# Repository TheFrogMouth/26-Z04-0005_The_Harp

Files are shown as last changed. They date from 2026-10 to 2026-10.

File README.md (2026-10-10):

# 26-Z04-0005 — The Harp

Frogmouth digital sympathetic-string guitar pedal. Up to 24 modelled strings
that nobody plays ring when the guitar sounds their note, retuned continuously
to the chord being played. STM32H750VBT6, AK4621EF codec, no SDRAM, relay
bypass, in a Hammond 125B on the Alchemist/Relic board and jack layout.

Status: **first schematic draft, board placed and mostly routed, 29 connections open.** Seven sheets generated from the Timekeeper's circuits and The Relic's bypass (190 parts, net-traced, drawn to the Frogmouth schematic standard, not yet opened in KiCad); board outline and 28 face/jack/bypass footprints placed from The Relic. Stereo in (TRS) and a 0.91 in OLED display added 2026-10-08; the PCB was synced to the schematic and every part placed on both sides on 2026-10-08 (scripted; one-board fit confirmed, see `docs/pcb-plan.md` *Placement*). First routing pass by script on 2026-10-09: GND to In1 and rails on In2 from every pad, analog and digital kept apart. Opened in KiCad 2026-10-10 (now the source of truth): power section re-placed and re-routed, every track at the Alchemist widths and at 0/45/90°, 29 connections left for KiCad (*Routing*). See `docs/pcb-plan.md` and `kicad/README.md`.

## Layout

| Path | Contents |
|---|---|
| `docs/design-brief.md` | What the pedal is, engine, controls, bypass, cost target, decisions, open items |
| `docs/pcb-plan.md` | One-board plan and two-board fallback, face schedule, zoning, schematic sheets, pin budget, order of work |
| `docs/firmware-requirements.md` | Firmware requirements (draft): audio path, engine, controls, display, bypass, persistence, budgets, verification |
| `kicad/the_harp/` | KiCad 10 project: seven-sheet schematic, Relic-outline board |
| `Gerbers/` | Fabrication output, when generated |
| `firmware/the_harp/` | STM32H750 firmware |
| `Documents/` | Controlled LaTeX documents, one folder each |
| `bom/` | Generated BOM (`scripts/export_bom.py`, to be adapted from The Relic) |
| `scripts/harp_schematic/` | Schematic generator and net checker (first draft only; see its README) |
| `scripts/pcb_placement/` | PCB sync to the schematic and scripted placement (2026-10-08; see its README) |
| `scripts/oled_drawings/` | Face cut-out and OLED-to-PCB drawings in `docs/images/` |

The layout is the Frogmouth product repository standard
(`docs/repo-structure.md` in 26-F01-0001_Frogmouth).

## Conventions

Same as The Relic and The Alchemist: enclosure centre is the PCB drill/place
and grid origin at (148.5, 105); face X right, face Y up; jacks on the board
underside at the Alchemist's positions and heights; pots on the board;
momentary footswitches wired to pads; relay true bypass.

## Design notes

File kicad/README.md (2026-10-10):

# KiCad project — The Harp

`the_harp/` is the KiCad 10 project. The board was seeded from The Relic
(2026-10-04); the schematic is **generated** by
`scripts/harp_schematic/build_layout.py` from the circuits of the Timekeeper
DSP board and The Relic's relay bypass (`harp_spec.py`) and a hand layout per
sheet (`layouts/`), drawn to the Frogmouth schematic standard
(`docs/schematic-standard.md` in 26-F01-0001_Frogmouth, 2026-10-07). Nothing
here has been opened in KiCad yet: run ERC first.

## Sheets

| Sheet | File |
|---|---|
| Root | `The Harp.kicad_sch` |
| Controls and LEDs | `Controls and LEDs.kicad_sch` |
| MCU (STM32H750VBT6, W25Q128) | `MCU.kicad_sch` |
| Power | `Power.kicad_sch` |
| Jacks and Bypass | `Jacks and Bypass.kicad_sch` |
| Codec (AK4621EF) | `Codec.kicad_sch` |
| ADC Driver (THS4522) | `ADC Driver.kicad_sch` |
| Analog In and Out (OPA1656, OPA1688) | `Analog In and Out.kicad_sch` |

What each sheet holds, the pin map and the deliberate differences from the
Timekeeper are in `docs/pcb-plan.md`. The Relic's `Power and IO` sheet is
gone: its relay bypass is redrawn on Jacks and Bypass with the same
designators, and its regulators are replaced by the Timekeeper's buck and LDO.

## Board

The Relic's 56 × 90 mm outline with the DC tab, four-layer stack, GND zone
and 125B guides. 26 footprints are placed: the four pots, three toggles, the
effect LED, the five jacks (DC, IN, OUT L, OUT R, EXP), the relay and its
driver, the effect-LED driver and the bypass footswitch pads. The four
1/4 in jacks and the relay were replaced on 2026-10-05 with The Alchemist's
NMJ6HCD2 and G6K-2F-Y footprints at its positions. On 2026-10-06 the face
moved to The Alchemist's layout: RV104 and RV106 removed, the three toggles
on the Taiway 100-DP6 footprint at (−20, +13), (0, −5) and (+20, +13) (Retune moved to (0, −24) on 2026-10-09), the
bypass footswitch on hand-solder pads, and R405 / D402 moved off J403's
rear pads. The Relic's
regulator parts (C401–C407, D401, R401–R403, U401, U402) were removed. On
2026-10-08 the board was synced to the schematic (see step 2 below): every
footprint is linked to its symbol with its pad nets, the twelve note LEDs
and their resistors are gone. All 181 footprints were then placed on the
top side by script (`scripts/pcb_placement/`, `docs/pcb-plan.md` *Placement*).

## First steps in KiCad

1. Open `The Harp.kicad_pro`, open every sheet once, run ERC. Expect
   cosmetic warnings (label placement, overlapping text); anything about
   power pins or unconnected pins is real, report it.
2. The board was synced to the schematic on 2026-10-08 without KiCad (no
   KiCad in that session): 181 footprints (190 symbol units), each linked to its symbol, values
   and pad nets checked pin by pin against `harp_spec.py`. Run Tools → Update PCB from
   Schematic once anyway: it should report no changes apart from net
   renames (KiCad names unlabelled nets `Net-(...)`) and footprint library
   refreshes. Anything else it reports is a sync miss: note it.
3. Every part is placed on both sides (scripted, 2026-10-08; see *Placement*
   in `docs/pcb-plan.md`). Look it over, then run DRC.
4. The board was routed by script on 2026-10-09 (`scripts/pcb_routing/`,
   *Routing* in `docs/pcb-plan.md`): GND vias per the Relic rule, rails on
   In2. On 2026-10-10 the power section was re-placed and re-routed and
   every track brought to the Alchemist widths (0.254 / 0.508 / 0.762 /
   1.0 mm, digital 0.1524) and to 0/45/90°. Fill the In1 GND zone (B), finish the 29 open
   connections listed there, then DRC. The net classes (GND, Rail, Power,
   Audio, Digital, Control, clearance 0.1524) are in the project.

Once the schematic has been edited in KiCad, the KiCad files are the source
of truth; do not re-run the generator over them (see
`scripts/harp_schematic/README.md`).

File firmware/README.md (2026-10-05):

# Firmware

`the_harp/` will hold the STM32H750VBT6 firmware (string bank, chord tracker,
tuning manager). The engine is prototyped first on the Timekeeper board
(`25-Z01-0001_DSP_Development_Board/firmware/dsp_development_board`), then
ported with the Harp pin map. See `docs/design-brief.md` for the engine and
`docs/firmware-requirements.md` for what the firmware must do.

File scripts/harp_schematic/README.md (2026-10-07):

# Schematic generator

Writes the Harp's KiCad 10 schematic from a plain Python description of the
circuit (`harp_spec.py`) and a hand layout per sheet (`layouts/`), in the
style of `docs/schematic-standard.md` in 26-F01-0001_Frogmouth: every
connection inside a sheet is a wire, global labels only for nets that leave
the sheet, a power symbol at each rail and ground point, Oswald on every
font, power symbols numbered uniquely across the project, and a coloured
block diagram on the top sheet.

| File | What it is |
|---|---|
| `harp_spec.py` | The circuit: every part, its value, footprint, manufacturer part number and the net on each pin, sheet by sheet |
| `schgen.py` | Writes `.kicad_sch` files: each pin gets a 2.54 mm stub and a power symbol, a global label (net on more than one sheet) or a local label; unused pins get a no-connect flag |
| `kisch.py` | Minimal schematic reader and net tracer, used to check the output |
| `build_layout.py` | **The build.** Runs the sheet layouts into `kicad/the_harp/`, numbers the power symbols, writes the top sheet, then re-reads every sheet, traces the nets and compares them pin by pin with the spec, and runs the layout checks |
| `layout.py` | The layout engine: places parts on the grid, draws wires, power symbols, labels and no-connects, splits wires at the pins they meet, adds junctions, and checks for dangling wires, wires through bodies, overlapping wires, crossings and overlapping text |
| `layouts/<sheet>.py` | One hand layout per sheet (`power.py`, `mcu.py`, ...); `layouts/common.py` has the shared helpers |
| `top_sheet.py` | The top sheet: sheet blocks coloured by domain, domain frames, connection lines, legend, and the embedded title block and Oswald fonts (copied from The Relic's top sheet) |
| `render_png.py` | Preview renderer (Pillow, no KiCad needed): `python3 render_png.py SHEET.kicad_sch out.png [px_per_mm]`. Set `FONT_DIR` to a folder with `Oswald-Regular.ttf` / `Oswald-Bold.ttf` for the real face |
| `build.py` | The first-draft generator (every pin on a labelled stub); superseded by `build_layout.py`, kept for reference |
| `symbols.sexpr` | The 34 symbol definitions used, copied from the Timekeeper, Relic and Alchemist schematics and KiCad's `STM32H750VBTx` |
| `libcollect.py`, `h750vb.kicad_sym` | Only needed to rebuild `symbols.sexpr` (delete it and run `build.py` with the sibling repos checked out next to this one) |

```bash
python3 scripts/harp_schematic/build_layout.py          # every sheet and the top sheet
python3 scripts/harp_schematic/build_layout.py Power    # one sheet (no power renumbering, no top sheet)
# Power   parts 24 wires 65 junctions 20 crossings 0 netlist OK layout OK
```

`netlist OK` means every pin is on the net the spec gives it, every rail
and global net carries its name, no node holds two nets, and no local
label is used except the ones a layout declares in `allow_local` (the MCU
sheet: `QSPI_CLK` and `QSPI_NCS`, whose ends sit on opposite sides of the
MCU). Each crossing is listed; a sheet should have none or very few.

Sheet and symbol UUIDs are derived from the sheet name and reference, so a
rebuild keeps the links to the PCB.

**The generator owns the schematic only until someone edits it in KiCad.**
After that, the KiCad files are the source of truth and running `build_layout.py`
would overwrite those edits. Use it again only for a deliberate full
regeneration, with the spec and the layouts updated to match.

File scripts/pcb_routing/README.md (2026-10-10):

# PCB routing scripts

Used on 2026-10-09 to route `kicad/the_harp/The Harp.kicad_pcb` without
KiCad: the board goes to Freerouting as a Specctra DSN, one net class at a
time, and the session comes back into the board file as tracks and vias.
Once the board has been edited in KiCad, KiCad is the source of truth:
rerun these only for a deliberate restart (they replace every track and via).

| File | What it does |
|---|---|
| `route.py` | Runs the phases in order (below) and writes `build/routes.json`. With phase names, reruns those on top of the rest. |
| `fanout.py` | Gives every SMD pad of a net set its own via and a straight stub (GND and the rails). |
| `regions.py` | The audio and digital regions per layer, from where the pads are; used as keepouts. |
| `dsn.py` | Writes the DSN (each footprint its own image, pads pre-rotated, earlier phases protected) and reads the SES. |
| `nets.py` | Net classes: what each net is, its width and clearance, the via. |
| `write_tracks.py` | Replaces the board's tracks and vias with `build/routes.json`. |
| `check.py` | Stand-in for DRC: connectivity (GND through the plane), clearances per class, copper to edge, hole to hole. |
| `render.py` | Draws F.Cu, B.Cu and In2.Cu with tracks coloured by class. |
| `netclasses.py` | Writes the same classes into `The Harp.kicad_pro` (one pattern per net) for KiCad's DRC and router. |
| `kpcb.py` | Board-file reader: footprints, pads in board coordinates, outline. |
| `power.py` | Places and routes the power section (y < 70) by hand, in code: the DC input row, the LDO row, the buck's feedback divider; 0/45/90 only. Keeps the owner's buck placement. Safe to rerun on a KiCad-saved board: it only replaces the power nets' copper above y = 70. |
| `rail.py` | Joins the open pieces of one rail (`rail.py +5V`): octilinear A* on In2.Cu, hopping onto F/B with a via pair where another rail is in the way. |
| `widths.py` | Brings every track to its class width (stepping down where the clearance will not allow it) and every segment to 0/45/90. Safe to rerun. |
| `fill.py`, `smooth.py` | Grid maze router for the connections Freerouting left open, and a straightener for its staircases (2026-10-09; not used since). |

Widths are the Alchemist's: 1.0 (DC input, SW), 0.762 (rails, local power),
0.508 (GND stubs, VDDA), 0.254 (audio, control), 0.1524 (digital, 6 mil as
on the DSP board), NRST 0.1016; clearance 0.1524.

Phases (`route.py`):

1. **gnd**: every SMD GND pad gets its own via to the In1.Cu plane (Relic
   rule). ICs put the via under the package, two-pin parts off the free end.
2. **rails**: every SMD pad on +3V3, +5V, +9V gets its own via; Freerouting
   joins the vias on In2.Cu, the only layer the rails may use.
3. **power**: local power nets (buck, LDO, DC input, VDDA, relay coil, LED
   current), wide, F/B.
4. **core**: digital round the MCU (codec interface, QSPI, crystal, SWD,
   OLED, reset), kept out of the audio region.
5. **audio**: kept out of the digital region; before the long digital lines
   so the bypass paths get the corridors under the MCU to the relay.
6. **drive**: the LED and relay drive lines to the bottom-side drivers, kept
   out of the audio region.
7. **ctrl**: pots, toggles, footswitches, expression (DC), kept out of the
   audio region.
8. **repair**: anything still open, without the region keepouts and with the
   signal tracks unlocked so the router can move them; GND, rail and power
   copper stays fixed.

Signals never use In2.Cu; vias cost more than Freerouting's default (80
against 50), so a track changes side rarely; much higher and it takes long
one-sided detours instead. No via within 0.6 mm of the SWD needle pads.

Needs Java 25 and Freerouting 2.4.1 (`app.freerouting:freerouting`,
`freerouting-2.4.1-executable.jar` from Maven Central), plus Python with
shapely, numpy, scipy and matplotlib:

```bash
cd scripts/pcb_routing
FREEROUTING=/path/freerouting-2.4.1-executable.jar JAVA=/path/java25 python3 route.py
python3 write_tracks.py && python3 check.py && python3 render.py
```

Freerouting quirks found on the way: any `autoroute_settings` block in the
DSN makes it see nothing to route (so per-layer costs are not used; In2 is
reserved by net class instead), and with an In1 plane declared it counts GND
as done and will not fan it out (so `fanout.py` does that). A full run takes
about an hour and a half on four cores. The 2026-10-09 run left 32
connections open (`docs/pcb-plan.md`, *Routing*).

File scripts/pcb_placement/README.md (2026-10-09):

# PCB sync and placement scripts

Used on 2026-10-08 to do, without KiCad, what *Update PCB from Schematic*
and a first placement pass would do. They edit
`kicad/the_harp/The Harp.kicad_pcb` in place. Once the board has been
edited in KiCad, KiCad is the source of truth: rerun these only for a
deliberate restart.

| File | What it does |
|---|---|
| `sync_pcb.py` | Brings the board in line with `harp_spec.py`: removes footprints no longer in the schematic, adds new ones (cloned from footprints already on this board or the Timekeeper's), sets values and pad nets, links each footprint to its schematic symbol. New parts are parked off the board. |
| `run_place.py` | Places every part on its group's side: fixed face parts stay, U201 goes at (0, −7) (option 1: under the OLED; Retune toggle at (0, −24)), each group gets a home position and each passive the nearest free spot to the pads it connects to (decoupling first, bias nets ignored, anti-alias caps at the codec pins). Avoids courtyards on its side, through-holes from the other side, the board edge and, for tall parts, the OLED module. Writes `build/pos.json`. |
| `write_pos.py` | Writes `build/pos.json` into the board file: position, rotation and side (flips a footprint as KiCad does). |
| `verify.py` | Re-reads the board file: courtyard overlaps per side, parts on through-holes from the other side, parts outside the outline, tall parts under the OLED, and that every pad sits where the placer put it. |
| `metrics.py` | Key net lengths and the total, for comparing runs. |
| `render_place.py` | Draws the placement: `CHROME=/path/to/chrome python3 render_place.py ../../docs/images/pcb-placement`. |
| `place.py`, `geom.py`, `pcbread.py` | Shared helpers: footprint geometry, the placer, board-file and spec readers. |

```bash
cd scripts/pcb_placement
python3 run_place.py && python3 write_pos.py && python3 verify.py
```

The placement is greedy and deterministic. Its result and its weak spots
are written up in `docs/pcb-plan.md`, *Placement*.

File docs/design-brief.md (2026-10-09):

# The Harp — design brief

Working title. Project number to be assigned. Written 2026-10-04 from the
concept discussion. Companion to `pcb-plan.md` (board, placement and
schematic sheet plan). Format follows The Relic's `docs/design-brief.md`.

## What it is

A sympathetic-string pedal. Behind the guitar sit up to 24 digitally
modelled strings that nobody plays: they ring when the guitar sounds a note
they are tuned to, as the taraf strings of a sitar or the under-strings of a
Hardanger fiddle do. The pedal listens to the chord being played and keeps
retuning the strings to it, so every note leaves a halo that is in the
player's own harmony. Tuned ambience, not reverb and not shimmer.

The category neighbours are Hologram Microcosm, Chase Bliss Mood and the
Strymon ambience pedals (300 to 450 EUR). Nothing in that category does
chord-following sympathetic strings.

## Why this hardware

The Harp is a cut-down Timekeeper on the Alchemist/Relic 125B hardware set:

- Same codec, flash, buck converter, input and output stages and relay
  bypass as the Timekeeper and the Relic, so the schematic is mostly copied.
- **No SDRAM.** The 24 strings need about 100 KB of delay memory; the
  STM32H750 has 1 MB internal. This removes the external memory bus and
  about 60 pins of MCU.
- **STM32H750VBT6, LQFP-100** instead of the Timekeeper's LQFP-144. Same
  core, same firmware, new pin map.
- **No TFT.** A thin 0.91 in 128×32 I²C OLED strip replaces the screen (decision 14, 2026-10-08).
- **Pots, not encoders.** Encoders only make sense with a screen that shows
  the value; the Timekeeper has one, this does not. Pots also keep the
  Relic's parts and feel. The H750 reads the four of them on ADC1 PA0,
  PA1, PA2 and PA4, with the DMA scan the Timekeeper's `controls.c`
  already runs.
- **Jacks and DC jack in the Alchemist's positions and heights.** See
  `pcb-plan.md`; this is the main reason the design is one board.

## Signal path

```
IN tip -> relay -> input buffer -> ADC (codec L) -> H750: chord tracker
                                                       string bank x24  -> DAC L -> out buffer -> relay -> OUT L
                                                       dry + wet mix    -> DAC R -> out buffer -> relay -> OUT R
IN ring -> input buffer -> ADC (codec R) -> H750 (mono plug: copy L)
EXP (TRS) -> buffer -> H750 ADC
```

Stereo in, stereo out, single-ended at every jack. IN is one TRS jack,
tip = left, ring = right; both channels are buffered (OPA2365 halves) and
driven into the AK4621EF's differential inputs by the two channels of the
THS4522, exactly as the Timekeeper does. A mono plug shorts the ring to the
sleeve, so the right channel reads silence; the firmware copies left to
right until the right channel carries signal. The relay isolates the left
input only, the right is muted by the DSP in true bypass. The dry signal goes through the codec: the
pedal's whole point is the wet sound, and converting the dry keeps the mix,
trails and output level in firmware. Latency is one block (about 6 ms at
44.1 kHz / 256 samples, as the Timekeeper).

## Engine

| Block | What it does | Reuse |
|---|---|---|
| String bank | 24 Karplus-Strong / waveguide strings, each a fractional delay line with a one-pole loss filter and an allpass for tuning. Guitar signal feeds each string through a narrow resonant band-pass at the string's pitch so a string only rings when its note or an overtone is played. No envelope trigger. | New |
| Jawari | Nonlinear bridge: a soft clip plus a short extra delay tap in the loop, depth on the Jawari knob. Zero is a harp, full is a sitar. | New |
| Chord tracker | FFT of the input (the Timekeeper's spectral bank already has the analysis), chroma vector, template match to a chord set with hysteresis. Only chords that last more than ~400 ms retune the strings. | Timekeeper spectral |
| Tuning manager | Assigns string pitches from the chord (Follow), a fixed key (Key) or an open tuning set (Drone, stacked fifths among the sets). Snap retunes only silent strings; Glide slides sounding strings to the new pitch; Lock stops retuning. | New |
| Stereo spread | Strings panned low-left to high-right. | New |
| Front end | Hum filter and noise gate before the strings. | Timekeeper |
| Framework | Effect chain, presets in QSPI flash, control smoothing, expression, UI simulator. | Timekeeper |

CPU: 24 strings at 44.1 kHz is a few MIPS each; the Timekeeper's spectral
bank alone is heavier. Comfortable on the H750 at 480 MHz, but **not yet
measured**.

## Controls

125B face laid out as The Alchemist's: 20 mm columns −20 / 0 / +20, rows
+38 and +13 (the same 20 × 25 mm pitch as The Gremlin and the Timekeeper),
plus one toggle at (0, −24) (moved from (0, −5) on 2026-10-09 to make room for the OLED); 12.5 mm knobs. Nothing through-hole sits over
the upper jacks (`pcb-plan.md`). The toggles are The Alchemist's Taiway
100-DP6 ON-ON-ON, so each one stages the effect in three steps.

| Position (face X, Y) | Control | Notes |
|---|---|---|
| (−20, +38) knob | Mix | Dry/wet |
| (0, +38) knob | Sustain | String decay time |
| (+20, +38) knob | Strings | 6 to 24 active strings |
| (−20, +13) toggle | Tuning | Follow / Key / Drone (key and drone set in the secondary layer) |
| (0, +13) knob | Jawari | Bridge buzz |
| (+20, +13) toggle | Brightness | Dark / Warm / Glassy loss-filter voicings |
| (0, −24) toggle | Retune | Snap / Glide / Lock |
| window at (0, −5) | 0.91 in OLED strip | Note names the strings are tuned to, chord, mode and the value of the knob last moved; behind a window in the face |
| (−20, −35) | Effect LED | |
| (−20, −49) | Bypass footswitch | Momentary SPST-NO soft-touch, wired to hand-solder pads |
| (+20, −49) | Hold footswitch | Freezes the tuning and sets infinite sustain while held or latched |
| right wall | IN, EXP | Alchemist jack positions |
| left wall | OUT L, OUT R | Alchemist jack positions |
| top wall | DC | Alchemist DC position |

All four pots and the three toggles go to the MCU; none is in the audio
path. There is no screen, so secondary settings (key, drone set, bypass
mode True / Trails, expression target Bend / Swell, latch behaviour) are
set by a footswitch gesture and a knob, with the OLED strip as the display.

## Bypass

Relay true bypass, one relay, The Relic's circuit (decision 7 in its brief)
with The Alchemist's relay: Omron G6K-2F-Y (DC5, 5.2 mm tall, SMD) driven by
a 2N7002 from the MCU, 5 V coil from +9V through 150 Ω, pull-down keeps it
off through boot. Pole A
switches OUT L between IN and the DSP; pole B disconnects the input buffer
from IN and grounds it. **OUT R is silent in true bypass**; stereo players
use Trails mode, where the relay stays energised and the DSP passes dry on
both outputs while the strings ring out. The pedal passes signal to OUT L
unpowered. Before every relay change the DSP fades its outputs to silence,
switches, waits for the contacts, and fades back in; no mute transistor.

## Cost target

Against The Relic's estimate (46.20 EUR at 100) the electronics roughly
double and the rest is the same:

| Group | EUR |
|---|---:|
| H750, codec, flash, buck, LDO, op-amps, passives | 22.00 |
| 4 pots, 3 ON-ON-ON toggles, 2 momentary footswitches, 4 knobs, 2 LEDs + 0.91 in OLED module (replaces 12 LEDs and 12 light pipes; price to confirm) | 19.00 |
| 5 jacks, relay, footswitch pads | 7.00 |
| 125B, Tayda drilled and UV printed | 9.20 |
| PCB (4-layer), SMT assembly, freight, packaging allocation | 9.00 |
| Estimate | 66.00 |

At 299 EUR, which the category supports, roughly 165 EUR gross before
labour. Nothing carted.

## Decisions taken on 2026-10-04

1. **One relay, true bypass on OUT L only**, Trails mode in firmware for
   stereo use. Two relays rejected as a cost and current increase for a
   case most players do not have.
2. **One board**, Alchemist outline, jacks and pots on it, unless the
   placement in `pcb-plan.md` does not fit; the fallback is a two-board
   stack with the face board keeping the jacks (see that document).
3. **Pots, not encoders.**
4. **Twelve top-side SMD LEDs with 3 mm light pipes** for the note display. *Superseded by decision 14.*
   They sit over the jack bodies, where through-hole parts are not allowed.
5. **STM32H750VBT6 (LQFP-100), no SDRAM.** Everything else in the digital
   and audio chain is the Timekeeper's.
6. **Dry through the codec.** No analog dry path.
7. **One face standard with The Alchemist and The Relic**: the same knob,
   toggle, jack, DC, LED and footswitch coordinates, each pedal using the
   subset it needs (table in `pcb-plan.md`).
8. **QUADSPI on bank 2** (PB2, PC11, PE7–PE10), so SAI1 keeps the
   Timekeeper's PE2–PE6 and the audio firmware ports unchanged.
9. **Mono in, stereo out** in hardware: one input buffer and one ADC driver *(superseded by decision 15: stereo in)*
   channel; the codec's right ADC input is parked at VCOM.
10. **Input op-amp OPA2365 on the 5 V rail** (zero-crossover rail-to-rail
    input), replacing the Timekeeper's OPA1656, whose input stops 2.25 V
    below the rail. With the Timekeeper's H2 fix (R705 49.9 Ω, R602 1.05 kΩ)
    and R603/R604 at 620 Ω, the gain from the jack to the ADC is 0.59, so a
    4.8 Vpp input just reaches full scale: guitar and synth both fit.
    Decided 2026-10-05; 9 V for the buffer was ruled out.
11. **No line/synth input pad.** The input takes up to 4.8 Vpp (about
    +7 dBu), in line with most Strymon pedals (+8 dBu). A +4 dBu synth
    peaks near −3 dBFS. Hotter sources (Eurorack at about 10 Vpp, a synth
    at full volume) are turned down at the source, or go through a passive
    inline attenuator, before the pedal. A switchable pad (as on the Strymon
    Night Sky, Eventide H90 or Meris pedals) was considered and rejected: it
    would put a switch at the high-impedance input, in the audio path, for a
    case the source's own volume control already covers. Decided 2026-10-05.
12. **Shared parts follow The Alchemist** (its main branch, 2026-10-05):
    Neutrik NMJ6HCD2 jacks (11.4 mm wall holes, same axis heights), Omron
    G6K-2F-Y relay, Alpha RD901F-40-15R1-B10K pots, Kingbright WP710A10ID
    panel LEDs fitted at final assembly, soft-touch footswitches on
    hand-solder pads, IN jack ring to ground. Each shared symbol carries
    the design part and the JLCPCB part (`LCSC`, `JLCPCB Manufacturer`,
    `JLCPCB Part #`) The Alchemist records.
13. **Face as The Alchemist's** (2026-10-06): four knobs (Mix, Sustain,
    Strings, Jawari) and three Taiway 100-DP6-T200B1M2QE ON-ON-ON toggles,
    Tuning (Follow / Key / Drone) and Brightness (Dark / Warm / Glassy) at
    (±20, +13) and Retune (Snap / Glide / Lock) at (0, −5). The Relic's six
    knobs and three toggles did not fit four jacks: the outer lower-row
    pots' pins land on the upper jacks' rear pads and the outer toggles sit
    over the jack bodies. Each toggle is read on two MCU inputs. Bypass mode
    and expression target move to the secondary layer; Fifths becomes a
    drone set.

## Still open

- Secondary layer: it now holds more settings than there are knobs (key
  or drone set, spread, bypass mode, expression target and range, Hold
  latching, Brightness trim, chord commit time, output trim). Pick a second
  page or drop some, on the prototype.
- [CONFIRM] items on the schematic: QUADSPI bank 2 alternate functions
  (the AK4621's right input and the THS4522's second channel are now used,
  so those two items are closed).
- OLED: choose the module (36–38 × 12–12.5 mm envelope, I²C, 3.3 V) and
  measure it; the 24.4 × 7.6 mm window and the face-mounted carrier follow
  from it (`pcb-plan.md`, *OLED mounting*). I²C address and refresh budget
  in firmware.

- Chord tracker quality on distorted or fast playing. Key and Drone modes do
  not depend on it, so the pedal works even if Follow is weak.
- Display: decided on 2026-10-08, a 0.91 in I²C OLED strip behind a
  Tayda rectangular cut (above).
- The Alchemist's side-wall and top-wall hole heights are still to be fixed
  from the NMJ6HCD2 and PJ-063AH drawings and the board depth; The Harp
  inherits whatever is measured.
- Expression jack: TRS wiring and buffer as the Timekeeper (MCP6001).
- Firmware prototype first: the whole engine can be developed and tested on
  the Timekeeper board before any Harp PCB exists.

## Risks

- Codec and H750 near a high-impedance guitar input on one 56 × 90 mm board.
  Mitigation: The Relic's four-layer stack with one unbroken ground plane,
  zoning in `pcb-plan.md`, buck converter at the DC end away from the input.
- AK4621EF lifecycle (already flagged in the Timekeeper's BOM audit).
- One-board fit (Plan A): every part fits after the 2026-10-08 placement, with 37 non-critical parts on the bottom side (`pcb-plan.md`, *Placement*). Those need double-sided assembly or hand fitting.

## Decisions taken on 2026-10-08

14. **A 0.91 in 128×32 I²C OLED strip replaces the twelve note LEDs and
    their light pipes** (J408, PB6 SCL / PB7 SDA, 4.7 kΩ pull-ups). PD0–PD11
    are freed. Supersedes decision 4. The module is held by a 3D-printed
    carrier bonded under the face, behind a 24.4 × 7.6 mm Tayda rectangular
    cut centred at (0, −5) (decision 16), and wired to J408 by a 4-wire lead
    (`pcb-plan.md`, *OLED mounting*).
15. **Stereo in, single-ended at the jacks, stereo out.** IN is a TRS jack
    (tip left, ring right); the right channel gets its own OPA2365 half and
    the second THS4522 channel into AINR, so the AK4621's inputs are never
    parked. The AK4621EF has no single-ended mode (its inputs are fully
    differential); the Timekeeper's single-ended-to-differential THS4522
    driver does that job. A mono plug is detected by the right channel
    reading silence. Supersedes decision 9.

## Decisions taken on 2026-10-09

16. **OLED in the middle of the face, Retune toggle below it (option 1).**
    The OLED window moves from (0, −20) to (0, −5), centred under the Jawari
    knob and away from the footswitches; the Retune toggle moves from
    (0, −5) to (0, −24). On the board the H750 moves up under the screen to
    (0, −7) and the codec sits beside it (`pcb-plan.md`, *Placement*). The
    module is mounted turned round (pads at its right end); the firmware
    flips the image.

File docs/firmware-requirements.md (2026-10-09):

# The Harp — firmware requirements

Draft A, 2026-10-04. Companion to `design-brief.md` (what the pedal is) and
`pcb-plan.md` (pin budget, sheets). This document says what the firmware in
`firmware/the_harp/` must do; it does not say how. Where the brief leaves a
value open, the number here is a **proposal** marked *(TBC)* and is settled
on the Timekeeper prototype (section 14).

Sources: the design brief and PCB plan in this repo, and the Timekeeper
firmware it reuses
(`25-Z01-0001_DSP_Development_Board/firmware/dsp_development_board/`):
`audio_fx.h` (chain and ISR hand-off), `controls.c` (ADC1 scan),
`fx_spectral.c` (STFT), `fx_humfilter.c`, `fx_noisegate.c`, `preset.c`
(QSPI slots), `AK4621EF.c`, the IWDG and crash record in `main.c`, and the
host test suite in `tests/run_tests.sh`.

## 1. Conventions

- **Shall** is a requirement, **should** a goal, **may** a permission.
- Each requirement has an ID (`AUD-3`, `STR-5`, …) so tests, commits and
  issues can cite it. IDs are never reused; a dropped requirement is struck
  through, not deleted.
- **Verification** column: **T** host unit test (runs in `tests/`), **B**
  bench measurement on hardware, **L** listening test, **I** inspection of
  code or build output, **A** analysis.
- **Priority**: **1** needed for the first Harp hardware build, **2** needed
  for release, **3** wanted.
- Face positions and designators are those of `pcb-plan.md`.

## 2. Scope

In scope: everything that runs on the Harp's STM32H750VBT6, i.e. the audio
engine, controls, note display, relay bypass, persistence, start-up, fault
handling and the production test mode, plus a build of the same engine on
the Timekeeper board for prototyping.

Out of scope for the first release: MIDI (the spare UART is reserved for
it), the codec's second ADC channel as an aux input, a USB or other
field-update path, and an OLED display (open item in the brief).

## 3. Platform

| ID | Requirement | Ver. | Pri. |
|---|---|---|---|
| PLT-1 | Target is the STM32H750VBT6 (LQFP-100) at 480 MHz with the FPU and I/D caches on, no external SDRAM. | I | 1 |
| PLT-2 | Every audio buffer, delay line and FFT work area shall live in internal RAM (DTCM 128 KB, AXI SRAM 512 KB, D2 288 KB, D3 64 KB). DMA buffers shall not be placed in DTCM, which no DMA reaches. | I | 1 |
| PLT-3 | The image shall fit the H750's 128 KB internal flash, with at least 16 KB free at the first Harp build. If it does not, the fallback (execute from QSPI in memory-mapped mode, or a loader in internal flash) is a decision to raise, not to take silently. | I | 1 |
| PLT-4 | One source tree shall build for two boards: `BOARD_HARP` and `BOARD_TIMEKEEPER`. Pin maps, the relay polarity, the LED driver and the codec wiring are selected by a board header; the engine and control logic are identical on both. | I | 1 |
| PLT-5 | Every DSP and control-logic module shall build and run on a desktop compiler with no HAL, no CMSIS and no heap, as the Timekeeper's modules do, so the engine is testable without hardware. | T | 1 |
| PLT-6 | No dynamic allocation after start-up. All buffers sized for the maximum (24 strings) at compile time. | I | 1 |
| PLT-7 | Toolchain: STM32CubeIDE / arm-none-eabi-gcc as the Timekeeper; host tests with gcc `-Wall -Wextra -Werror`. | I | 1 |

## 4. Audio path

| ID | Requirement | Ver. | Pri. |
|---|---|---|---|
| AUD-1 | AK4621EF over SAI1, 44.1 kHz, 24-bit, codec configured over I2C1, using the Timekeeper's driver. | B | 1 |
| AUD-2 | Input is the codec's two ADC channels (L from the IN tip, R from the IN ring). If R carries no signal (mono plug: ring grounded) for ≥ 2 s *(TBC)*, L is copied to R; otherwise L and R are processed as a stereo pair. The DAC drives OUT L and OUT R. | B | 1 |
| AUD-3 | Processing runs in the SAI DMA half/complete callbacks on blocks of the Timekeeper's size (64 frames, `AUDIO_BUFFER_SIZE` 256 half-words). | I | 1 |
| AUD-4 | Dry path: the dry signal shall pass the DSP at unity gain (±0.1 dB) with no processing other than the mix, the bypass fades and the output limiter. The front end (hum filter, gate) applies to the string feed only, not to the dry. | T, B | 1 |
| AUD-5 | Input-to-output latency of the dry path shall be ≤ 3 ms, measured jack to jack *(TBC on the bench; 64-frame blocks with double buffering plus the codec filters should give about 2.5 ms)*. | B | 1 |
| AUD-6 | The output shall never clip digitally. A wet-bus limiter (ceiling −1 dBFS *(TBC)*) shall act before the DAC, and the wet level shall be normalised for the number of active strings so that the Strings knob changes density, not loudness, by more than ±3 dB. | T, L | 1 |
| AUD-7 | Denormals flushed (FPU FZ set); any string whose state goes non-finite is reset to silence within one block and counted in a diagnostic. | T | 1 |
| AUD-8 | Output noise floor with Mix fully wet and no input shall be no worse than the Timekeeper's measured floor plus 3 dB. | B | 2 |
| AUD-9 | No audible click or zipper noise from any knob, toggle, footswitch, retune or mode change. | L | 1 |

Note: the brief gives the latency as "one block, about 6 ms at 44.1 kHz /
256 samples". The Timekeeper's `AUDIO_BUFFER_SIZE` is 256 half-words of
interleaved stereo, i.e. 64 frames per DMA half, about 1.5 ms. AUD-5 uses
the smaller figure; the brief should be corrected once it is measured.

## 5. Engine

### 5.1 Front end

| ID | Requirement | Ver. | Pri. |
|---|---|---|---|
| FE-1 | Hum filter and noise gate from the Timekeeper, in that order, on the signal that feeds the strings and the chord tracker. | T | 1 |
| FE-2 | The gate shall close the string feed only; strings already ringing decay naturally. | T | 1 |

### 5.2 String bank

| ID | Requirement | Ver. | Pri. |
|---|---|---|---|
| STR-1 | Up to 24 strings, each a waveguide / Karplus-Strong loop: fractional delay line, one-pole loss filter, tuning allpass. | T | 1 |
| STR-2 | Pitch range of the bank C2 (65.4 Hz) to C6 (1047 Hz) *(TBC)*. Delay memory sized for the lowest pitch plus the Jawari tap and interpolation margin; about 24 × 700 samples × 4 bytes ≈ 70 KB, inside the brief's 100 KB. | A, I | 1 |
| STR-3 | Tuning accuracy ±2 cents across the range, at every Brightness setting (the loss filter's phase delay is compensated). | T | 1 |
| STR-4 | Excitation: the front-end signal reaches each string through a resonant band-pass at the string's pitch. A string shall respond to a played note whose fundamental or a low partial (up to the 4th *(TBC)*) coincides with its pitch, and stay at least 20 dB *(TBC)* quieter for a note a semitone away. No envelope or onset trigger. | T, L | 1 |
| STR-5 | Sustain sets the string decay, T60 from 0.5 s to 20 s *(TBC)*, log taper. Infinite sustain (Hold) shall be stable: string energy bounded, no runaway, indefinitely. | T | 1 |
| STR-6 | Brightness (SW103) selects one of three loss-filter voicings, **Dark / Warm / Glassy**, roughly 1.2 kHz / 4 kHz / 10 kHz cutoff *(TBC by ear)*, without changing pitch (STR-3) or, by more than 3 dB, level. A change cross-fades over 50 ms *(TBC)* with no click (AUD-9). | T, L | 1 |
| STR-7 | Strings sets 6 to 24 active strings in steps of 1. Strings removed fade out over ≥ 50 ms; strings added start silent. Which strings drop is set by the tuning manager (TUN-6). | T | 1 |
| STR-8 | Inactive strings cost no CPU beyond a branch. | I | 2 |

### 5.3 Jawari

| ID | Requirement | Ver. | Pri. |
|---|---|---|---|
| JAW-1 | Nonlinear bridge in each string loop: soft clip plus a short extra delay tap, depth on the Jawari knob. Zero is linear (harp), full is the buzzing sitar bridge. | T, L | 1 |
| JAW-2 | At every Jawari setting the loop stays stable and the pitch stays within STR-3. | T | 1 |
| JAW-3 | Jawari should be level-dependent (louder notes buzz more), as a real bridge is. | L | 2 |

### 5.4 Chord tracker

| ID | Requirement | Ver. | Pri. |
|---|---|---|---|
| CHD-1 | Analyse the front-end signal into a 12-bin chroma vector and match it to a chord set with hysteresis. Reuse the Timekeeper STFT where it fits. | T | 1 |
| CHD-2 | Chord set for the first release: major, minor, power chord (root + fifth), dominant 7th, minor 7th, sus2, sus4 *(TBC)*; plus "single note". Output is a pitch-class set and a root. | T | 1 |
| CHD-3 | A new chord shall be adopted only after it has been stable for the commit time, 400 ms by default *(TBC, may become a secondary setting)*. Silence (gate closed) never changes the chord. | T | 1 |
| CHD-4 | Accuracy target on a reference set of clean DI recordings of open and barre chords in standard tuning: ≥ 90 % of chords correct within 600 ms. On distorted input: best effort, measured and recorded, not a release gate (the brief's open item). | T | 2 |
| CHD-5 | Low-note resolution. A 1024-point frame at 44.1 kHz has 43 Hz bins, wider than a semitone below about C4. The tracker shall resolve pitch classes down to E2, by a longer frame (4096 points), harmonic weighting or another method; whichever is chosen is justified by CHD-4. | T | 1 |
| CHD-6 | The tracker runs outside the audio ISR or spread over hops so that it never pushes a block over the CPU budget (PRF-1). | B | 1 |
| CHD-7 | The tracker is not needed in Key or Drone mode and shall not run there, to save CPU. | I | 2 |

### 5.5 Tuning manager

| ID | Requirement | Ver. | Pri. |
|---|---|---|---|
| TUN-1 | Three modes on the Tuning toggle (SW101): **Follow** (up: strings take the tracked chord), **Key** (centre: the diatonic scale of a set key), **Drone** (down: a fixed open tuning chosen from a set, TUN-3). | T | 1 |
| TUN-2 | Key mode: 12 roots × major / natural minor *(TBC: modes beyond these)*. | T | 1 |
| TUN-3 | Drone sets, first release: sitar tarab (Sa–Re–Ga–Ma–Pa scale on a set root), open D (D A D F♯ A D), open G, DADGAD, root + fifth, stacked fifths on a set root *(TBC: list to be settled by ear)*. | T | 1 |
| TUN-4 | Allocation is deterministic: the same pitch-class set and string count always give the same tuning. Low strings take the root and fifth first; pitches are spread over the bank range (STR-2). | T | 1 |
| TUN-5 | Minimum movement: on a change of set, a string whose pitch is still in the new set keeps it. | T | 1 |
| TUN-6 | When Strings is reduced, strings are dropped from the top of the range first, keeping the root and fifth. | T | 2 |
| TUN-7 | **Snap** (SW102 up): only strings below a silence threshold (−60 dB re. full scale *(TBC)*) retune; sounding strings keep their pitch until they decay below it. | T | 1 |
| TUN-8 | **Glide** (SW102 centre): sounding strings slide to the new pitch over the glide time, 150 ms default *(TBC)*, without clicks (AUD-9) and with the loop gain held constant during the slide. | T, L | 1 |
| TUN-9 | Hold (FSW-3) freezes the tuning: no retune of any kind while Hold is active. | T | 1 |
| TUN-10 | A tuning change in Key or Drone (a new key or set chosen by the user) follows Snap / Glide like a chord change. | T | 1 |
| TUN-11 | **Lock** (SW102 down): no retune of any kind, as TUN-9, while the sustain stays on the Sustain knob. Leaving Lock retunes to the current set through Glide. | T | 1 |

### 5.6 Stereo, mix and output

| ID | Requirement | Ver. | Pri. |
|---|---|---|---|
| OUT-1 | Strings panned by pitch, low to the left and high to the right, constant power. Spread width is a secondary setting, 0 (mono) to 100 %, default 70 % *(TBC)*. | T | 1 |
| OUT-2 | A player with only OUT L connected shall hear every string. Spread at 0 % puts the full mix on both outputs; whether the default needs to be narrower than 70 % for this is decided by ear on the prototype. | L | 1 |
| OUT-3 | The dry signal is centred (equal on both outputs). | T | 1 |
| OUT-4 | Mix law: dry at unity from fully counter-clockwise to noon while the wet rises from silent to full; from noon to fully clockwise the dry falls to silent with the wet at full *(TBC by ear)*. | T, L | 1 |
| OUT-5 | Output level with Mix fully counter-clockwise matches true bypass within ±0.5 dB at 1 kHz. | B | 1 |

## 6. Controls

### 6.1 Pots

Four pots, B10K on ADC1 PA0, PA1, PA2, PA4, read with the Timekeeper's DMA
scan (`controls.c`). PA3 and PA5 are free.

| ID | Requirement | Ver. | Pri. |
|---|---|---|---|
| POT-1 | Pot map: PA0 Mix (RV101), PA1 Sustain (RV102), PA2 Strings (RV103), PA4 Jawari (RV105). | I | 1 |
| POT-2 | Scan at ≥ 1 kHz per channel, smoothed so that a still pot causes no audible change and no change in a stepped value. Dead bands of 2 % at each end so every pot reaches 0 and 1. | T, B | 1 |
| POT-3 | Continuous parameters are slewed in the audio path (one-pole, 20 ms *(TBC)*) so knob moves are click-free. | T | 1 |
| POT-4 | Stepped parameters (string count, secondary-layer selections) use hysteresis of at least half a step, so a pot on a boundary never toggles. | T | 1 |

### 6.2 Toggles

| ID | Requirement | Ver. | Pri. |
|---|---|---|---|
| TGL-1 | Three Taiway 100-DP6 ON-ON-ON toggles: SW101 Tuning Follow / Key / Drone (PE11 A, PE12 B), SW102 Retune Snap / Glide / Lock (PE13, PE14), SW103 Brightness Dark / Warm / Glassy (PE15, PB10). Commons to GND, internal pull-ups. Decode: A low, B high = up; both low = centre; A high, B low = down; both high (between positions) keeps the last state. Read at start-up and on change, debounced 20 ms. | T, B | 1 |
| TGL-2 | A toggle change acts like a knob move: Tuning through TUN-10, Retune at once, Brightness through its cross-fade (STR-6), never with a click (AUD-9). | T, B | 1 |
| TGL-3 | Changing the bypass-mode secondary setting while the effect is off follows the bypass sequence (BYP-3), so the relay never switches with signal on the DSP outputs. | T, B | 1 |

### 6.3 Footswitches

Two momentary SPST-NO switches: Bypass (J105, face −20, −49) and Hold
(J106, +20, −49).

| ID | Requirement | Ver. | Pri. |
|---|---|---|---|
| FSW-1 | Debounce 10 ms *(TBC against the RC on the board)*; an action fires on the press edge, not on release, except where a hold gesture is defined. | T, B | 1 |
| FSW-2 | Bypass: a tap toggles the effect on and off. | T | 1 |
| FSW-3 | Hold: momentary by default (active while pressed); latching (tap on, tap off) as a secondary setting. While active: tuning frozen (TUN-9) and sustain infinite (STR-5). On release the strings return to the Sustain knob's decay over 200 ms *(TBC)*. | T | 1 |
| FSW-4 | Hold works with the effect on, and in Trails bypass while the strings ring out. In True bypass it does nothing. | T | 2 |
| FSW-5 | Both footswitches pressed together for 2 s enters the secondary layer (section 6.5) *(TBC: see open item 4)*. | T | 1 |

### 6.4 Expression

| ID | Requirement | Ver. | Pri. |
|---|---|---|---|
| EXP-1 | Expression on the buffered TRS input to the ADC (PB1), smoothed as POT-2. | B | 1 |
| EXP-2 | **Bend** (expression target, secondary setting): heel = no bend, toe = all strings up a whole tone *(TBC: range and direction as a secondary setting)*, pitch kept within STR-3 at both ends. | T, L | 1 |
| EXP-3 | **Swell** (expression target, secondary setting): heel = wet silent, toe = wet at the Mix setting. Dry unaffected. | T | 1 |
| EXP-4 | Heel and toe calibration as a secondary setting, stored (PER-1), so any 10–50 kΩ pedal reaches both ends. | T, B | 2 |
| EXP-5 | With no pedal plugged in the expression shall have no effect. Whether the input reads a detectable rail when empty depends on the buffer circuit; if it does not, the firmware ignores expression until a value change larger than 10 % is seen *(TBC with the schematic)*. | B | 1 |

### 6.5 Secondary layer

There is no screen. Secondary settings are reached by a footswitch gesture
and set with the knobs, with the OLED strip as the display.

| ID | Requirement | Ver. | Pri. |
|---|---|---|---|
| SEC-1 | In the secondary layer the knobs set: Mix → key / drone set (the meaning follows the Tuning toggle), Sustain → spread width, Strings → bypass mode (counter-clockwise half True, clockwise half Trails), Jawari → expression target and range (counter-clockwise half Swell, clockwise half Bend with the range growing to the end) *(all TBC; Hold latching, Brightness trim, chord commit time and output trim need a second page or a default, see open item 3)*. The toggles keep their primary job in the layer. | T | 1 |
| SEC-2 | Entering and leaving the layer never changes a primary parameter: on return each pot is ignored until it is moved past the stored value (pick-up), and the effect LED shows a pot that has not been picked up. | T | 1 |
| SEC-3 | The layer is left by the same gesture or after 10 s with no knob moved. Values are saved on leaving (PER-1). | T | 1 |
| SEC-4 | The OLED shows the value of the knob last moved (DSP-3). | T | 1 |
| SEC-5 | Audio keeps running while in the layer. | T | 1 |

## 7. Display

A 0.91 in 128×32 SSD1306 OLED on I2C1 (PB6 SCL, PB7 SDA, J408) shows the
state; the effect LED D113 is on a PWM pin. The module is mounted turned
round (pads at its right end), so the driver sets the SSD1306 segment and
COM remap to flip the image 180° (design brief, decision 16).

| ID | Requirement | Ver. | Pri. |
|---|---|---|---|
| DSP-1 | Normal running: the OLED shows the pitch classes the active strings are tuned to as note names, the root highlighted, plus mode and chord. | T, B | 1 |
| DSP-2 | A chord change shows on the OLED at the moment it is committed (CHD-3); in Snap mode, the OLED shows the target tuning, not the strings still waiting to retune. | T | 1 |
| DSP-3 | Secondary layer: a stepped value shows as its name (key root, set index), a continuous value as a bar. | T | 1 |
| DSP-4 | Effect LED: on when the effect is engaged; breathing slowly while Hold is active; off in bypass. In Trails bypass it fades out with the strings *(TBC)*. | T | 1 |
| DSP-5 | Display and LED activity shall not be audible at the outputs. OLED refresh and I2C traffic are not synchronised to anything in the audio band, and any software PWM runs above 20 kHz or below 2 Hz *(TBC: to be checked on the bench, since the display sits over the jack bodies)*. | B | 1 |
| DSP-6 | Faults and test mode use OLED messages listed in the firmware README, distinct from any normal display. | I | 2 |

## 8. Bypass and relay

One Omron G6K-2F-Y relay (5 V coil), driven by a 2N7002 from the MCU, pull-down off
through boot (brief, Bypass). De-energised: OUT L = IN, input buffer
grounded, OUT R silent. Energised: signal goes through the DSP.

| ID | Requirement | Ver. | Pri. |
|---|---|---|---|
| BYP-1 | **True bypass** (bypass mode = True, the default): effect off = relay de-energised. | B | 1 |
| BYP-2 | **Trails bypass** (bypass mode = Trails, secondary setting): the relay stays energised; effect off feeds dry to both outputs, stops feeding the strings and lets them ring out at their current decay (or hold, FSW-4). | T, B | 1 |
| BYP-3 | Every relay change follows: fade the DSP outputs to silence (10 ms *(TBC)*), switch, wait for the contacts to settle (operate time plus bounce from the G6K datasheet, 5 ms *(TBC)*), fade back in. No mute transistor. | T, B | 1 |
| BYP-4 | A footswitch tap reaches the relay within 20 ms. | B | 1 |
| BYP-5 | Bypass in True mode produces no click at OUT L louder than −60 dBu *(TBC)* with the input shorted. | B | 2 |
| BYP-6 | The relay drive pin stays low (relay off, true bypass) from reset until the codec is running and the outputs are at silence. | B | 1 |
| BYP-7 | Power-up state is effect on *(TBC: or last state, see open item 6)*, entered through BYP-3 once the codec is running. | B | 1 |

## 9. Persistence

| ID | Requirement | Ver. | Pri. |
|---|---|---|---|
| PER-1 | Secondary settings, expression calibration and (if BYP-7 says so) the last bypass state are kept in the W25Q128 QSPI flash, with a version number and CRC as the Timekeeper's `preset.c`. | T | 1 |
| PER-2 | Writes only after 2 s with no change and never more often than once per 10 s; settings alternate between at least two sectors so a power loss during a write leaves the previous copy valid. | T | 1 |
| PER-3 | A missing, corrupt or older-version record loads defaults (or migrates, if the layout allows) and never blocks start-up. | T | 1 |
| PER-4 | A flash write never stalls the audio callback (the image runs from internal flash and RAM, not from QSPI, while writing; see PLT-3). | B | 1 |
| PER-5 | User presets are not in the first release (no control to recall them); the layout leaves room for them. | I | 3 |

## 10. Start-up, faults and safety

| ID | Requirement | Ver. | Pri. |
|---|---|---|---|
| SYS-1 | Power to audio within 500 ms *(TBC)*: clocks, codec reset and init, settings load, audio start, fade-in. Outputs silent until the codec is running. | B | 1 |
| SYS-2 | Independent watchdog as the Timekeeper's (IWDG1 from the LSI, crash record kept across reset). A watchdog reset drops the relay (true bypass, signal still on OUT L) and restarts. | B | 1 |
| SYS-3 | Codec, I2C or SAI failure at start-up: relay stays off (OUT L passes the guitar), fault message on the OLED, retry once. | B | 1 |
| SYS-4 | Audio-callback overrun (block not finished in time) is counted, never crashes, and is visible over SWD/SWO. | I, B | 1 |
| SYS-5 | Brown-out reset enabled at a level that keeps the QSPI write valid. | I | 1 |
| SYS-6 | Firmware version (major.minor.patch and git hash) in the image, readable over SWD and shown on the OLED by a gesture *(TBC)*. | I | 2 |

## 11. Performance budgets

| ID | Requirement | Ver. | Pri. |
|---|---|---|---|
| PRF-1 | Worst-case audio callback, 24 strings, full Jawari, Glide active, tracker running: ≤ 60 % of the block period at 480 MHz, measured with the DWT cycle counter (`dbg_audio_max_cycles`) over a 10-minute playing test. | B | 1 |
| PRF-2 | Same figure measured on the Timekeeper board before the Harp schematic is frozen; this is the brief's "not yet measured" CPU number. | B | 1 |
| PRF-3 | RAM: all engine state and buffers ≤ 75 % of internal RAM, reported from the map file at each release. | I | 1 |
| PRF-4 | Flash: see PLT-3. | I | 1 |
| PRF-5 | Hot loops (string bank) may be placed in ITCM with `AUDIO_ITCM`, as the Timekeeper does. | I | 3 |

## 12. Structure and reuse

| ID | Requirement | Ver. | Pri. |
|---|---|---|---|
| ARC-1 | Engine modules are new files under `firmware/the_harp/Core/`: string bank, Jawari, chord tracker, tuning manager, stereo/mix/output. Each is pure C over its own header (PLT-5). | I | 1 |
| ARC-2 | Reused from the Timekeeper: the `audio_fx_t` chain and ISR parameter hand-off, `controls.c`, the hum filter, the noise gate, the STFT from `fx_spectral.c`, the QSPI preset storage, the AK4621EF driver, the IWDG and crash record, the DWT budget timing. How they are shared (copy with a recorded source commit, or a shared library) is open item 7. | I | 1 |
| ARC-3 | Not carried over: SDRAM, FMC, TFT and LVGL, USB, MIDI, encoders, the knob board link, the mod matrix and the other effects. | I | 1 |
| ARC-4 | Parameter changes from the main loop reach the ISR by the Timekeeper's staging pattern (stage, adopt at block boundary); no locks in the audio path. | I | 1 |
| ARC-5 | `BOARD_TIMEKEEPER` build: the OLED content is drawn on the Timekeeper's TFT, the four pots on four of its control channels and the three toggles in the UI simulator *(TBC)*, Hold and Bypass on its existing switches. | B | 1 |

## 13. Verification

| ID | Requirement | Ver. | Pri. |
|---|---|---|---|
| VER-1 | `firmware/the_harp/tests/run_tests.sh` builds and runs every host test with warnings as errors, as the Timekeeper's suite does. | T | 1 |
| VER-2 | Host tests cover at least: string pitch accuracy across the range and Brightness (STR-3), stability under Hold and full Jawari (STR-5, JAW-2), excitation selectivity (STR-4), tuning allocation and minimum movement (TUN-4, TUN-5), Snap / Glide behaviour (TUN-7, TUN-8), chord tracker on synthetic chords and on the reference recordings (CHD-4), mix law and limiter (OUT-4, AUD-6), pot pick-up and hysteresis (SEC-2, POT-4), settings CRC and migration (PER-3). | T | 1 |
| VER-3 | An offline render tool runs the engine over a WAV file and writes a stereo WAV, for listening tests and for tracker evaluation on recorded playing. | T | 1 |
| VER-4 | Reference recordings for CHD-4 (clean DI and distorted, chords and single notes) are kept in the repo or referenced from it, with expected labels. | I | 2 |
| VER-5 | Production test mode, entered by holding both footswitches at power-up: walks the LEDs, toggles the relay with a pause, shows each pot and toggle on the LEDs, outputs a 1 kHz tone at −10 dBFS on both outputs, and exits on power cycle. | B | 2 |

## 14. Order of work

1. **On the Timekeeper board** (`BOARD_TIMEKEEPER`): string bank with a
   fixed tuning, then Jawari, then the tuning manager in Key / Drone
   (neither needs the tracker). Measure PRF-2. Listen; settle
   the *(TBC)* ranges in sections 5 and 6.
2. Chord tracker and Follow mode, offline first against the reference
   recordings (VER-3, VER-4), then on the board.
3. Controls, secondary layer and the TFT stand-in for the OLED.
4. Port to `BOARD_HARP` when the schematic pin map exists: LEDs on GPIO,
   relay sequence, toggles, settings in QSPI, start-up and fault handling.
5. Production test mode and the bench measurements (sections 4, 8, 11).

## 15. Open items

1. **Brief latency figure.** The brief's 6 ms / 256-sample block does not
   match the Timekeeper's 64-frame block; correct the brief after AUD-5 is
   measured.
2. **Internal flash.** Whether the Harp image fits 128 KB (PLT-3). Build
   the Timekeeper image without TFT, LVGL, USB and SDRAM code to get a
   first number.
3. **Secondary layer size.** With Tuning, Brightness and Retune on
   toggles, bypass mode and expression target join the secondary layer,
   which now has more settings than knobs (SEC-1). Choose a second page or
   defaults on the prototype.
4. **Secondary-layer gesture.** Both footswitches together (FSW-5) keeps
   each switch's single job simple; the alternative, holding Bypass,
   delays every bypass action until release. Decide on the prototype.
5. **Mono use.** With no switch on the output jacks the firmware cannot
   tell that OUT R is unused (OUT-2). Either a default spread a mono player
   can live with, or a jack-detect line on the schematic now while the
   pin budget has room.
6. **Power-up state.** Effect on, or last state (BYP-7, PER-1).
7. **Sharing code with the Timekeeper.** Copy the reused modules into this
   repo with the source commit recorded, or pull them from a shared
   library (submodule). Copying is simpler for a first build; a library
   avoids two copies of the same fixes.
8. **Expression detection without a switch** (EXP-5) depends on the
   Timekeeper buffer circuit carried into sheet 6.
9. **Display.** The 0.91 in OLED content (note names, chord, values) is judged
   after step 3 of section 14, using the TFT stand-in.

## 16. Trace to the brief

| Brief item | Requirements |
|---|---|
| Signal path, stereo in (mono plug copied) / stereo out, dry through the codec | AUD-1 – AUD-5, OUT-1 – OUT-5 |
| String bank, 24 strings, no envelope trigger | STR-1 – STR-8 |
| Jawari | JAW-1 – JAW-3 |
| Chord tracker, ~400 ms commit, hysteresis | CHD-1 – CHD-7 |
| Tuning manager, Follow / Key / Drone, Snap / Glide / Lock | TUN-1 – TUN-11 |
| Stereo spread | OUT-1, OUT-2 |
| Front end | FE-1, FE-2 |
| Framework: chain, presets in QSPI, smoothing, expression, UI simulator | ARC-2, ARC-4, PER-1 – PER-5, POT-3, EXP-1 – EXP-5, ARC-5 |
| Controls and face | POT-1 – POT-4, TGL-1 – TGL-3, FSW-1 – FSW-5 |
| Secondary settings by footswitch + knob | SEC-1 – SEC-5 |
| OLED strip, effect LED | DSP-1 – DSP-6 |
| Relay true bypass, Trails, fades, no mute transistor | BYP-1 – BYP-7 |
| No SDRAM, H750VBT6 | PLT-1 – PLT-3, STR-2 |
| CPU "not yet measured" | PRF-1, PRF-2 |
| Firmware first on the Timekeeper board | PLT-4, ARC-5, section 14 |

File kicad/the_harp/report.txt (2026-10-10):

Info: Processing symbol 'C506:Capacitor_SMD:C_0603_1608Metric'.
Info: Processing symbol 'C213:Capacitor_SMD:C_0603_1608Metric'.
Info: Processing symbol 'R707:Resistor_SMD:R_0603_1608Metric'.
Info: Processing symbol 'R404:Resistor_SMD:R_0805_2012Metric'.
Info: Processing symbol 'J402:Connector_Audio:Jack_6.35mm_Neutrik_NMJ6HCD2_Horizontal'.
Info: Processing symbol 'C504:Capacitor_SMD:C_0603_1608Metric'.
Info: Processing symbol 'IC501:Audio_Module:SOP65P760X150-30N'.
Info: Processing symbol 'D407:Diode_SMD:D_SOD-523'.
Info: Processing symbol 'D403:Diode_SMD:D_SOD-523'.
Info: Processing symbol 'D113:LED_THT:LED_D3.0mm'.
Info: Processing symbol 'C505:Capacitor_SMD:C_0603_1608Metric'.
Info: Processing symbol 'C508:Capacitor_SMD:CP_Elec_4x5.8'.
Info: Processing symbol 'C507:Capacitor_SMD:C_0603_1608Metric'.
Reconnected via from CODEC_CDTI to unconnected-(IC501-CDTI/CKS0-Pad17).
Removed unused net /MCU/SWDIO_N.
Add net unconnected-(C505-Pad2).
Add net unconnected-(C506-Pad2).
Reconnected C506 pin 2 from GND to unconnected-(C506-Pad2).
Add net unconnected-(C506-Pad1).
Reconnected C506 pin 1 from +3V3 to unconnected-(C506-Pad1).
Reconnected C505 pin 1 from +3V3 to unconnected-(C505-Pad1).
Add net unconnected-(C507-Pad2).
Reconnected C507 pin 2 from GND to unconnected-(C507-Pad2).
Add net unconnected-(C507-Pad1).
Reconnected C507 pin 1 from +5V to unconnected-(C507-Pad1).
Add net unconnected-(C505-Pad1).
Add net unconnected-(C508-Pad1).
Reconnected C508 pin 1 from +5V to unconnected-(C508-Pad1).
Add net unconnected-(C508-Pad2).
Reconnected C508 pin 2 from GND to unconnected-(C508-Pad2).
Reconnected C504 pin 1 from +3V3 to unconnected-(C504-Pad1).
Add net unconnected-(D113-K-Pad1).
Reconnected D113 pin 1 from /Jacks and Bypass/LED_EFF_K to unconnected-(D113-K-Pad1).
Add net unconnected-(D113-A-Pad2).
Reconnected D113 pin 2 from +9V to unconnected-(D113-A-Pad2).
Add net unconnected-(C504-Pad1).
Add net unconnected-(D403-A1-Pad1).
Reconnected D403 pin 1 from GND to unconnected-(D403-A1-Pad1).
Add net unconnected-(D403-A2-Pad2).
Reconnected D403 pin 2 from /Jacks and Bypass/IN to unconnected-(D403-A2-Pad2).
Reconnected C504 pin 2 from GND to unconnected-(C504-Pad2).
Updated D407 footprint filters to 'TO-???* *_Diode_* *SingleDiode* D_*'.
Add net unconnected-(D407-A1-Pad1).
Reconnected D407 pin 1 from GND to unconnected-(D407-A1-Pad1).
Add net unconnected-(D407-A2-Pad2).
Reconnected D407 pin 2 from IN_R to unconnected-(D407-A2-Pad2).
Add net unconnected-(C504-Pad2).
Updated IC501 fields.
Add net unconnected-(IC501-VSS1-Pad7).
Reconnected IC501 pin 7 from GND to unconnected-(IC501-VSS1-Pad7).
Add net unconnected-(IC501-LRCK-Pad11).
Reconnected IC501 pin 11 from CODEC_LRCK to unconnected-(IC501-LRCK-Pad11).
Add net unconnected-(IC501-TVDD-Pad24).
Reconnected IC501 pin 24 from +3V3 to unconnected-(IC501-TVDD-Pad24).
Add net unconnected-(IC501-AVDD-Pad8).
Reconnected IC501 pin 8 from +5V to unconnected-(IC501-AVDD-Pad8).
Add net unconnected-(IC501-P/S-Pad9).
Reconnected IC501 pin 9 from +3V3 to unconnected-(IC501-P/S-Pad9).
Add net unconnected-(IC501-OVFL/DZFL-Pad16).
Reconnected IC501 pin 16 from unconnected-(IC501-OVFL/DZFL-Pad16) to unconnected-(IC501-OVFL/DZFL-Pad16).
Add net unconnected-(IC501-DVDD-Pad25).
Reconnected IC501 pin 25 from +3V3 to unconnected-(IC501-DVDD-Pad25).
Add net unconnected-(IC501-AOUTR--Pad29).
Reconnected IC501 pin 29 from DAC_R_N to unconnected-(IC501-AOUTR--Pad29).
Add net unconnected-(IC501-AOUTR+-Pad30).
Reconnected IC501 pin 30 from DAC_R_P to unconnected-(IC501-AOUTR+-Pad30).
Add net unconnected-(IC501-OVFR/DZFR-Pad15).
Reconnected IC501 pin 15 from unconnected-(IC501-OVFR/DZFR-Pad15) to unconnected-(IC501-OVFR/DZFR-Pad15).
Add net unconnected-(IC501-VREF-Pad6).
Reconnected IC501 pin 6 from +5V to unconnected-(IC501-VREF-Pad6).
Add net unconnected-(IC501-CDTI/CKS0-Pad17).
Reconnected IC501 pin 17 from CODEC_CDTI to unconnected-(IC501-CDTI/CKS0-Pad17).
Add net unconnected-(IC501-DFS0-Pad20).
Reconnected IC501 pin 20 from GND to unconnected-(IC501-DFS0-Pad20).
Add net unconnected-(IC501-AOUTL+-Pad28).
Reconnected IC501 pin 28 from DAC_L_P to unconnected-(IC501-AOUTL+-Pad28).
Add net unconnected-(IC501-AINR+-Pad2).
Reconnected IC501 pin 2 from ADC_R_P to unconnected-(IC501-AINR+-Pad2).
Add net unconnected-(IC501-DEM0-Pad22).
Reconnected IC501 pin 22 from GND to unconnected-(IC501-DEM0-Pad22).
Add net unconnected-(IC501-SDTO-Pad13).
Reconnected IC501 pin 13 from CODEC_SDTO to unconnected-(IC501-SDTO-Pad13).
Add net unconnected-(IC501-SDTI-Pad14).
Reconnected IC501 pin 14 from CODEC_SDTI to unconnected-(IC501-SDTI-Pad14).
Add net unconnected-(IC501-VCOM-Pad1).
Reconnected IC501 pin 1 from /Codec/VCOM to unconnected-(IC501-VCOM-Pad1).
Add net unconnected-(IC501-MCLK-Pad10).
Reconnected IC501 pin 10 from CODEC_MCLK to unconnected-(IC501-MCLK-Pad10).
Add net unconnected-(IC501-AINR--Pad3).
Reconnected IC501 pin 3 from ADC_R_N to unconnected-(IC501-AINR--Pad3).
Add net unconnected-(IC501-CCLK/CKS1-Pad18).
Reconnected IC501 pin 18 from CODEC_CCLK to unconnected-(IC501-CCLK/CKS1-Pad18).
Add net unconnected-(IC501-VSS2-Pad26).
Reconnected IC501 pin 26 from GND to unconnected-(IC501-VSS2-Pad26).
Add net unconnected-(IC501-AINL+-Pad4).
Reconnected IC501 pin 4 from ADC_L_P to unconnected-(IC501-AINL+-Pad4).
Add net unconnected-(IC501-CSN/DIF-Pad19).
Reconnected IC501 pin 19 from CODEC_CSN to unconnected-(IC501-CSN/DIF-Pad19).
Add net unconnected-(IC501-SDFIL-Pad23).
Reconnected IC501 pin 23 from GND to unconnected-(IC501-SDFIL-Pad23).
Add net unconnected-(IC501-AINL--Pad5).
Reconnected IC501 pin 5 from ADC_L_N to unconnected-(IC501-AINL--Pad5).
Add net unconnected-(IC501-PDN-Pad21).
Reconnected IC501 pin 21 from /Codec/PDN to unconnected-(IC501-PDN-Pad21).
Add net unconnected-(IC501-BICK-Pad12).
Reconnected IC501 pin 12 from CODEC_BICK to unconnected-(IC501-BICK-Pad12).
Add net unconnected-(IC501-AOUTL--Pad27).
Reconnected IC501 pin 27 from DAC_L_N to unconnected-(IC501-AOUTL--Pad27).
Reconnected C213 pin 2 from GND to unconnected-(C213-Pad2).
Updated J402 fields.
Add net unconnected-(J402-PadT).
Reconnected J402 pin T from /Jacks and Bypass/IN to unconnected-(J402-PadT).
Add net unconnected-(J402-PadS).
Reconnected J402 pin S from GND to unconnected-(J402-PadS).
Add net unconnected-(J402-PadR).
Reconnected J402 pin R from IN_R to unconnected-(J402-PadR).
Add net unconnected-(C213-Pad2).
Add net unconnected-(R404-Pad2).
Reconnected R404 pin 2 from /Jacks and Bypass/LED_EFF_LOW to unconnected-(R404-Pad2).
Add net unconnected-(R404-Pad1).
Reconnected R404 pin 1 from /Jacks and Bypass/LED_EFF_K to unconnected-(R404-Pad1).
Reconnected C213 pin 1 from /MCU/NRST to unconnected-(C213-Pad1).
Add net unconnected-(R707-Pad2).
Reconnected R707 pin 2 from VCOM_B to unconnected-(R707-Pad2).
Add net unconnected-(R707-Pad1).
Reconnected R707 pin 1 from /Analog In and Out/OUTL_P to unconnected-(R707-Pad1).
Reconnected via from GND to unconnected-(J402-PadS).
Reconnected via from GND to unconnected-(J402-PadS).
Reconnected via from GND to unconnected-(J402-PadS).
Reconnected via from GND to unconnected-(J402-PadS).
Reconnected via from GND to unconnected-(J402-PadS).
Reconnected via from GND to unconnected-(J402-PadS).
Reconnected via from GND to unconnected-(J402-PadS).
Reconnected via from GND to unconnected-(J402-PadS).
Reconnected via from GND to unconnected-(J402-PadS).
Reconnected via from GND to unconnected-(J402-PadS).
Reconnected via from GND to unconnected-(J402-PadS).
Reconnected via from GND to unconnected-(J402-PadS).
Reconnected via from GND to unconnected-(J402-PadS).
Reconnected via from GND to unconnected-(J402-PadS).
Reconnected via from GND to unconnected-(J402-PadS).
Reconnected via from GND to unconnected-(J402-PadS).
Reconnected via from GND to unconnected-(J402-PadS).
Reconnected via from GND to unconnected-(J402-PadS).
Reconnected via from GND to unconnected-(J402-PadS).
Reconnected via from GND to unconnected-(J402-PadS).
Reconnected via from GND to unconnected-(J402-PadS).
Reconnected via from GND to unconnected-(J402-PadS).
Reconnected via from GND to unconnected-(J402-PadS).
Reconnected via from GND to unconnected-(J402-PadS).
Reconnected via from GND to unconnected-(J402-PadS).
Reconnected via from GND to unconnected-(J402-PadS).
Reconnected via from GND to unconnected-(J402-PadS).
Reconnected via from GND to unconnected-(J402-PadS).
Reconnected via from GND to unconnected-(J402-PadS).
Reconnected via from GND to unconnected-(J402-PadS).
Reconnected via from GND to unconnected-(J402-PadS).
Reconnected via from GND to unconnected-(J402-PadS).
Reconnected via from GND to unconnected-(J402-PadS).
Reconnected via from GND to unconnected-(J402-PadS).
Reconnected via from GND to unconnected-(J402-PadS).
Reconnected via from GND to unconnected-(J402-PadS).
Reconnected via from GND to unconnected-(J402-PadS).
Reconnected via from GND to unconnected-(J402-PadS).
Reconnected via from GND to unconnected-(J402-PadS).
Reconnected via from GND to unconnected-(J402-PadS).
Reconnected via from GND to unconnected-(J402-PadS).
Reconnected via from GND to unconnected-(J402-PadS).
Reconnected via from GND to unconnected-(J402-PadS).
Reconnected via from GND to unconnected-(J402-PadS).
Reconnected via from GND to unconnected-(J402-PadS).
Reconnected via from GND to unconnected-(J402-PadS).
Reconnected via from GND to unconnected-(J402-PadS).
Reconnected via from GND to unconnected-(J402-PadS).
Reconnected via from GND to unconnected-(J402-PadS).
Reconnected via from GND to unconnected-(J402-PadS).
Reconnected via from GND to unconnected-(J402-PadS).
Reconnected via from GND to unconnected-(J402-PadS).
Reconnected via from GND to unconnected-(J402-PadS).
Reconnected via from GND to unconnected-(J402-PadS).
Reconnected via from GND to unconnected-(J402-PadS).
Reconnected via from GND to unconnected-(J402-PadS).
Reconnected via from GND to unconnected-(J402-PadS).
Reconnected via from GND to unconnected-(J402-PadS).
Reconnected via from GND to unconnected-(J402-PadS).
Reconnected via from GND to unconnected-(J402-PadS).
Reconnected via from GND to unconnected-(J402-PadS).
Reconnected via from GND to unconnected-(J402-PadS).
Reconnected via from GND to unconnected-(J402-PadS).
Reconnected via from GND to unconnected-(J402-PadS).
Reconnected via from GND to unconnected-(J402-PadS).
Reconnected via from GND to unconnected-(J402-PadS).
Reconnected via from GND to unconnected-(J402-PadS).
Reconnected via from GND to unconnected-(J402-PadS).
Reconnected via from GND to unconnected-(J402-PadS).
Reconnected via from GND to unconnected-(J402-PadS).
Reconnected via from GND to unconnected-(J402-PadS).
Reconnected via from GND to unconnected-(J402-PadS).
Reconnected via from GND to unconnected-(J402-PadS).
Reconnected via from GND to unconnected-(J402-PadS).
Reconnected via from GND to unconnected-(J402-PadS).
Reconnected via from GND to unconnected-(J402-PadS).
Reconnected via from GND to unconnected-(J402-PadS).
Reconnected via from GND to unconnected-(J402-PadS).
Reconnected via from GND to unconnected-(J402-PadS).
Reconnected via from GND to unconnected-(J402-PadS).
Reconnected via from GND to unconnected-(J402-PadS).
Reconnected via from GND to unconnected-(J402-PadS).
Reconnected via from GND to unconnected-(J402-PadS).
Reconnected via from GND to unconnected-(J402-PadS).
Reconnected via from GND to unconnected-(J402-PadS).
Reconnected via from GND to unconnected-(J402-PadS).
Reconnected via from GND to unconnected-(J402-PadS).
Reconnected via from GND to unconnected-(J402-PadS).
Reconnected via from GND to unconnected-(J402-PadS).
Reconnected via from GND to unconnected-(J402-PadS).
Reconnected via from GND to unconnected-(J402-PadS).
Reconnected via from GND to unconnected-(J402-PadS).
Reconnected via from GND to unconnected-(J402-PadS).
Reconnected via from GND to unconnected-(J402-PadS).
Reconnected via from GND to unconnected-(J402-PadS).
Reconnected via from GND to unconnected-(J402-PadS).
Reconnected via from GND to unconnected-(J402-PadS).
Reconnected via from GND to unconnected-(J402-PadS).
Reconnected via from GND to unconnected-(J402-PadS).
Reconnected via from GND to unconnected-(J402-PadS).
Reconnected via from GND to unconnected-(J402-PadS).
Reconnected via from GND to unconnected-(J402-PadS).
Reconnected via from GND to unconnected-(J402-PadS).
Reconnected via from GND to unconnected-(J402-PadS).
Reconnected via from GND to unconnected-(J402-PadS).
Reconnected via from GND to unconnected-(J402-PadS).
Reconnected via from +3V3 to unconnected-(IC501-DVDD-Pad25).
Reconnected via from +3V3 to unconnected-(IC501-DVDD-Pad25).
Reconnected via from +3V3 to unconnected-(IC501-DVDD-Pad25).
Reconnected via from +3V3 to unconnected-(IC501-DVDD-Pad25).
Reconnected via from +3V3 to unconnected-(IC501-DVDD-Pad25).
Reconnected via from +3V3 to unconnected-(IC501-DVDD-Pad25).
Reconnected via from +3V3 to unconnected-(IC501-DVDD-Pad25).
Reconnected via from +3V3 to unconnected-(IC501-DVDD-Pad25).
Reconnected via from +3V3 to unconnected-(IC501-DVDD-Pad25).
Reconnected via from +3V3 to unconnected-(IC501-DVDD-Pad25).
Reconnected via from +3V3 to unconnected-(IC501-DVDD-Pad25).
Reconnected via from +3V3 to unconnected-(IC501-DVDD-Pad25).
Reconnected via from +3V3 to unconnected-(IC501-DVDD-Pad25).
Reconnected via from +3V3 to unconnected-(IC501-DVDD-Pad25).
Reconnected via from +3V3 to unconnected-(IC501-DVDD-Pad25).
Reconnected via from +3V3 to unconnected-(IC501-DVDD-Pad25).
Reconnected via from +3V3 to unconnected-(IC501-DVDD-Pad25).
Reconnected via from +3V3 to unconnected-(IC501-DVDD-Pad25).
Reconnected via from +3V3 to unconnected-(IC501-DVDD-Pad25).
Reconnected via from +3V3 to unconnected-(IC501-DVDD-Pad25).
Reconnected via from +3V3 to unconnected-(IC501-DVDD-Pad25).
Reconnected via from +3V3 to unconnected-(IC501-DVDD-Pad25).
Reconnected via from +3V3 to unconnected-(IC501-DVDD-Pad25).
Reconnected via from +3V3 to unconnected-(IC501-DVDD-Pad25).
Reconnected via from +3V3 to unconnected-(IC501-DVDD-Pad25).
Reconnected via from +3V3 to unconnected-(IC501-DVDD-Pad25).
Reconnected via from +3V3 to unconnected-(IC501-DVDD-Pad25).
Reconnected via from +3V3 to unconnected-(IC501-DVDD-Pad25).
Reconnected via from +3V3 to unconnected-(IC501-DVDD-Pad25).
Reconnected via from +3V3 to unconnected-(IC501-DVDD-Pad25).
Reconnected via from +3V3 to unconnected-(IC501-DVDD-Pad25).
Reconnected via from +3V3 to unconnected-(IC501-DVDD-Pad25).
Reconnected via from +3V3 to unconnected-(IC501-DVDD-Pad25).
Reconnected via from +3V3 to unconnected-(IC501-DVDD-Pad25).
Reconnected via from +5V to unconnected-(IC501-VREF-Pad6).
Reconnected via from +5V to unconnected-(IC501-VREF-Pad6).
Reconnected via from +5V to unconnected-(IC501-VREF-Pad6).
Reconnected via from +5V to unconnected-(IC501-VREF-Pad6).
Reconnected via from +5V to unconnected-(IC501-VREF-Pad6).
Reconnected via from +5V to unconnected-(IC501-VREF-Pad6).
Reconnected via from +5V to unconnected-(IC501-VREF-Pad6).
Reconnected via from +5V to unconnected-(IC501-VREF-Pad6).
Reconnected via from +5V to unconnected-(IC501-VREF-Pad6).
Reconnected via from +5V to unconnected-(IC501-VREF-Pad6).
Reconnected via from +5V to unconnected-(IC501-VREF-Pad6).
Reconnected via from +5V to unconnected-(IC501-VREF-Pad6).
Reconnected via from +5V to unconnected-(IC501-VREF-Pad6).
Reconnected via from +5V to unconnected-(IC501-VREF-Pad6).
Reconnected via from +5V to unconnected-(IC501-VREF-Pad6).
Reconnected via from +5V to unconnected-(IC501-VREF-Pad6).
Reconnected via from +5V to unconnected-(IC501-VREF-Pad6).
Reconnected via from +5V to unconnected-(IC501-VREF-Pad6).
Reconnected via from +5V to unconnected-(IC501-VREF-Pad6).
Reconnected via from +9V to unconnected-(D113-A-Pad2).
Reconnected via from +9V to unconnected-(D113-A-Pad2).
Reconnected via from +9V to unconnected-(D113-A-Pad2).
Reconnected via from +9V to unconnected-(D113-A-Pad2).
Reconnected via from +9V to unconnected-(D113-A-Pad2).
Reconnected via from +9V to unconnected-(D113-A-Pad2).
Removed unused net unconnected-(U302-NC-Pad4).
Removed unused net unconnected-(U201-PE1-Pad98).
Removed unused net unconnected-(U201-PE0-Pad97).
Removed unused net unconnected-(U201-PD9-Pad56).
Removed unused net unconnected-(U201-PD8-Pad55).
Removed unused net unconnected-(U201-PD7-Pad88).
Removed unused net unconnected-(U201-PD6-Pad87).
Removed unused net unconnected-(U201-PD5-Pad86).
Removed unused net unconnected-(U201-PD4-Pad85).
Removed unused net unconnected-(U201-PD3-Pad84).
Removed unused net unconnected-(U201-PD2-Pad83).
Removed unused net unconnected-(U201-PD15-Pad62).
Removed unused net unconnected-(U201-PD14-Pad61).
Removed unused net unconnected-(U201-PD13-Pad60).
Removed unused net unconnected-(U201-PD12-Pad59).
Removed unused net unconnected-(U201-PD11-Pad58).
Removed unused net unconnected-(U201-PD10-Pad57).
Removed unused net unconnected-(U201-PD1-Pad82).
Removed unused net unconnected-(U201-PD0-Pad81).
Removed unused net unconnected-(U201-PC9-Pad66).
Removed unused net unconnected-(U201-PC8-Pad65).
Removed unused net unconnected-(U201-PC5-Pad33).
Removed unused net unconnected-(U201-PC4-Pad32).
Removed unused net unconnected-(U201-PC3_C-Pad18).
Removed unused net unconnected-(U201-PC2_C-Pad17).
Reconnected via from /Codec/VCOM to unconnected-(IC501-VCOM-Pad1).
Reconnected via from /Codec/VCOM to unconnected-(IC501-VCOM-Pad1).
Removed unused net unconnected-(U201-PC13-Pad7).
Removed unused net unconnected-(U201-PC12-Pad80).
Removed unused net unconnected-(U201-PC1-Pad16).
Removed unused net unconnected-(U201-PC0-Pad15).
Removed unused net unconnected-(U201-PB9-Pad96).
Removed unused net unconnected-(U201-PB5-Pad91).
Removed unused net unconnected-(U201-PB15-Pad54).
Removed unused net unconnected-(U201-PB14-Pad53).
Removed unused net unconnected-(U201-PB11-Pad47).
Removed unused net unconnected-(U201-PB0-Pad34).
Reconnected via from /Jacks and Bypass/IN to unconnected-(J402-PadT).
Removed unused net unconnected-(U201-PA9-Pad68).
Removed unused net unconnected-(U201-PA8-Pad67).
Removed unused net unconnected-(U201-PA7-Pad31).
Removed unused net unconnected-(U201-PA6-Pad30).
Removed unused net unconnected-(U201-PA5-Pad29).
Removed unused net unconnected-(U201-PA3-Pad25).
Removed unused net unconnected-(U201-PA15-Pad77).
Removed unused net unconnected-(U201-PA12-Pad71).
Removed unused net unconnected-(U201-PA11-Pad70).
Removed unused net unconnected-(U201-PA10-Pad69).
Removed unused net unconnected-(J406-PadTN).
Removed unused net unconnected-(J406-PadSN).
Removed unused net unconnected-(J406-PadRN).
Removed unused net unconnected-(J404-PadTN).
Removed unused net unconnected-(J404-PadSN).
Removed unused net unconnected-(J404-PadRN).
Removed unused net unconnected-(J404-PadR).
Removed unused net unconnected-(J403-PadTN).
Removed unused net unconnected-(J403-PadSN).
Removed unused net unconnected-(J403-PadRN).
Removed unused net unconnected-(J403-PadR).
Removed unused net unconnected-(IC501-OVFR/DZFR-Pad15).
Removed unused net unconnected-(IC501-OVFL/DZFL-Pad16).
Removed unused net VDDA.
Removed unused net VCOM_B.
Removed unused net VCOM_A.
Removed unused net RELAY_DRV.
Removed unused net POT5.
Removed unused net POT3.
Removed unused net POT2.
Removed unused net POT1.
Removed unused net OLED_SDA.
Removed unused net OLED_SCL.
Removed unused net LED_HOLD_DRV.
Removed unused net LED_EFFECT_DRV.
Removed unused net IN_R.
Removed unused net FSW_HOLD_IN.
Removed unused net FSW_BYPASS_IN.
Removed unused net EXP.
Removed unused net EFFECT_OUT_R.
Removed unused net EFFECT_OUT_L.
Removed unused net EFFECT_IN_BUF_R.
Reconnected via from ADC_L_N to unconnected-(IC501-AINL--Pad5).
Reconnected via from ADC_L_N to unconnected-(IC501-AINL--Pad5).
Reconnected via from ADC_L_P to unconnected-(IC501-AINL+-Pad4).
Reconnected via from ADC_L_P to unconnected-(IC501-AINL+-Pad4).
Reconnected via from ADC_L_P to unconnected-(IC501-AINL+-Pad4).
Reconnected via from ADC_L_P to unconnected-(IC501-AINL+-Pad4).
Reconnected via from ADC_R_N to unconnected-(IC501-AINR--Pad3).
Reconnected via from ADC_R_N to unconnected-(IC501-AINR--Pad3).
Reconnected via from ADC_R_N to unconnected-(IC501-AINR--Pad3).
Reconnected via from ADC_R_P to unconnected-(IC501-AINR+-Pad2).
Reconnected via from ADC_R_P to unconnected-(IC501-AINR+-Pad2).
Reconnected via from ADC_R_P to unconnected-(IC501-AINR+-Pad2).
Reconnected via from CODEC_CDTI to unconnected-(IC501-CDTI/CKS0-Pad17).
Add net unconnected-(C213-Pad1).
Reconnected via from CODEC_CSN to unconnected-(IC501-CSN/DIF-Pad19).
Reconnected via from CODEC_CSN to unconnected-(IC501-CSN/DIF-Pad19).
Reconnected via from CODEC_MCLK to unconnected-(IC501-MCLK-Pad10).
Reconnected via from CODEC_MCLK to unconnected-(IC501-MCLK-Pad10).
Removed unused net EFFECT_IN_BUF.
Removed unused net unconnected-(U301-EN-Pad5).
Reconnected C505 pin 2 from GND to unconnected-(C505-Pad2).
Reconnected via from CODEC_SDTO to unconnected-(IC501-SDTO-Pad13).
Reconnected via from DAC_L_N to unconnected-(IC501-AOUTL--Pad27).
Reconnected via from DAC_L_N to unconnected-(IC501-AOUTL--Pad27).
Reconnected via from DAC_R_N to unconnected-(IC501-AOUTR--Pad29).
Reconnected via from DAC_R_N to unconnected-(IC501-AOUTR--Pad29).
Removed unused net EFFECT_IN.
Removed unused net DAC_R_P.
Removed unused net DAC_R_N.
Removed unused net DAC_L_P.
Removed unused net DAC_L_N.
Removed unused net CODEC_SDTO.
Removed unused net CODEC_SDTI.
Removed unused net CODEC_PDN.
Removed unused net CODEC_MCLK.
Removed unused net CODEC_LRCK.
Removed unused net CODEC_CSN.
Removed unused net CODEC_CDTI.
Removed unused net CODEC_CCLK.
Removed unused net CODEC_BICK.
Removed unused net ADC_R_P.
Removed unused net ADC_R_N.
Removed unused net ADC_L_P.
Removed unused net ADC_L_N.
Removed unused net /Power/SW.
Removed unused net /Power/LDO_OUT.
Removed unused net /Power/LDO_IN.
Removed unused net /Power/DC_F.
Reconnected via from VCOM_B to unconnected-(R707-Pad2).
Reconnected via from VCOM_B to unconnected-(R707-Pad2).
Reconnected via from VCOM_B to unconnected-(R707-Pad2).
Reconnected via from VCOM_B to unconnected-(R707-Pad2).
Reconnected via from VCOM_B to unconnected-(R707-Pad2).
Reconnected via from VCOM_B to unconnected-(R707-Pad2).
Reconnected via from VCOM_B to unconnected-(R707-Pad2).
Removed unused net /Power/BUCK_FBT.
Removed unused net /Power/BUCK_FB.
Reconnected copper zone 'GND plane' from GND to unconnected-(J402-PadS).
Removed unused footprint R202.
Removed unused footprint C705.
Removed unused footprint U301.
Removed unused footprint RV102.
Removed unused footprint R705.
Removed unused footprint R409.
Removed unused footprint C702.
Removed unused footprint R601.
Removed unused footprint R413.
Removed unused footprint C310.
Removed unused footprint R718.
Removed unused footprint C304.
Removed unused footprint C608.
Removed unused footprint U601.
Removed unused footprint C607.
Removed unused footprint R505.
Removed unused footprint R417.
Removed unused footprint D406.
Removed unused footprint C501.
Removed unused footprint C610.
Removed unused footprint Y201.
Removed unused footprint U702.
Removed unused footprint C706.
Removed unused footprint U302.
Removed unused footprint J405.
Removed unused footprint J408.
Removed unused footprint C306.
Removed unused footprint R418.
Removed unused footprint C308.
Removed unused footprint R301.
Removed unused footprint C212.
Removed unused footprint D302.
Removed unused footprint C102.
Removed unused footprint D402.
Removed unused footprint R504.
Removed unused footprint C301.
Removed unused footprint R407.
Removed unused footprint C701.
Removed unused footprint R501.
Removed unused footprint C606.
Removed unused net /Power/BUCK_BOOT.
Removed unused footprint U201.
Removed unused footprint C201.
Removed unused footprint R203.
Removed unused footprint C601.
Removed unused footprint C410.
Removed unused footprint C502.
Removed unused footprint C604.
Removed unused footprint R105.
Removed unused footprint R101.
Removed unused footprint R704.
Removed unused net /MCU/VCAP2.
Removed unused footprint C408.
Removed unused footprint R702.
Removed unused footprint RV105.
Removed unused footprint Q401.
Removed unused footprint U501.
Removed unused footprint R201.
Removed unused footprint C605.
Removed unused footprint R416.
Removed unused footprint C411.
Removed unused footprint R716.
Removed unused footprint C103.
Removed unused footprint FB303.
Removed unused footprint R715.
Removed unused footprint C203.
Removed unused footprint R717.
Removed unused footprint R703.
Removed unused footprint R102.
Removed unused footprint C311.
Removed unused footprint W201.
Removed unused footprint R706.
Removed unused footprint C312.
Removed unused footprint D405.
Removed unused footprint C207.
Removed unused footprint R302.
Removed unused footprint C302.
Removed unused footprint R708.
Removed unused footprint C307.
Removed unused footprint C202.
Removed unused footprint Q402.
Removed unused footprint C703.
Removed unused footprint R103.
Removed unused footprint C205.
Removed unused footprint RV103.
Removed unused footprint K401.
Removed unused footprint R714.
Removed unused footprint C609.
Removed unused footprint U701.
Removed unused footprint C503.
Removed unused footprint C210.
Removed unused footprint C204.
Removed unused footprint C303.
Removed unused footprint C209.
Removed unused footprint C208.
Removed unused footprint C704.
Removed unused footprint R602.
Removed unused footprint C101.
Removed unused footprint L301.
Removed unused footprint U401.
Removed unused footprint R719.
Removed unused footprint R606.
Removed unused footprint R405.
Removed unused footprint Q403.
Removed unused footprint R710.
Removed unused footprint R603.
Removed unused net /MCU/VCAP1.
Removed unused footprint R415.
Removed unused footprint C412.
Removed unused footprint R701.
Removed unused footprint R406.
Removed unused footprint RV101.
Removed unused footprint D114.
Removed unused footprint C214.
Removed unused footprint R709.
Removed unused footprint C206.
Removed unused footprint FB301.
Removed unused footprint D301.
Removed unused footprint J407.
Removed unused footprint FB201.
Removed unused footprint C105.
Removed unused footprint R412.
Removed unused footprint C409.
Removed unused footprint R414.
Removed unused footprint C305.
Removed unused footprint R107.
Removed unused footprint C602.
Removed unused footprint C309.
Removed unused footprint R711.
Removed unused footprint C707.
Removed unused footprint R108.
Removed unused footprint R605.
Removed unused footprint R408.
Removed unused footprint C211.
Removed unused footprint D404.
Removed unused footprint C603.
Removed unused footprint R204.
Removed unused footprint R303.
Removed unused footprint C509.
Removed unused footprint R604.
Removed unused footprint FB302.
Removed unused footprint R411.
Removed unused footprint R410.
Removed unused net /MCU/SWO.
Removed unused footprint J403.
Removed unused footprint J404.
Removed unused footprint J406.
Removed unused footprint C104.
Removed unused footprint C611.
Removed unused footprint C612.
Removed unused footprint C613.
Removed unused footprint C614.
Removed unused footprint C615.
Removed unused footprint C616.
Removed unused footprint C617.
Removed unused footprint C618.
Removed unused footprint C708.
Removed unused footprint C709.
Removed unused footprint R607.
Removed unused footprint R608.
Removed unused footprint R609.
Removed unused footprint R610.
Removed unused footprint R611.
Removed unused footprint R612.
Removed unused footprint R720.
Removed unused footprint R721.
Removed unused footprint R722.
Removed unused footprint U202.
Removed unused net +3V3.
Removed unused net +5V.
Removed unused net +9V.
Removed unused net /ADC Driver/FDA_INN.
Removed unused net /ADC Driver/FDA_INP.
Removed unused net /ADC Driver/FDA_OUTN.
Removed unused net /ADC Driver/FDA_OUTP.
Removed unused net /ADC Driver/FDB_INN.
Removed unused net /ADC Driver/FDB_INP.
Removed unused net /ADC Driver/FDB_OUTN.
Removed unused net /ADC Driver/FDB_OUTP.
Removed unused net /Analog In and Out/IN_AC.
Removed unused net /Analog In and Out/IN_AC_R.
Removed unused net /Analog In and Out/IN_BUF_OUT.
Removed unused net /Analog In and Out/IN_BUF_OUT_R.
Removed unused net /Analog In and Out/IN_FB.
Removed unused net /Analog In and Out/IN_GAIN.
Removed unused net /Analog In and Out/OUTL_AC.
Removed unused net /Analog In and Out/OUTL_AMP.
Removed unused net /Analog In and Out/OUTL_N.
Removed unused net /Analog In and Out/OUTL_P.
Removed unused net /Analog In and Out/OUTR_AC.
Removed unused net /Analog In and Out/OUTR_AMP.
Removed unused net /Analog In and Out/OUTR_N.
Removed unused net /Analog In and Out/OUTR_P.
Removed unused net /Codec/PDN.
Removed unused net /Codec/VCOM.
Removed unused net /Codec/VCOM_A_RAW.
Removed unused net /Codec/VCOM_B_RAW.
Removed unused net /Controls and LEDs/POT1_W.
Removed unused net /Controls and LEDs/POT2_W.
Removed unused net /Controls and LEDs/POT3_W.
Removed unused net /Controls and LEDs/POT5_W.
Removed unused net /Jacks and Bypass/EXP_BUF_IN.
Removed unused net /Jacks and Bypass/EXP_BUF_OUT.
Removed unused net /Jacks and Bypass/EXP_RING.
Removed unused net /Jacks and Bypass/EXP_TIP.
Removed unused net /Jacks and Bypass/FSW_BYPASS.
Removed unused net /Jacks and Bypass/FSW_HOLD.
Removed unused net /Jacks and Bypass/IN.
Removed unused net /Jacks and Bypass/LED_EFF_G.
Removed unused net /Jacks and Bypass/LED_EFF_K.
Removed unused net /Jacks and Bypass/LED_EFF_LOW.
Removed unused net /Jacks and Bypass/LED_HOLD_G.
Removed unused net /Jacks and Bypass/LED_HOLD_K.
Removed unused net /Jacks and Bypass/LED_HOLD_LOW.
Removed unused net /Jacks and Bypass/OUT_L.
Removed unused net /Jacks and Bypass/RELAY_COIL.
Removed unused net /Jacks and Bypass/RELAY_G.
Removed unused net /Jacks and Bypass/RELAY_LOW.
Removed unused net /MCU/BOOT0.
Removed unused net /MCU/HSE_IN.
Removed unused net /MCU/HSE_OUT.
Removed unused net /MCU/NRST.
Removed unused net /MCU/QSPI_CLK.
Removed unused net /MCU/QSPI_IO0.
Removed unused net /MCU/QSPI_IO1.
Removed unused net /MCU/QSPI_IO2.
Removed unused net /MCU/QSPI_IO3.
Removed unused net /MCU/QSPI_NCS.
Removed unused net /MCU/SWCLK.
Removed unused net /MCU/SWCLK_N.
Removed unused net /MCU/SWDIO.
Reconnected via from CODEC_SDTO to unconnected-(IC501-SDTO-Pad13).
Warning: Could not remove unused footprint J401 (footprint is locked).
Warning: Could not remove unused footprint SW101 (footprint is locked).
Warning: Could not remove unused footprint SW103 (footprint is locked).
Warning: Could not remove unused footprint SW102 (footprint is locked).
Warning: Via connected to unknown net (VDDA).
Warning: Via connected to unknown net (VDDA).
Warning: Via connected to unknown net (VCOM_A).
Warning: Via connected to unknown net (VCOM_A).
Warning: Via connected to unknown net (TOG2_A).
Warning: Via connected to unknown net (TOG2_A).
Warning: Via connected to unknown net (RELAY_DRV).
Warning: Via connected to unknown net (POT5).
Warning: Via connected to unknown net (POT5).
Warning: Via connected to unknown net (POT5).
Warning: Via connected to unknown net (POT2).
Warning: Via connected to unknown net (POT2).
Warning: Via connected to unknown net (OLED_SDA).
Warning: Via connected to unknown net (OLED_SDA).
Warning: Via connected to unknown net (OLED_SDA).
Warning: Via connected to unknown net (OLED_SCL).
Warning: Via connected to unknown net (OLED_SCL).
Warning: Via connected to unknown net (OLED_SCL).
Warning: Via connected to unknown net (FSW_HOLD_IN).
Warning: Via connected to unknown net (EXP).
Warning: Via connected to unknown net (EXP).
Warning: Via connected to unknown net (EXP).
Warning: Via connected to unknown net (EFFECT_OUT_L).
Warning: Via connected to unknown net (EFFECT_IN).
Warning: Via connected to unknown net (CODEC_PDN).
Warning: Via connected to unknown net (/Power/SW).
Warning: Via connected to unknown net (/Power/SW).
Warning: Via connected to unknown net (/Power/SW).
Warning: Via connected to unknown net (/Power/LDO_OUT).
Warning: Via connected to unknown net (/Power/LDO_OUT).
Warning: Via connected to unknown net (/Power/LDO_IN).
Warning: Via connected to unknown net (/Power/LDO_IN).
Warning: Via connected to unknown net (/MCU/VCAP2).
Warning: Via connected to unknown net (/MCU/VCAP2).
Warning: Via connected to unknown net (/MCU/SWO).
Warning: Via connected to unknown net (/MCU/SWDIO_N).
Warning: Via connected to unknown net (/MCU/SWDIO).
Warning: Via connected to unknown net (/MCU/SWDIO).
Warning: Via connected to unknown net (/MCU/SWCLK_N).
Warning: Via connected to unknown net (/MCU/SWCLK).
Warning: Via connected to unknown net (/MCU/SWCLK).
Warning: Via connected to unknown net (/MCU/QSPI_NCS).
Warning: Via connected to unknown net (/MCU/QSPI_NCS).
Warning: Via connected to unknown net (/MCU/QSPI_IO3).
Warning: Via connected to unknown net (/MCU/QSPI_IO3).
Warning: Via connected to unknown net (/MCU/QSPI_IO2).
Warning: Via connected to unknown net (/MCU/QSPI_IO2).
Warning: Via connected to unknown net (/MCU/QSPI_IO1).
Warning: Via connected to unknown net (/MCU/QSPI_IO1).
Warning: Via connected to unknown net (/MCU/QSPI_IO0).
Warning: Via connected to unknown net (/MCU/QSPI_IO0).
Warning: Via connected to unknown net (/MCU/QSPI_CLK).
Warning: Via connected to unknown net (/MCU/QSPI_CLK).
Warning: Via connected to unknown net (/MCU/HSE_OUT).
Warning: Via connected to unknown net (/MCU/HSE_OUT).
Warning: Via connected to unknown net (/MCU/HSE_IN).
Warning: Via connected to unknown net (/MCU/HSE_IN).
Warning: Via connected to unknown net (/MCU/BOOT0).
Warning: Via connected to unknown net (/MCU/BOOT0).
Warning: Via connected to unknown net (/Jacks and Bypass/RELAY_G).
Warning: Via connected to unknown net (/Jacks and Bypass/RELAY_G).
Warning: Via connected to unknown net (/Jacks and Bypass/RELAY_G).
Warning: Via connected to unknown net (/Jacks and Bypass/RELAY_G).
Warning: Via connected to unknown net (/Jacks and Bypass/RELAY_COIL).
Warning: Via connected to unknown net (/Jacks and Bypass/RELAY_COIL).
Warning: Via connected to unknown net (/Jacks and Bypass/LED_EFF_G).
Warning: Via connected to unknown net (/Jacks and Bypass/LED_EFF_G).
Warning: Via connected to unknown net (/Jacks and Bypass/FSW_HOLD).
Warning: Via connected to unknown net (/Jacks and Bypass/FSW_HOLD).
Warning: Via connected to unknown net (/Jacks and Bypass/EXP_TIP).
Warning: Via connected to unknown net (/Jacks and Bypass/EXP_BUF_OUT).
Warning: Via connected to unknown net (/Jacks and Bypass/EXP_BUF_OUT).
Warning: Via connected to unknown net (/Jacks and Bypass/EXP_BUF_IN).
Warning: Via connected to unknown net (/Jacks and Bypass/EXP_BUF_IN).
Warning: Via connected to unknown net (/Controls and LEDs/POT5_W).
Warning: Via connected to unknown net (/Controls and LEDs/POT1_W).
Warning: Via connected to unknown net (/Controls and LEDs/POT1_W).
Warning: Via connected to unknown net (/Analog In and Out/OUTR_P).
Warning: Via connected to unknown net (/Analog In and Out/OUTR_P).
Warning: Via connected to unknown net (/Analog In and Out/OUTL_N).
Warning: Via connected to unknown net (/Analog In and Out/OUTL_N).
Warning: Via connected to unknown net (/Analog In and Out/OUTL_AMP).
Warning: Via connected to unknown net (/Analog In and Out/OUTL_AMP).
Warning: Via connected to unknown net (/Analog In and Out/OUTL_AC).
Warning: Via connected to unknown net (/Analog In and Out/OUTL_AC).
Warning: Via connected to unknown net (/Analog In and Out/IN_BUF_OUT_R).
Warning: Via connected to unknown net (/Analog In and Out/IN_BUF_OUT_R).
Warning: Via connected to unknown net (/ADC Driver/FDB_OUTP).
Warning: Via connected to unknown net (/ADC Driver/FDB_OUTP).
Warning: Via connected to unknown net (/ADC Driver/FDB_INN).
Warning: Via connected to unknown net (/ADC Driver/FDB_INN).
Warning: Via connected to unknown net (/ADC Driver/FDB_INN).
Warning: Via connected to unknown net (/ADC Driver/FDA_OUTP).
Warning: Via connected to unknown net (/ADC Driver/FDA_OUTP).
Warning: Via connected to unknown net (/ADC Driver/FDA_OUTN).
Warning: Via connected to unknown net (/ADC Driver/FDA_OUTN).
Warning: Via connected to unknown net (/ADC Driver/FDA_OUTN).
Warning: Via connected to unknown net (/ADC Driver/FDA_INP).
Warning: Via connected to unknown net (/ADC Driver/FDA_INP).
Warning: Via connected to unknown net (/ADC Driver/FDA_INN).
Warning: Via connected to unknown net (/ADC Driver/FDA_INN).
Warning: Via connected to unknown net (CODEC_PDN).
Warning: Via connected to unknown net (/ADC Driver/FDA_INN).

Info: Total warnings: 107, errors: 0.

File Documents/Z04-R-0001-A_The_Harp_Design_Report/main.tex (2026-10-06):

% ============================================================
%  The Harp Design Report
%  Z04-R-0001-A  --  The Frogmouth
%
%  Build:  xelatex -interaction=nonstopmode -output-directory=build main.tex
%          Run from inside this folder; build/chapters must exist first.
%  Style:  packages/frogmouth.sty -- requires XeLaTeX or LuaLaTeX for the
%          brand fonts; add [nofonts] below to build under pdfLaTeX.
%
%  Sources: docs/design-brief.md, docs/pcb-plan.md and
%  docs/firmware-requirements.md in this repository, and the schematic in
%  kicad/the_harp/. Where this report and those documents disagree, they
%  are the working record and this report is updated to match.
% ============================================================
\documentclass[11pt, a4paper, openany]{report}

\usepackage[bone]{packages/frogmouth} % [paper] for plain white, [nofonts] to build under pdflatex

\usepackage{longtable}
\usepackage{amsmath}
\usepackage{float}    % [H] table placement
\emergencystretch=3em

\fmdocid{Z04-R-0001-A}

% Title-page plate, keyed to the document type. Guarded so this file still
% builds against an older bundled frogmouth.sty that predates cover schemes.
\ifdefined\fmcoverscheme\fmcoverscheme{report}\fi
\fmproject{The Harp}

\title{The Harp Design Report}
\author{Allan Waller}

\setlength{\headheight}{14pt}
\begin{document}

\fmtitlepage
  {The Harp\\Design Report}
  {Concept, hardware architecture, schematic, board plan and firmware
   requirements for The Harp, a digital sympathetic-string pedal: up to 24
   modelled strings that ring when the guitar plays their note, retuned
   continuously to the chord being played. This revision records the design
   as a first generated schematic and a seeded board; nothing has been
   built, placed or measured.}
  {Allan Waller \textemdash\ The Frogmouth \textemdash\ Made in Belgium}
  {Z04-R-0001-A \textemdash\ Revision A \textemdash\ \today}

% ---------- Contents ----------
\pagenumbering{roman}
\tableofcontents
\clearpage

\pagenumbering{arabic}

\include{chapters/01_executive_summary}
\include{chapters/02_concept_requirements}
\include{chapters/03_hardware_architecture}
\include{chapters/04_schematic_design}
\include{chapters/05_pcb_mechanical}
\include{chapters/06_firmware_design}
\include{chapters/07_cost}
\include{chapters/08_risks_open_items}

\end{document}

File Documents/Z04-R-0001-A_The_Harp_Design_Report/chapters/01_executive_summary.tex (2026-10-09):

\chapter{Executive Summary}\label{ch:summary}

The Harp is a digital sympathetic-string pedal. Behind the guitar sit up to 24 digitally modelled strings that nobody plays. They ring when the guitar sounds a note they are tuned to, as the taraf strings of a sitar or the under-strings of a Hardanger fiddle do. The pedal listens to the chord being played and keeps retuning the strings to it, so every note leaves a halo in the player's own harmony. The intended sound is tuned ambience: it is not a reverb and not a shimmer.

The category neighbours are the Hologram Microcosm, the Chase Bliss Mood and the Strymon ambience pedals, at 300 to 450\,EUR. None of them does chord-following sympathetic strings.

\section{Hardware in One Paragraph}
The Harp is a cut-down Timekeeper (25-Z01-0001) on the hardware set shared with The Alchemist (26-A02-0001) and The Relic (26-A03-0003). It uses the Timekeeper's AK4621EF codec, W25Q128 QSPI flash, buck converter, input and output stages, and The Relic's relay bypass. The MCU is an STM32H750VBT6 in LQFP-100 rather than the Timekeeper's LQFP-144, and there is no SDRAM: the 24 strings need about 100\,KB of delay memory and the H750 has 1\,MB internal. There is no screen. A 0.91\,in OLED strip shows the tuning, and four pots and three ON-ON-ON toggles replace the Timekeeper's encoders. Everything sits on one four-layer 56 by 90\,mm board in a Hammond 125B, with the jacks, DC jack, knobs and footswitches at the same positions and heights as The Alchemist and The Relic.

\section{Status at Revision A}
\begin{itemize}
  \item \textbf{Schematic.} A first draft of seven sheets and 190 parts, generated by \texttt{scripts/harp\_schematic/build\_layout.py} (stereo input and OLED display added 2026-10-08) and net-traced against its specification. It has not yet been opened in KiCad, and ERC has not been run.
  \item \textbf{Board.} The Relic's outline, four-layer stack and design rules, with 28 face, jack and bypass footprints placed. The remaining parts are not placed and nothing is routed.
  \item \textbf{Firmware.} A requirements draft exists (\texttt{docs/firmware-requirements.md}); no code is written. The engine is to be developed first on the Timekeeper board.
  \item \textbf{Measurements.} None. The CPU load of the string bank, the chord tracker's accuracy and every audio figure in this report are estimates or targets.
\end{itemize}

\section{Decisions Taken}
Thirteen design decisions were recorded between 2026-10-04 and 2026-10-06; they are listed in Chapter~\ref{ch:architecture}. The ones that shape everything else are: one relay with true bypass on OUT~L only and a Trails mode in firmware for stereo players; one board unless placement fails; pots rather than encoders, with four knobs and three ON-ON-ON toggles laid out as on The Alchemist; an STM32H750VBT6 with no SDRAM; the dry signal through the codec; and an OPA2365 input buffer on the 5\,V rail with a jack-to-ADC gain of 0.59.

\section{What Comes Next}
Firmware comes first, on the Timekeeper board. It proves the sound and gives the CPU figure before any Harp PCB is committed. In parallel, the schematic is opened in KiCad for ERC, and placement decides whether the one-board plan holds. Chapter~\ref{ch:risks} lists the open items and the order of work.

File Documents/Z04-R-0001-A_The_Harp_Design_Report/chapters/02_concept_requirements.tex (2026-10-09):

\chapter{Concept and Requirements}\label{ch:concept}

\section{Signal Path}
The input is stereo or mono and the output stereo, single-ended at every jack. The IN jack is TRS, tip left and ring right. The tip passes the relay into the input buffer and the codec's left ADC; the ring goes through its own buffer to the codec's right ADC. A mono plug grounds the ring, the right channel reads silence and the firmware copies left to right. The H750 runs the chord tracker and the string bank and mixes dry and wet. The codec's two DAC channels feed the left and right output buffers, and both outputs return through the relay. An expression pedal on a TRS jack goes through its own buffer to an MCU ADC input.

{\small
\begin{verbatim}
IN -> relay -> input buffer -> ADC (codec L) -> H750
     H750: front end -> chord tracker -> tuning manager
                     -> string bank x24 -> stereo spread
           dry + wet mix -> DAC L -> out buffer -> relay -> OUT L
                         -> DAC R -> out buffer -> relay -> OUT R
EXP (TRS) -> buffer -> H750 ADC
\end{verbatim}
}
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

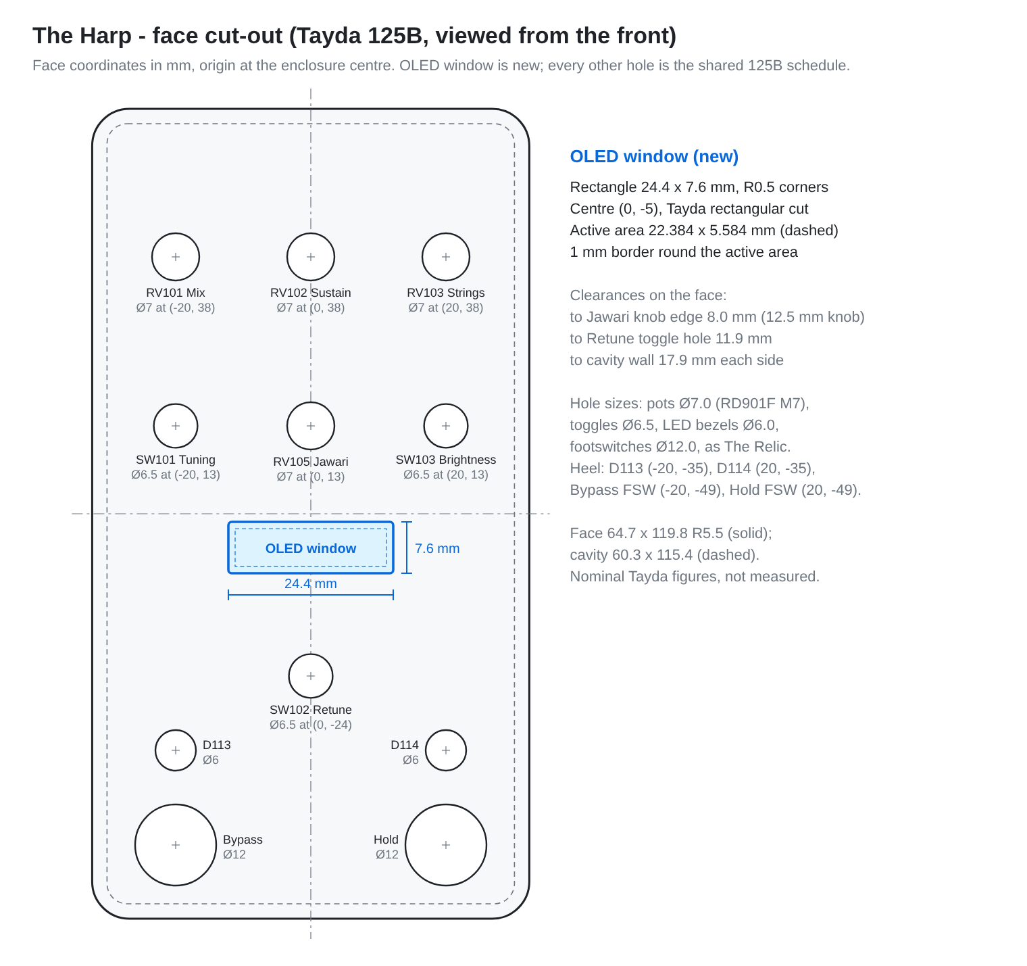
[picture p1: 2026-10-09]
docs/images/oled-face-cutout.png

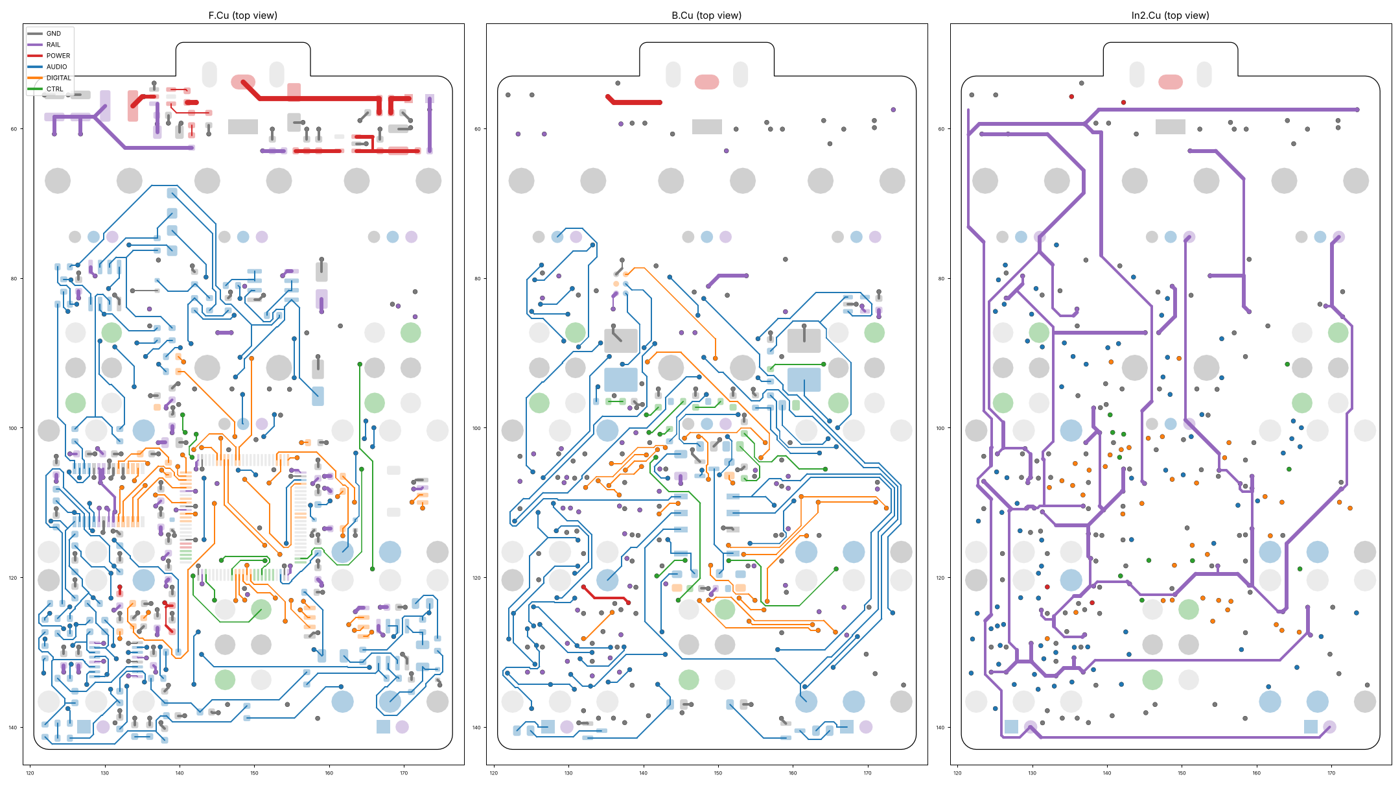
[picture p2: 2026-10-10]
docs/images/pcb-routing.png

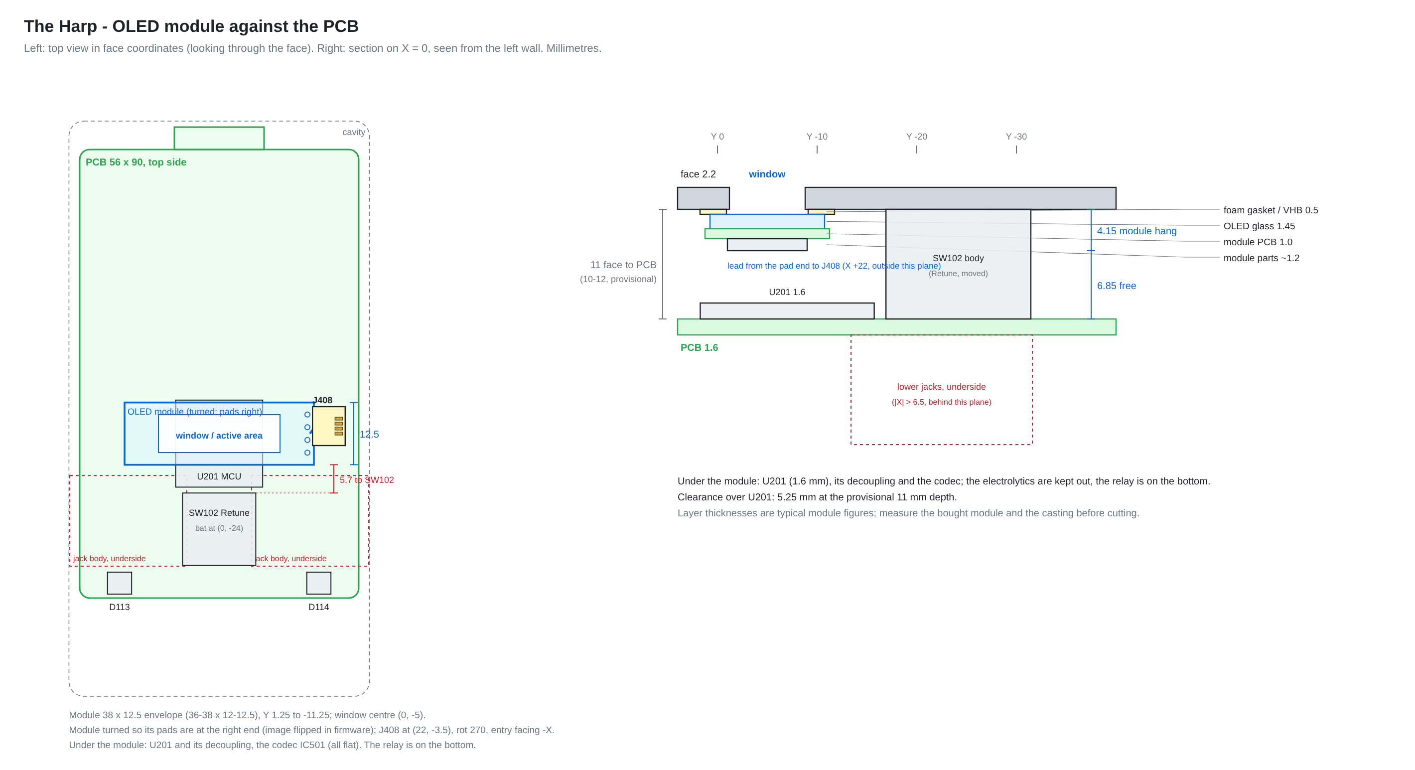
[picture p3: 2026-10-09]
docs/images/oled-pcb-relation.png

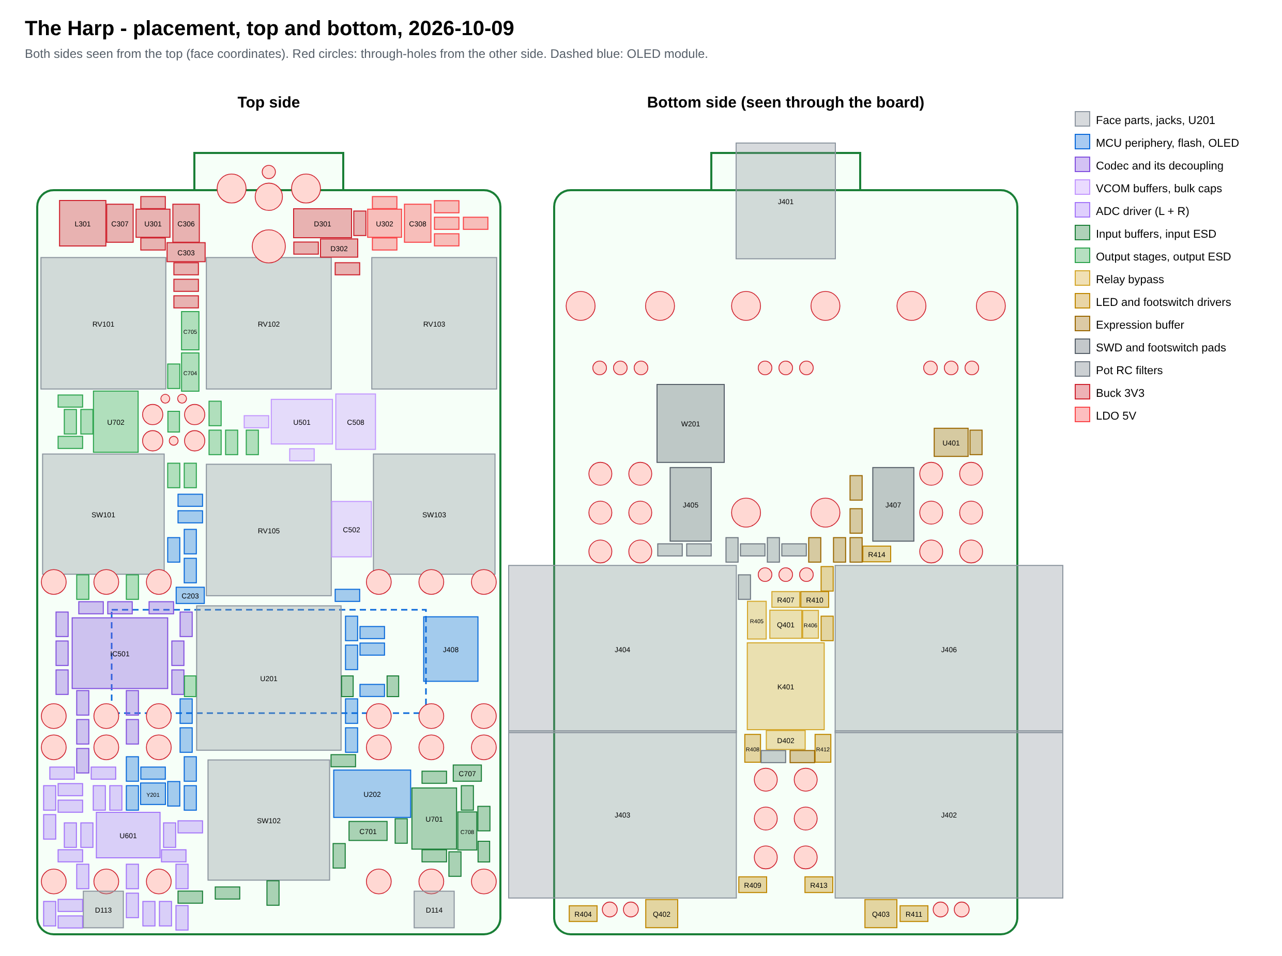
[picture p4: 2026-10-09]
docs/images/pcb-placement.png

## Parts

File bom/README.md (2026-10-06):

# Bill of materials

Generated by `scripts/export_bom.py` from the KiCad schematics under
`kicad/the_harp/`. Not yet created: adapt The Relic's exporter once
the schematic exists. Do not hand-edit the CSVs or the workbook. Every symbol
carries Manufacturer, Mfg Part # and LCSC properties, as in The Relic.

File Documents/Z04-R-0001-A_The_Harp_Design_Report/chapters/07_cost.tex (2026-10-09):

\chapter{Cost Target}\label{ch:cost}

The estimate starts from The Relic's (46.20\,EUR at a quantity of 100). The electronics roughly double; the enclosure, assembly and packaging are the same. No part has been carted and the BOM has not been generated, so these are planning figures only.

\begin{table}[H]
  \small\renewcommand{\arraystretch}{1.12}
  \caption{Unit cost estimate at 100.}\label{tab:cost}
  \begin{tabularx}{\textwidth}{@{}L r@{}}
    \toprule
    \fmtophead{Group} & \fmtophead{EUR} \\
    \midrule
    H750, codec, flash, buck, LDO, op-amps, passives & 22.00 \\
    4 pots, 3 ON-ON-ON toggles, 2 momentary footswitches, 4 knobs, 2 LEDs and the 0.91\,in OLED module (replaces 12 LEDs and 12 light pipes; price to confirm) & 19.00 \\
    5 jacks, relay, footswitch pads & 7.00 \\
    125B enclosure, Tayda drilled and UV printed & 9.20 \\
    PCB (four layers), SMT assembly, freight, packaging allocation & 9.00 \\
    \midrule
    Estimate & 66.00 \\
    \bottomrule
  \end{tabularx}
\end{table}

At a retail price of 299\,EUR, which the category supports, this leaves roughly 165\,EUR gross before labour. Plan~B (two boards) would add about 3\,EUR. The BOM will be exported with The Relic's exporter, adapted, once the schematic has passed ERC; this chapter is then replaced by the exported cost.

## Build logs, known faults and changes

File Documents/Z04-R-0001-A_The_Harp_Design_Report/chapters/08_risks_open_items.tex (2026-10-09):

\chapter{Risks, Open Items and Next Steps}\label{ch:risks}

\section{Risks}
\begin{itemize}
  \item \textbf{Codec and H750 next to a high-impedance guitar input} on one 56 by 90\,mm board. Mitigation: The Relic's four-layer stack with an unbroken ground plane, the zoning in Chapter~\ref{ch:pcb}, and the buck converter at the DC end away from the input.
  \item \textbf{Chord tracker quality} on distorted or fast playing. Key and Drone modes do not depend on it, so the pedal still works if Follow is weak.
  \item \textbf{CPU load} of 24 strings, Jawari and the tracker together has not been measured.
  \item \textbf{Internal flash.} Whether the image fits the H750's 128\,KB is unknown.
  \item \textbf{AK4621EF lifecycle,} already flagged in the Timekeeper's BOM audit.
  \item \textbf{Height under the OLED}: parts placed under the module must stay below about 6.8\,mm; \req{K401} was moved out from under it on 2026-10-08.
\end{itemize}

\section{Open Items}
\begin{table}[H]
  \small\renewcommand{\arraystretch}{1.12}
  \caption{Open hardware and product items.}\label{tab:openhw}
  \begin{tabularx}{\textwidth}{@{}>{\raggedright\arraybackslash}p{38mm} L@{}}
    \toprule
    \fmtophead{Item} & \fmtophead{Status} \\
    \midrule
    Secondary layer & More settings than knobs: key or drone set, spread, bypass mode, expression target and range, Hold latching, Brightness trim, chord commit time, output trim. Pick a second page or drop some, on the prototype. \\
    Schematic confirmations & QUADSPI bank~2 alternate functions, OPA2365 noise at 1\,kHz, then ERC. \\
    Wall-hole heights & To be fixed from the NMJ6HCD2 and PJ-063AH drawings and the measured Alchemist and Relic assemblies; the Harp inherits them. \\
    Note display & Decided 2026-10-08: a 0.91\,in I$^2$C OLED strip. Content to settle on the prototype, using the Timekeeper's TFT as a stand-in. \\
    OLED fit & Measure the bought module and the casting depth; confirm the window on the active area and the carrier height. \\
    Expression input & TRS wiring and buffer as the Timekeeper (MCP6001); whether an empty jack can be detected depends on that buffer. \\
    Mono use & A mono plug on IN is detected by the right input reading silence (ring grounded), then L is copied to R. OUT~R unplugged is still not detected: choose a default spread or add a jack-detect line. \\
    Power-up state & Effect on, or the last state. \\
    Secondary-layer gesture & Both footswitches together, or holding Bypass. \\
    Code sharing with the Timekeeper & Copy the reused modules with the source commit recorded, or share them as a library. \\
    \bottomrule
  \end{tabularx}
\end{table}

\section{Discrepancies Between the Working Documents}
Writing this report found three small disagreements, to be corrected at the source:
\begin{itemize}
  \item The design brief's latency figure (one 256-sample block, about 6\,ms) does not match the Timekeeper's 64-frame block (about 1.5\,ms); the firmware requirements use the smaller figure.
  \item The firmware requirements put the expression input on PA6 [EXP-1]; the schematic and pin map use PB1, as the Timekeeper does.
  \item The firmware requirements name the footswitches J105 and J106; the schematic designators are \req{J405} (Bypass) and \req{J407} (Hold).
\end{itemize}

\section{Order of Work}
\begin{enumerate}
  \item \textbf{Firmware first on the Timekeeper board.} String bank with a fixed tuning, then Jawari, then the tuning manager in Key and Drone modes. Measure the CPU load and settle the TBC ranges by ear.
  \item Chord tracker and Follow mode, offline against reference recordings, then on the board.
  \item Open the schematic in KiCad and run ERC. Close the confirmation items.
  \item \emph{Update PCB from Schematic} (the board was synced and placed on both sides by script on 2026-10-08; expect net renames only). Look the placement over, then DRC. Decide double-sided assembly or hand fitting for the 37 bottom-side parts. \textbf{Go/no-go for Plan~A: it fits.}
  \item GND vias per The Relic's rule, routing (F.Cu short, B.Cu long, In2 power), DRC with The Relic's rules.
  \item Adapt The Relic's BOM exporter, cost at 100, and produce the Tayda drill schedule from the face table.
  \item Fix the wall-hole heights from the measured Alchemist and Relic assembly.
  \item Port the firmware to \texttt{BOARD\_HARP}, then bench measurements and the production test mode.
\end{enumerate}

\section{Source Documents}
\begin{itemize}
  \item \texttt{docs/design-brief.md}: what the pedal is, controls, bypass, cost and decisions.
  \item \texttt{docs/pcb-plan.md}: board plan, face schedule, zoning, schematic sheets, pin map and input-stage checks.
  \item \texttt{docs/firmware-requirements.md}: numbered firmware requirements, Draft~A.
  \item \texttt{kicad/the\_harp/} and \texttt{kicad/README.md}: the KiCad project.
  \item \texttt{scripts/harp\_schematic/}: the schematic generator and net checker.
  \item 25-Z01-0001 DSP Development Board: the Timekeeper schematic, firmware, input noise review and input-chain simulation.
  \item 26-A03-0003 The Relic and 26-A02-0001 The Alchemist: board outline, face standard, jacks, relay bypass and layout rules.
\end{itemize}

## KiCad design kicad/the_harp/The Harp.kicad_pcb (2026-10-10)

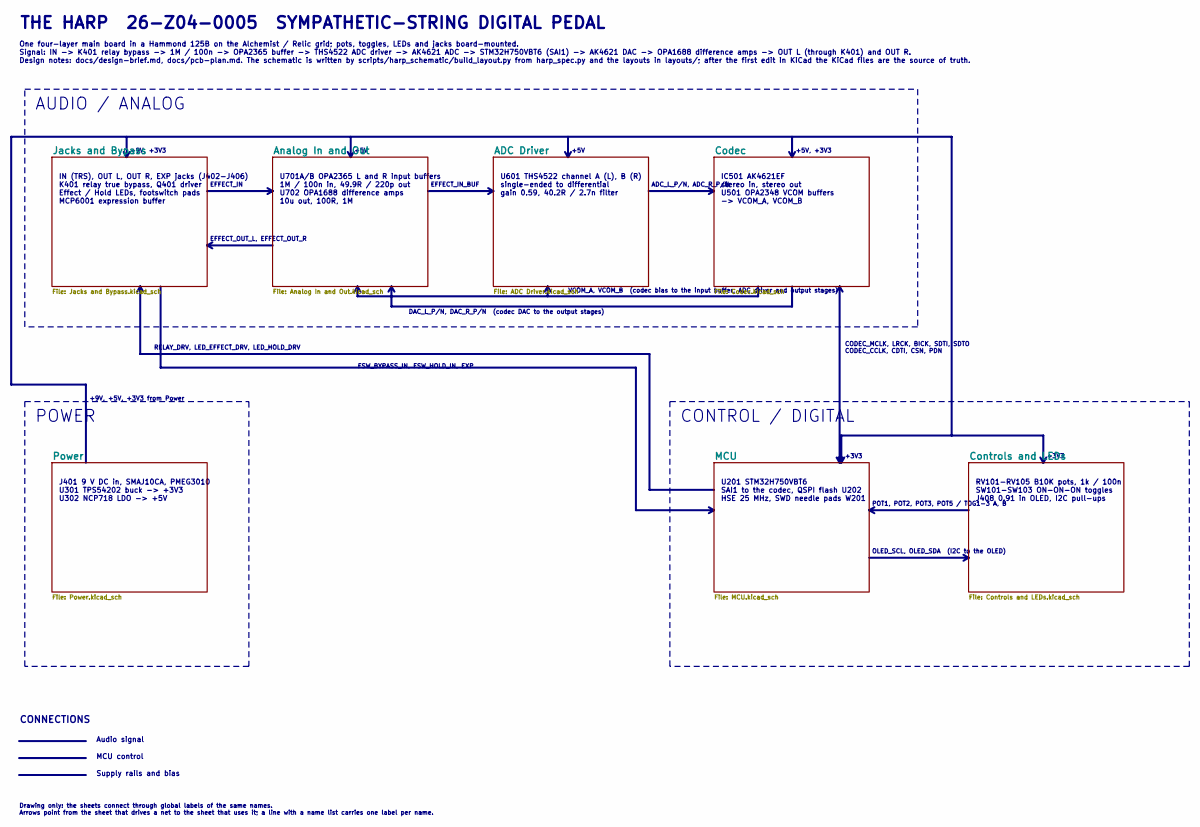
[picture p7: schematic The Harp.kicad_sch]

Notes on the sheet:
RELAY_DRV, LED_EFFECT_DRV, LED_HOLD_DRV
+5V, +3V3
J401 9 V DC in, SMAJ10CA, PMEG3010 U301 TPS54202 buck -> +3V3 U302 NCP718 LDO -> +5V
CONTROL / DIGITAL
+5V
EFFECT_OUT_L, EFFECT_OUT_R
DAC_L_P/N, DAC_R_P/N (codec DAC to the output stages)
THE HARP 26-Z04-0005 SYMPATHETIC-STRING DIGITAL PEDAL
FSW_BYPASS_IN, FSW_HOLD_IN, EXP
+9V, +5V, +3V3 from Power
Supply rails and bias
IC501 AK4621EF stereo in, stereo out U501 OPA2348 VCOM buffers -> VCOM_A, VCOM_B
POT1, POT2, POT3, POT5 / TOG1-3 A, B
EFFECT_IN_BUF
U601 THS4522 channel A (L), B (R) single-ended to differential gain 0.59, 40.2R / 2.7n filter
OLED_SCL, OLED_SDA (I2C to the OLED)
U701A/B OPA2365 L and R input buffers 1M / 100n in, 49.9R / 220p out U702 OPA1688 difference amps 10u out, 100R, 1M
Audio signal
+9V, +3V3
One four-layer main board in a Hammond 125B on the Alchemist / Relic grid; pots, toggles, LEDs and jacks board-mounted. Signal: IN -> K401 relay bypass -> 1M / 100n -> OPA2365 buffer -> THS4522 ADC driver -> AK4621 ADC -> STM32H750VBT6 (SAI1) -> AK4621 DAC -> OPA1688 difference amps -> OUT L (throu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
+3V3
U201 STM32H750VBT6 SAI1 to the codec, QSPI flash U202 HSE 25 MHz, SWD needle pads W201
MCU control
CODEC_MCLK, LRCK, BICK, SDTI, SDTO CODEC_CCLK, CDTI, CSN, PDN
POWER
IN (TRS), OUT L, OUT R, EXP jacks (J402-J406) K401 relay true bypass, Q401 driver Effect / Hold LEDs, footswitch pads MCP6001 expression buffer
RV101-RV105 B10K pots, 1k / 100n SW101-SW103 ON-ON-ON toggles J408 0.91 in OLED, I2C pull-ups
AUDIO / ANALOG
EFFECT_IN
VCOM_A, VCOM_B (codec bias to the input buffer, ADC driver and output stages)
CONNECTIONS
ADC_L_P/N, ADC_R_P/N
Drawing only: the sheets connect through global labels of the same names. Arrows point from the sheet that drives a net to the sheet that uses it; a line with a name list carries one label per name.

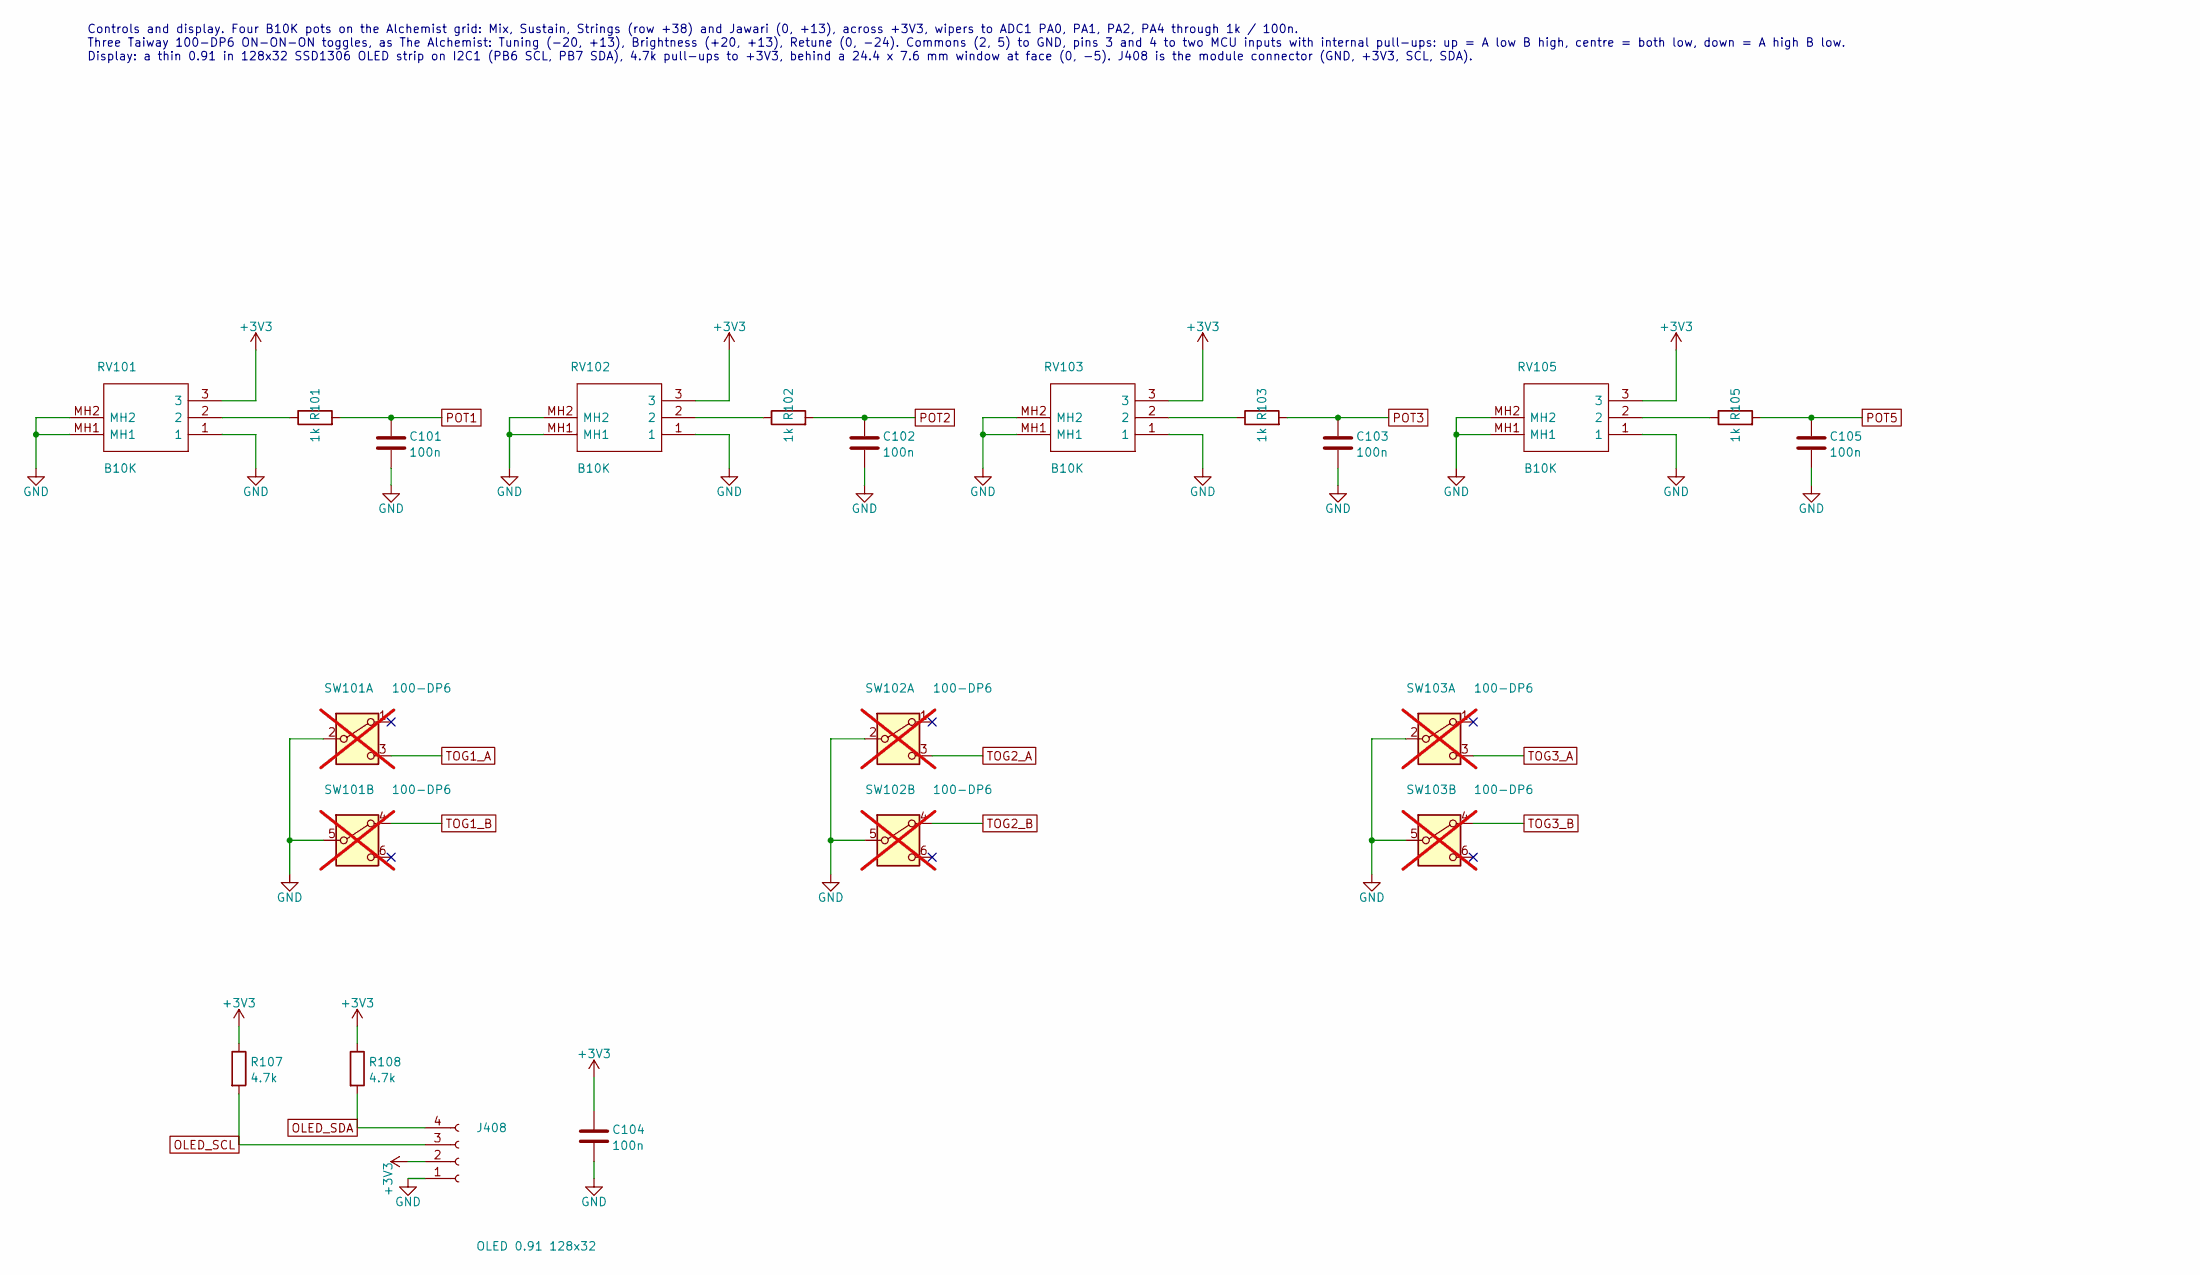
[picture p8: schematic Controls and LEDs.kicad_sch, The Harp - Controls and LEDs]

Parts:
C101, C102, C103, C104, C105: 100n; C_0603_1608Metric
J408: OLED 0.91 128x32; JST_SH_SM04B-SRSS-TB_1x04-1MP_P1.00mm_Horizontal; Mfg Part # SM04B-SRSS-TB
R101, R102, R103, R105: 1k; R_0603_1608Metric
R107, R108: 4.7k; R_0603_1608Metric
RV101, RV102, RV103, RV105: B10K; RD901F4015R1B10K00DL1; Mfg Part # RD901F-40-15R1-B10K; LCSC C20619174
SW101, SW102, SW103: 100-DP6; 100DP3T1B2M2QE; Mfg Part # 100-DP6-T200B1M2QE; not fitted

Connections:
+3V3: C104.1, J408.2, R107.1, R108.1, RV101.3, RV102.3, RV103.3, RV105.3; also elsewhere on the board
GND: C101.2, C102.2, C103.2, C104.2, C105.2, J408.1, RV101.1, RV101.MH1, RV101.MH2, RV102.1, RV102.MH1, RV102.MH2, RV103.1, RV103.MH1, RV103.MH2, RV105.1, RV105.MH1, RV105.MH2, SW101.2 (B), SW101.5 (B), SW102.2 (B), SW102.5 (B), SW103.2 (B), SW103.5 (B); also elsewhere on the board
unnamed: R101.1, RV101.2
unnamed: R102.1, RV102.2
unnamed: R103.1, RV103.2
unnamed: R105.1, RV105.2
OLED_SCL: J408.3, R107.2; also elsewhere on the board
OLED_SDA: J408.4, R108.2; also elsewhere on the board
POT1: C101.1, R101.2; also elsewhere on the board
POT2: C102.1, R102.2; also elsewhere on the board
POT3: C103.1, R103.2; also elsewhere on the board
POT5: C105.1, R105.2; also elsewhere on the board
TOG1_A: SW101.3 (C); also elsewhere on the board
TOG1_B: SW101.4 (A); also elsewhere on the board
TOG2_A: SW102.3 (C); also elsewhere on the board
TOG2_B: SW102.4 (A); also elsewhere on the board
TOG3_A: SW103.3 (C); also elsewhere on the board
TOG3_B: SW103.4 (A); also elsewhere on the board

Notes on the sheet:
Controls and display. Four B10K pots on the Alchemist grid: Mix, Sustain, Strings (row +38) and Jawari (0, +13), across +3V3, wipers to ADC1 PA0, PA1, PA2, PA4 through 1k / 100n. Three Taiway 100-DP6 ON-ON-ON toggles, as The Alchemist: Tuning (-20, +13), Brightness (+20, +13), Retune (0, -24). Comm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

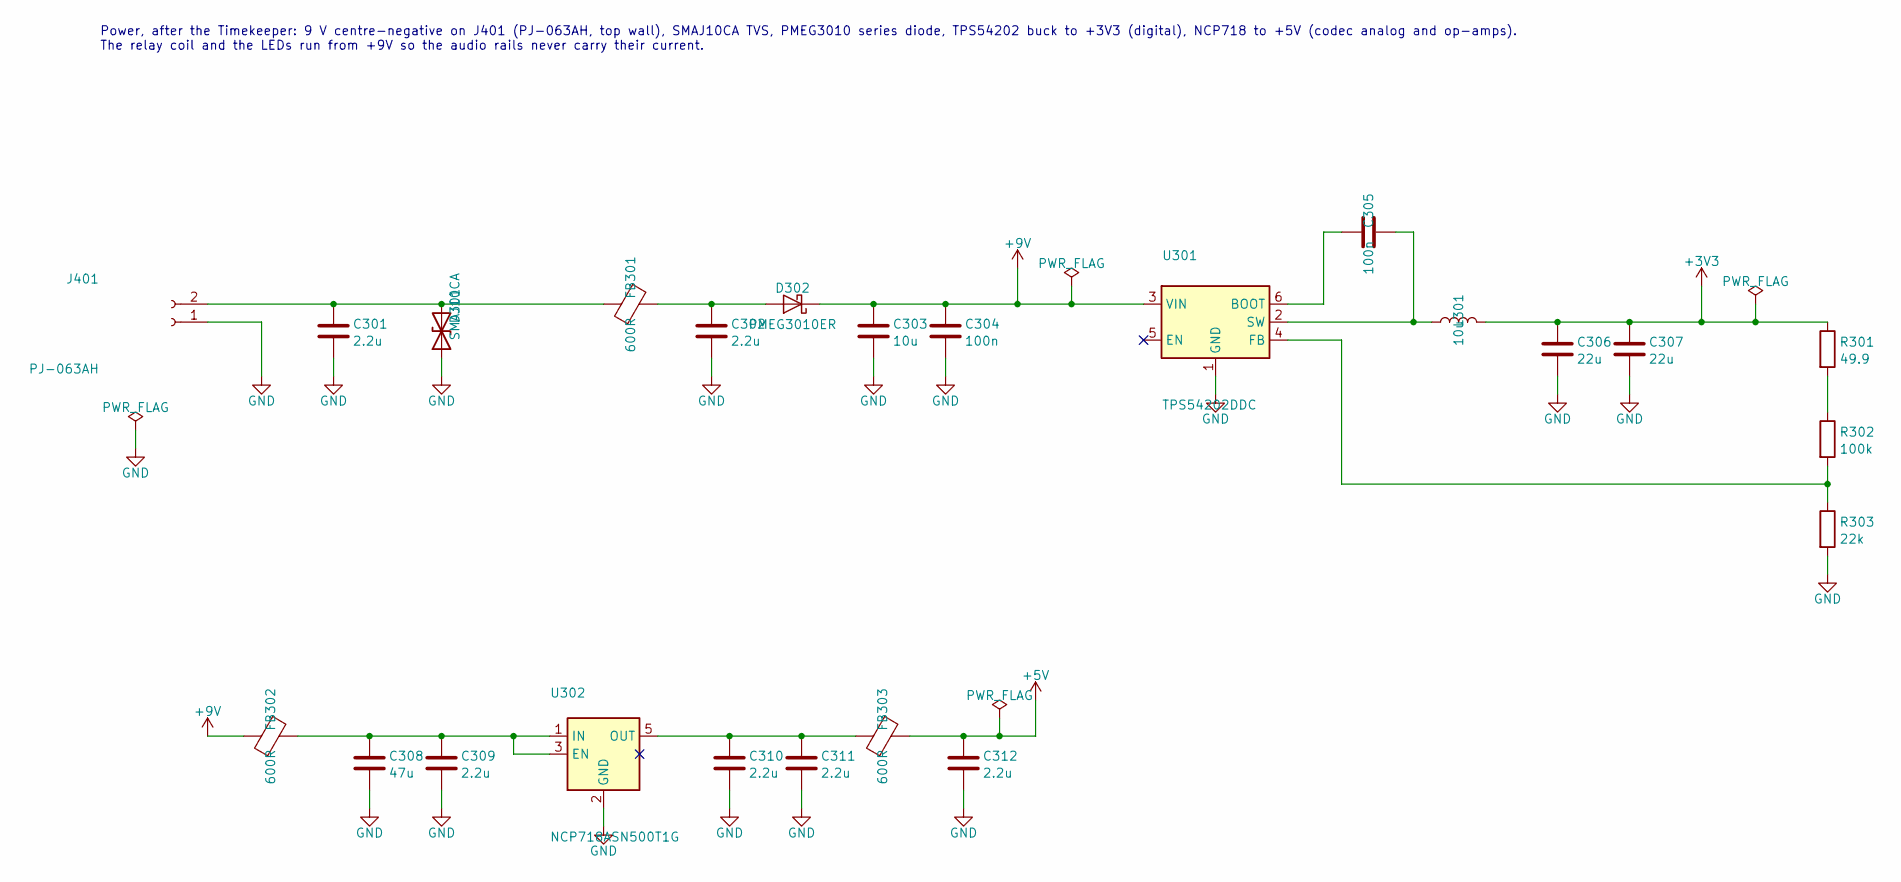
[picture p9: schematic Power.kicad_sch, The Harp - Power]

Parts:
C301, C302, C309, C310, C311, C312: 2.2u; C_0603_1608Metric
C303: 10u; C_1206_3216Metric
C304, C305: 100n; C_0603_1608Metric
C306, C307: 22u; C_1210_3225Metric
C308: 47u; C_1210_3225Metric
D301: SMAJ10CA; D_SMA; Mfg Part # SMAJ10CA
D302: PMEG3010ER; Nexperia_CFP3_SOD-123W; Mfg Part # PMEG3010ER,115
FB301, FB302, FB303: 600R; L_0603_1608Metric
J401: PJ-063AH; BarrelJack_CUI_PJ-063AH_Horizontal; Mfg Part # PJ-063AH; LCSC C22434582
L301: 10u; L_APV_ANR5020
R301: 49.9; R_0603_1608Metric
R302: 100k; R_0603_1608Metric
R303: 22k; R_0603_1608Metric
U301: TPS54202DDC; SOT-23-6; Mfg Part # TPS54202DDCR
U302: NCP718ASN500T1G; TSOT-23-5; Mfg Part # NCP718ASN500T1G; LCSC C603786

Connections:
+3V3: C306.1, C307.1, L301.2, R301.1; also elsewhere on the board
+5V: C312.1, FB303.2; also elsewhere on the board
+9V: C303.1, C304.1, D302.1 (K), FB302.1, U301.3 (VIN); also elsewhere on the board
GND: C301.2, C302.2, C303.2, C304.2, C306.2, C307.2, C308.2, C309.2, C310.2, C311.2, C312.2, D301.1 (A1), J401.1, R303.2, U301.1 (GND), U302.2 (GND); also elsewhere on the board
unnamed: C301.1, D301.2 (A2), FB301.1, J401.2
unnamed: C302.1, D302.2 (A), FB301.2
unnamed: R301.2, R302.1
unnamed: C305.1, U301.6 (BOOT)
unnamed: R302.2, R303.1, U301.4 (FB)
unnamed: C305.2, L301.1, U301.2 (SW)
unnamed: C308.1, C309.1, FB302.2, U302.1 (IN), U302.3 (EN)
unnamed: C310.1, C311.1, FB303.1, U302.5 (OUT)

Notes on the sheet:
Power, after the Timekeeper: 9 V centre-negative on J401 (PJ-063AH, top wall), SMAJ10CA TVS, PMEG3010 series diode, TPS54202 buck to +3V3 (digital), NCP718 to +5V (codec analog and op-amps). The relay coil and the LEDs run from +9V so the audio rails never carry their current.

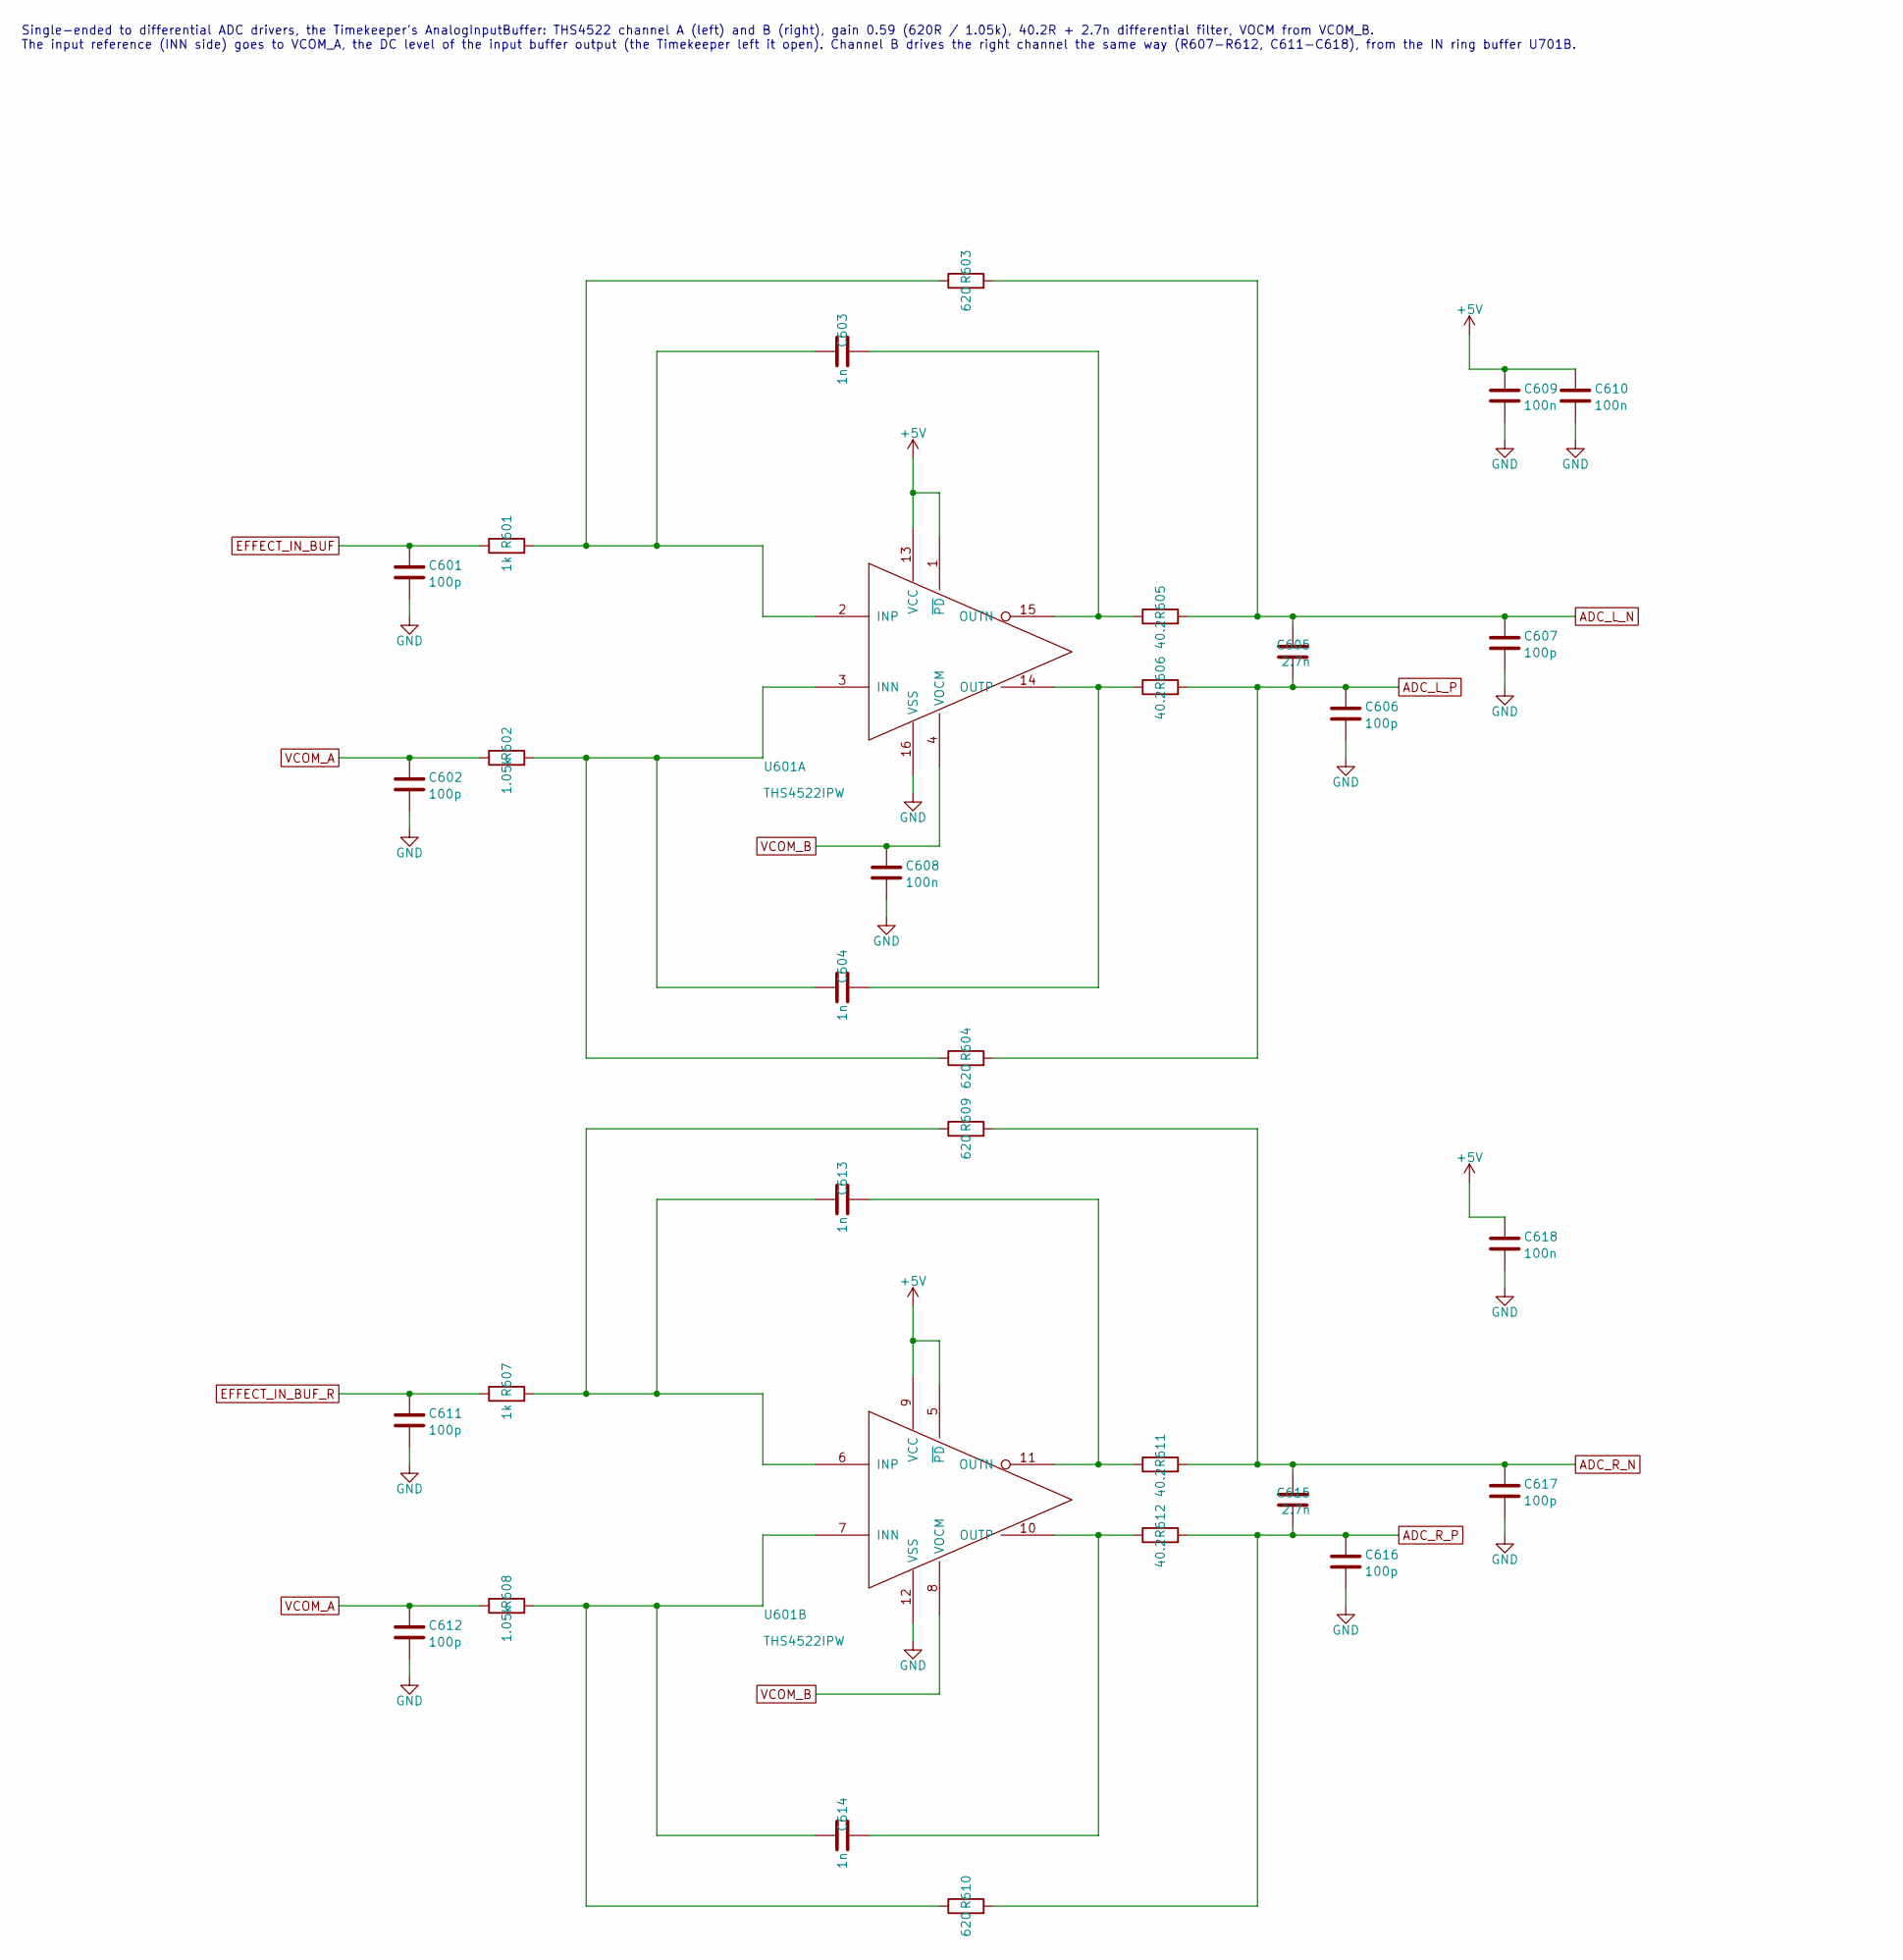
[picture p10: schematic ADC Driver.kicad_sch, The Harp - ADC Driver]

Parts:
C601, C602, C606, C607, C611, C612, C616, C617: 100p; C_0603_1608Metric
C603, C604, C613, C614: 1n; C_0603_1608Metric
C605, C615: 2.7n; C_0603_1608Metric
C608, C609, C610, C618: 100n; C_0603_1608Metric
R601, R607: 1k; R_0603_1608Metric
R602, R608: 1.05k; R_0603_1608Metric
R603, R604, R609, R610: 620; R_0603_1608Metric
R605, R606, R611, R612: 40.2; R_0603_1608Metric
U601: THS4522IPW; TSSOP-16_4.4x5mm_P0.65mm; Mfg Part # THS4522IPWR

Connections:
+5V: C609.1, C610.1, C618.1, U601.1 (~PD), U601.5 (~PD), U601.9 (VCC), U601.13 (VCC); also elsewhere on the board
ADC_L_N: C605.2, C607.1, R603.2, R605.2; also elsewhere on the board
ADC_L_P: C605.1, C606.1, R604.2, R606.2; also elsewhere on the board
ADC_R_N: C615.2, C617.1, R609.2, R611.2; also elsewhere on the board
ADC_R_P: C615.1, C616.1, R610.2, R612.2; also elsewhere on the board
EFFECT_IN_BUF: C601.1, R601.1; also elsewhere on the board
EFFECT_IN_BUF_R: C611.1, R607.1; also elsewhere on the board
GND: C601.2, C602.2, C606.2, C607.2, C608.2, C609.2, C610.2, C611.2, C612.2, C616.2, C617.2, C618.2, U601.12 (VSS), U601.16 (VSS); also elsewhere on the board
unnamed: C604.1, R602.2, R604.1, U601.3 (INN)
unnamed: C603.1, R601.2, R603.1, U601.2 (INP)
unnamed: C603.2, R605.1, U601.15 (OUTN)
unnamed: C604.2, R606.1, U601.14 (OUTP)
unnamed: C614.1, R608.2, R610.1, U601.7 (INN)
unnamed: C613.1, R607.2, R609.1, U601.6 (INP)
unnamed: C613.2, R611.1, U601.11 (OUTN)
unnamed: C614.2, R612.1, U601.10 (OUTP)
VCOM_A: C602.1, C612.1, R602.1, R608.1; also elsewhere on the board
VCOM_B: C608.1, U601.4 (VOCM), U601.8 (VOCM); also elsewhere on the board

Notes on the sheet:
Single-ended to differential ADC drivers, the Timekeeper's AnalogInputBuffer: THS4522 channel A (left) and B (right), gain 0.59 (620R / 1.05k), 40.2R + 2.7n differential filter, VOCM from VCOM_B. The input reference (INN side) goes to VCOM_A, the DC level of the input buffer output (the Timekeeper 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

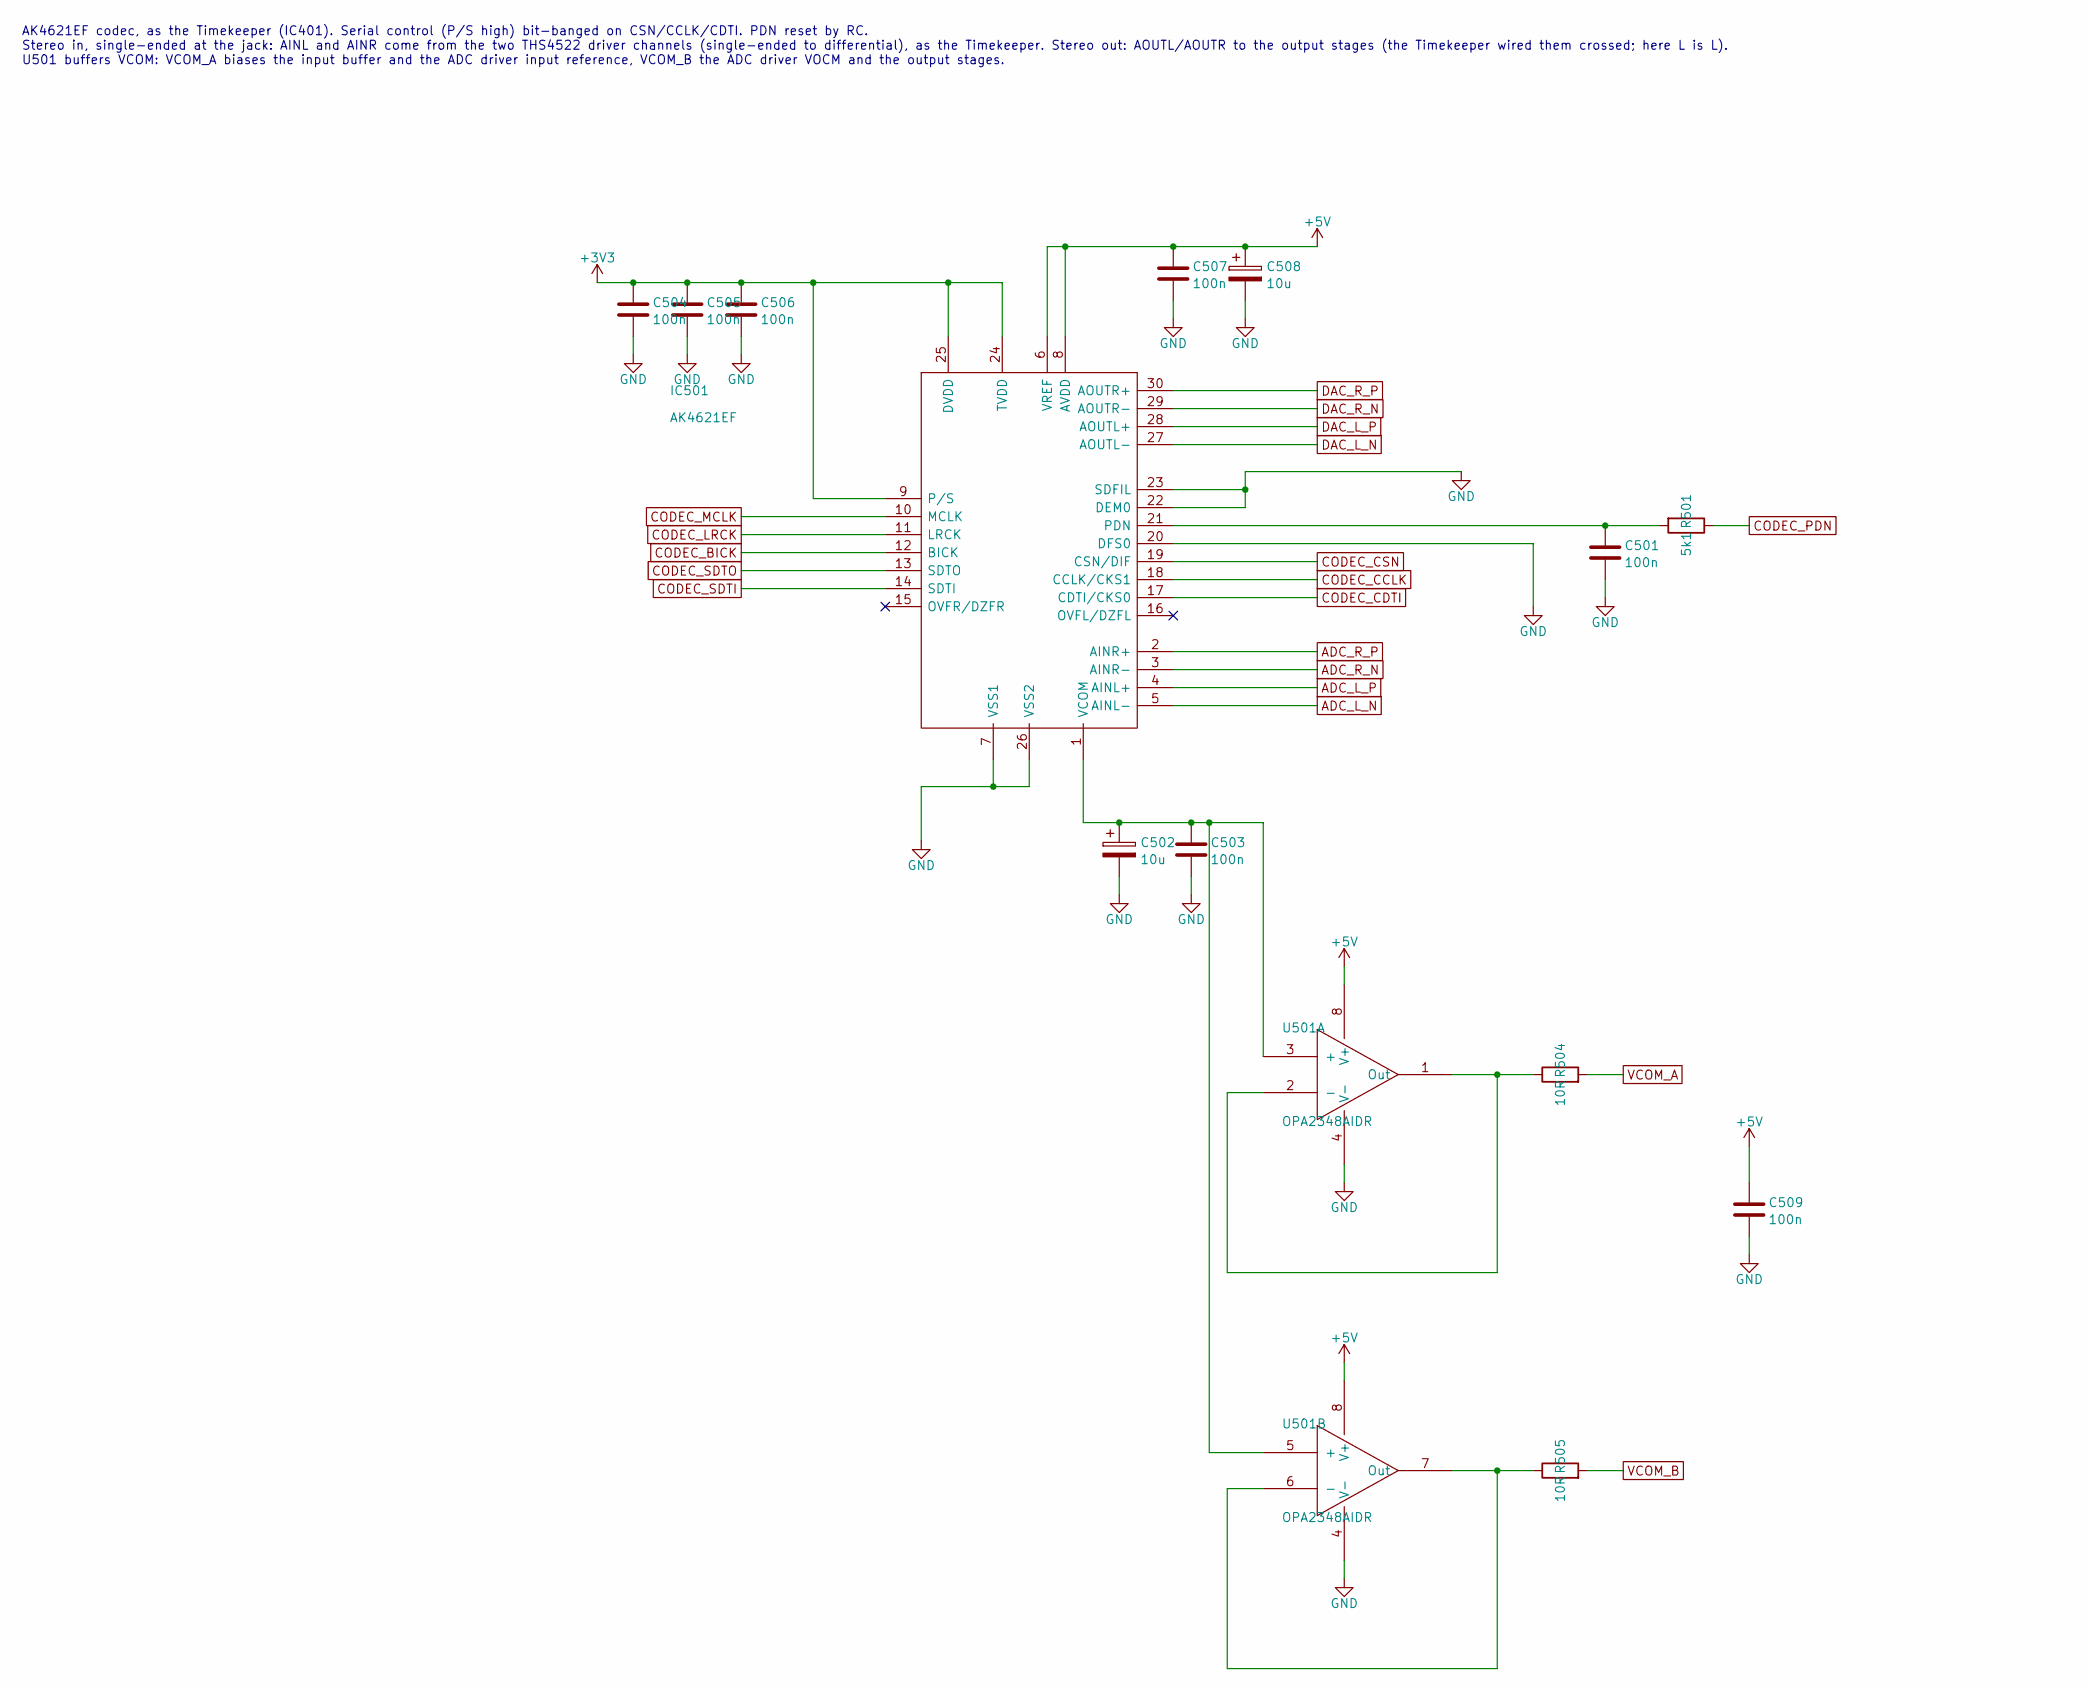
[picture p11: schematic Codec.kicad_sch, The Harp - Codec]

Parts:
C501, C503, C504, C505, C506, C507, C509: 100n; C_0603_1608Metric
C502, C508: 10u; CP_Elec_4x5.8
IC501: AK4621EF; SOP65P760X150-30N; Mfg Part # AK4621EF
R501: 5k1; R_0603_1608Metric
R504, R505: 10R; R_0603_1608Metric
U501: OPA2348AIDR; SOIC-8_3.9x4.9mm_P1.27mm; Mfg Part # OPA2348AIDR

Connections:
+3V3: C504.1, C505.1, C506.1, IC501.9 (P/S), IC501.24 (TVDD), IC501.25 (DVDD); also elsewhere on the board
+5V: C507.1, C508.1, C509.1, IC501.6 (VREF), IC501.8 (AVDD), U501.8 (V+); also elsewhere on the board
ADC_L_N: IC501.5 (AINL-); also elsewhere on the board
ADC_L_P: IC501.4 (AINL+); also elsewhere on the board
ADC_R_N: IC501.3 (AINR-); also elsewhere on the board
ADC_R_P: IC501.2 (AINR+); also elsewhere on the board
CODEC_BICK: IC501.12 (BICK); also elsewhere on the board
CODEC_CCLK: IC501.18 (CCLK/CKS1); also elsewhere on the board
CODEC_CDTI: IC501.17 (CDTI/CKS0); also elsewhere on the board
CODEC_CSN: IC501.19 (CSN/DIF); also elsewhere on the board
CODEC_LRCK: IC501.11 (LRCK); also elsewhere on the board
CODEC_MCLK: IC501.10 (MCLK); also elsewhere on the board
CODEC_PDN: R501.1; also elsewhere on the board
CODEC_SDTI: IC501.14 (SDTI); also elsewhere on the board
CODEC_SDTO: IC501.13 (SDTO); also elsewhere on the board
DAC_L_N: IC501.27 (AOUTL-); also elsewhere on the board
DAC_L_P: IC501.28 (AOUTL+); also elsewhere on the board
DAC_R_N: IC501.29 (AOUTR-); also elsewhere on the board
DAC_R_P: IC501.30 (AOUTR+); also elsewhere on the board
GND: C501.2, C502.2, C503.2, C504.2, C505.2, C506.2, C507.2, C508.2, C509.2, IC501.7 (VSS1), IC501.20 (DFS0), IC501.22 (DEM0), IC501.23 (SDFIL), IC501.26 (VSS2), U501.4 (V-); also elsewhere on the board
unnamed: C501.1, IC501.21 (PDN), R501.2
unnamed: C502.1, C503.1, IC501.1 (VCOM), U501.3 (+), U501.5 (+)
unnamed: R504.1, U501.1 (Out), U501.2 (-)
unnamed: R505.1, U501.6 (-), U501.7 (Out)
VCOM_A: R504.2; also elsewhere on the board
VCOM_B: R505.2; also elsewhere on the board

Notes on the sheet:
AK4621EF codec, as the Timekeeper (IC401). Serial control (P/S high) bit-banged on CSN/CCLK/CDTI. PDN reset by RC. Stereo in, single-ended at the jack: AINL and AINR come from the two THS4522 driver channels (single-ended to differential), as the Timekeeper. Stereo out: AOUTL/AOUTR to the output st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

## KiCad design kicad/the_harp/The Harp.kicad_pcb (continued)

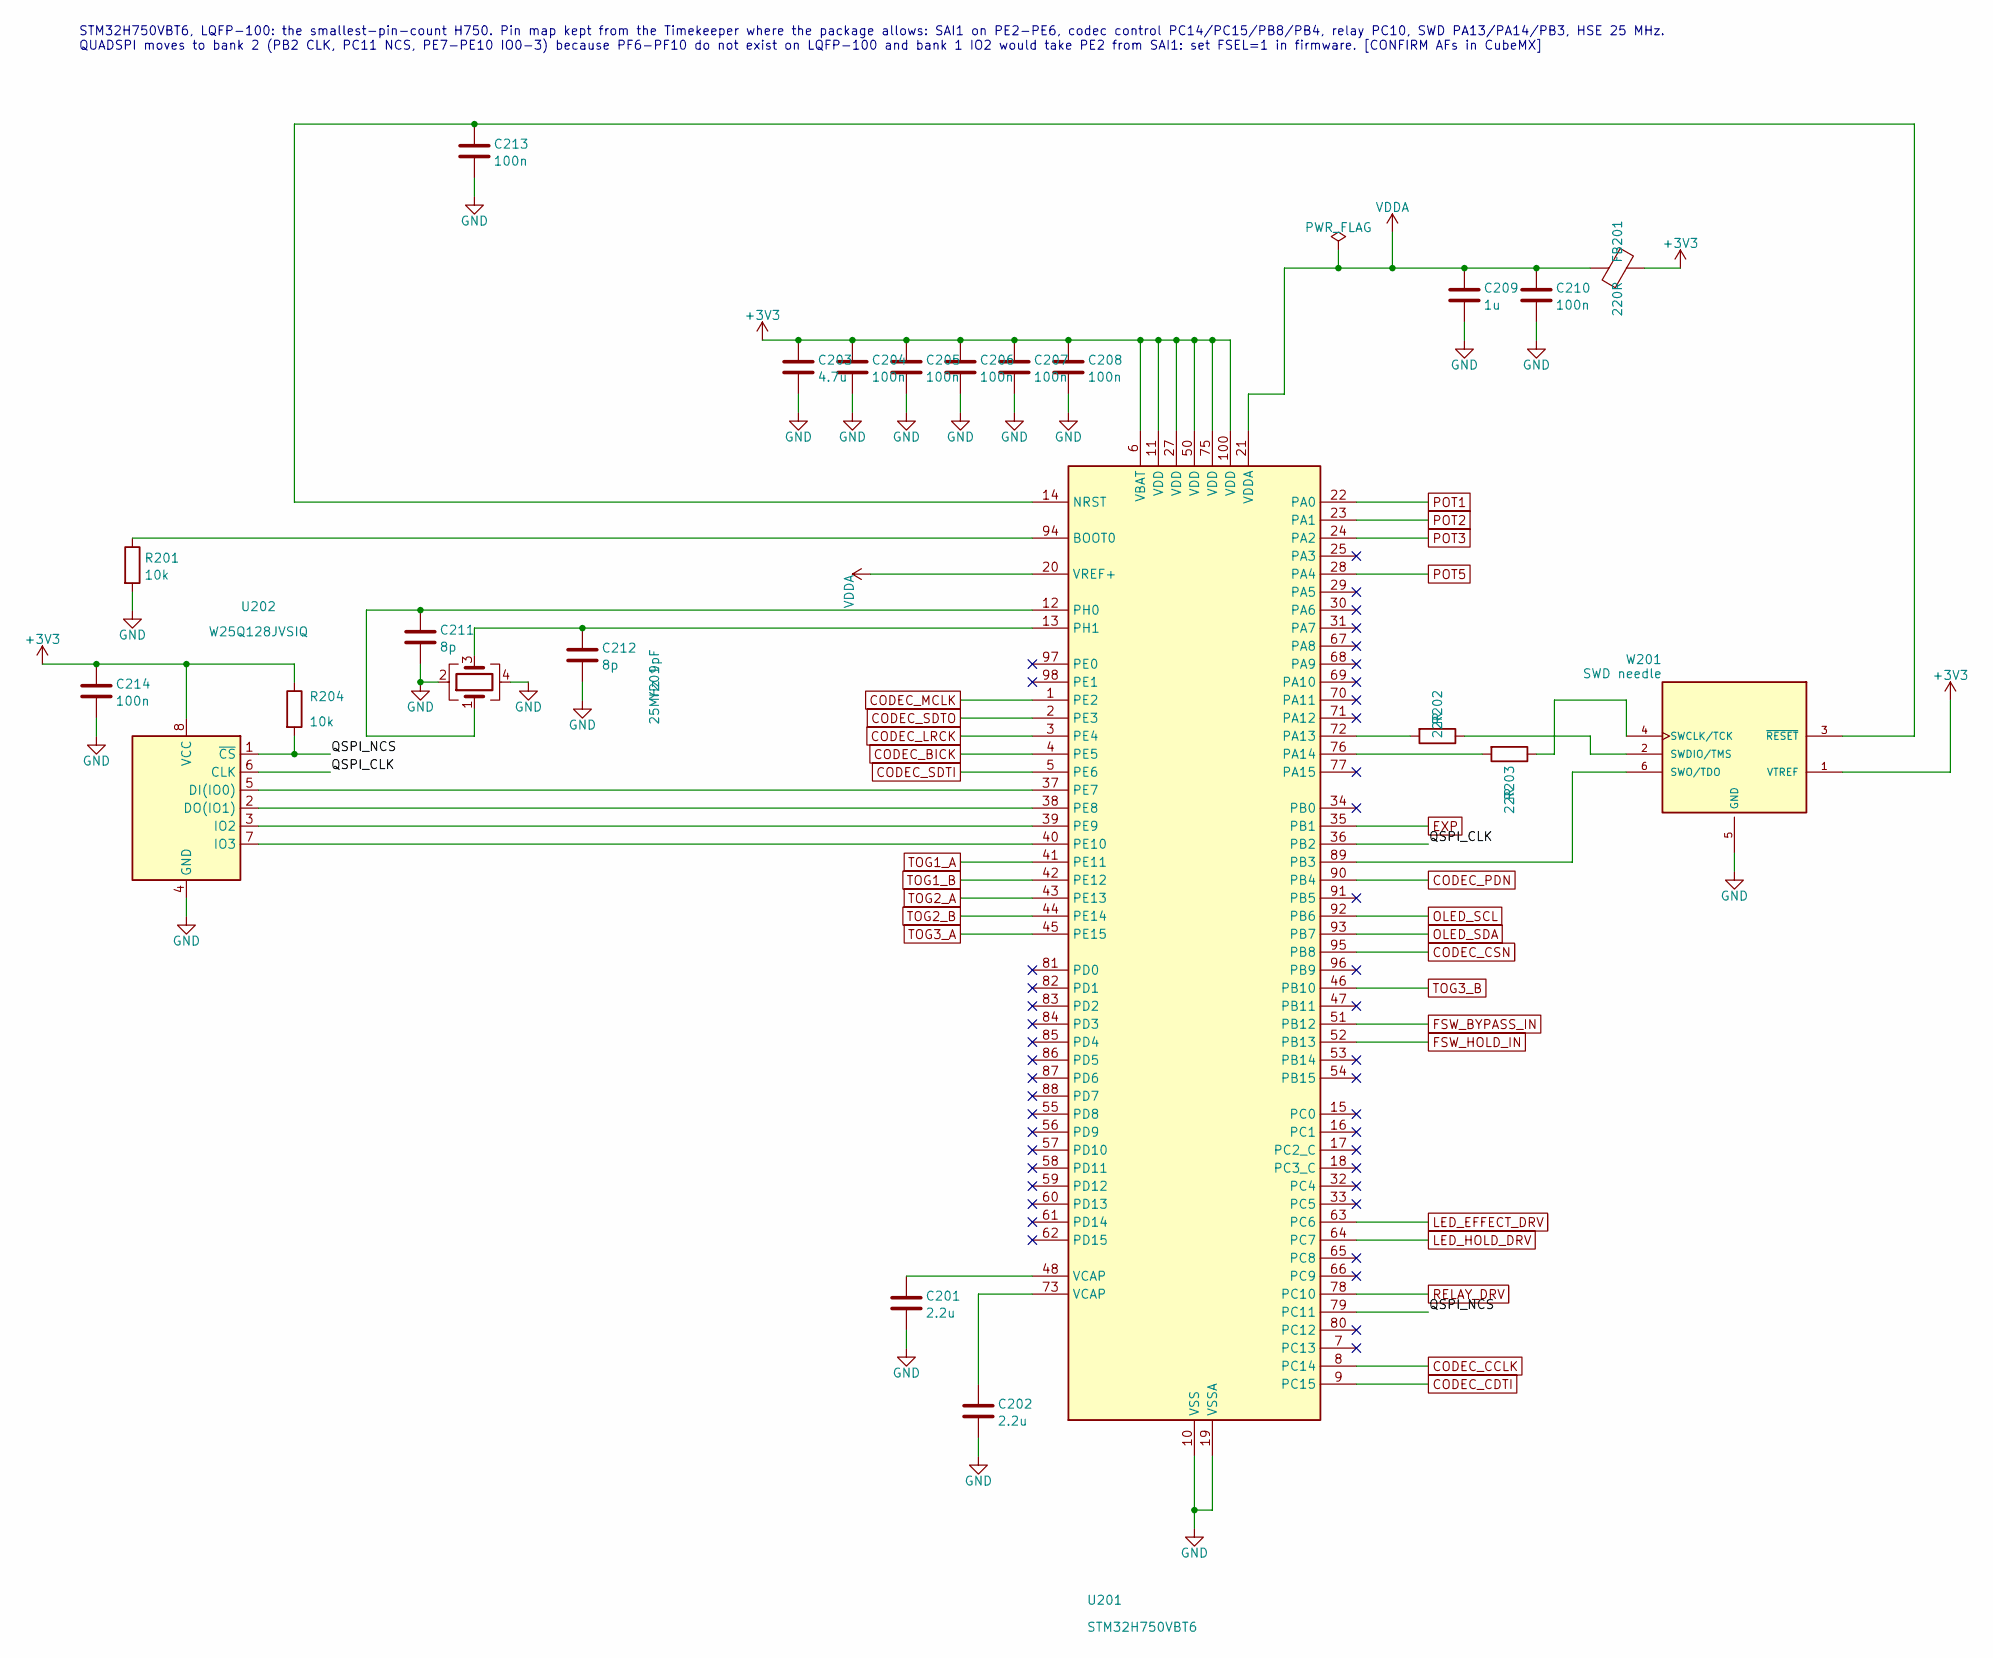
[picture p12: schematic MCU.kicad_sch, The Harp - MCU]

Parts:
C201, C202: 2.2u; C_0603_1608Metric
C203: 4.7u; C_0805_2012Metric
C204, C205, C206, C207, C208, C210, C213, C214: 100n; C_0603_1608Metric
C209: 1u; C_0603_1608Metric
C211, C212: 8p; C_0603_1608Metric
FB201: 220R; L_0603_1608Metric
R201, R204: 10k; R_0603_1608Metric
R202, R203: 22R; R_0603_1608Metric
U201: STM32H750VBT6; LQFP-100_14x14mm_P0.5mm; Mfg Part # STM32H750VBT6
U202: W25Q128JVSIQ; SOIC-8_5.23x5.23mm_P1.27mm; Mfg Part # W25Q128JVSIQ
W201: SWD needle; SEGGER_8.06.05_6-PIN_NEEDLE_ADAPTER
Y201: 25MHz 9pF; Crystal_SMD_2016-4Pin_2.0x1.6mm

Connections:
+3V3: C203.1, C204.1, C205.1, C206.1, C207.1, C208.1, C214.1, FB201.1, R204.1, U201.6 (VBAT), U201.11 (VDD), U201.27 (VDD), U201.50 (VDD), U201.75 (VDD), U201.100 (VDD), U202.8 (VCC), W201.1 (VTREF); also elsewhere on the board
/MCU/QSPI_CLK: U201.36 (PB2), U202.6 (CLK)
/MCU/QSPI_NCS: R204.2, U201.79 (PC11), U202.1 (~CS)
CODEC_BICK: U201.4 (PE5); also elsewhere on the board
CODEC_CCLK: U201.8 (PC14); also elsewhere on the board
CODEC_CDTI: U201.9 (PC15); also elsewhere on the board
CODEC_CSN: U201.95 (PB8); also elsewhere on the board
CODEC_LRCK: U201.3 (PE4); also elsewhere on the board
CODEC_MCLK: U201.1 (PE2); also elsewhere on the board
CODEC_PDN: U201.90 (PB4); also elsewhere on the board
CODEC_SDTI: U201.5 (PE6); also elsewhere on the board
CODEC_SDTO: U201.2 (PE3); also elsewhere on the board
EXP: U201.35 (PB1); also elsewhere on the board
FSW_BYPASS_IN: U201.51 (PB12); also elsewhere on the board
FSW_HOLD_IN: U201.52 (PB13); also elsewhere on the board
GND: C201.2, C202.2, C203.2, C204.2, C205.2, C206.2, C207.2, C208.2, C209.2, C210.2, C211.2, C212.2, C213.2, C214.2, R201.2, U201.10 (VSS), U201.19 (VSSA), U201.26 (VSS), U201.49 (VSS), U201.74 (VSS), U201.99 (VSS), U202.4 (GND), W201.5 (GND), Y201.2, Y201.4; also elsewhere on the board
LED_EFFECT_DRV: U201.63 (PC6); also elsewhere on the board
LED_HOLD_DRV: U201.64 (PC7); also elsewhere on the board
unnamed: C201.1, U201.48 (VCAP)
unnamed: C202.1, U201.73 (VCAP)
unnamed: R201.1, U201.94 (BOOT0)
unnamed: C213.1, U201.14 (NRST), W201.3 (~RESET)
unnamed: R202.2, U201.72 (PA13)
unnamed: R203.2, U201.76 (PA14)
unnamed: U201.89 (PB3), W201.6 (SWO/TDO)
unnamed: U201.37 (PE7), U202.5 (DI(IO0))
unnamed: U201.38 (PE8), U202.2 (DO(IO1))
unnamed: U201.39 (PE9), U202.3 (IO2)
unnamed: U201.40 (PE10), U202.7 (IO3)
unnamed: C211.1, U201.12 (PH0), Y201.1
unnamed: C212.1, U201.13 (PH1), Y201.3
unnamed: R203.1, W201.4 (SWCLK/TCK)
unnamed: R202.1, W201.2 (SWDIO/TMS)
OLED_SCL: U201.92 (PB6); also elsewhere on the board
OLED_SDA: U201.93 (PB7); also elsewhere on the board
POT1: U201.22 (PA0); also elsewhere on the board
POT2: U201.23 (PA1); also elsewhere on the board
POT3: U201.24 (PA2); also elsewhere on the board
POT5: U201.28 (PA4); also elsewhere on the board
RELAY_DRV: U201.78 (PC10); also elsewhere on the board
TOG1_A: U201.41 (PE11); also elsewhere on the board
TOG1_B: U201.42 (PE12); also elsewhere on the board
TOG2_A: U201.43 (PE13); also elsewhere on the board
TOG2_B: U201.44 (PE14); also elsewhere on the board
TOG3_A: U201.45 (PE15); also elsewhere on the board
TOG3_B: U201.46 (PB10); also elsewhere on the board
VDDA: C209.1, C210.1, FB201.2, U201.20 (VREF+), U201.21 (VDDA)

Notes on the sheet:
STM32H750VBT6, LQFP-100: the smallest-pin-count H750. Pin map kept from the Timekeeper where the package allows: SAI1 on PE2-PE6, codec control PC14/PC15/PB8/PB4, relay PC10, SWD PA13/PA14/PB3, HSE 25 MHz. QUADSPI moves to bank 2 (PB2 CLK, PC11 NCS, PE7-PE10 IO0-3) because PF6-PF10 do not exist on 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

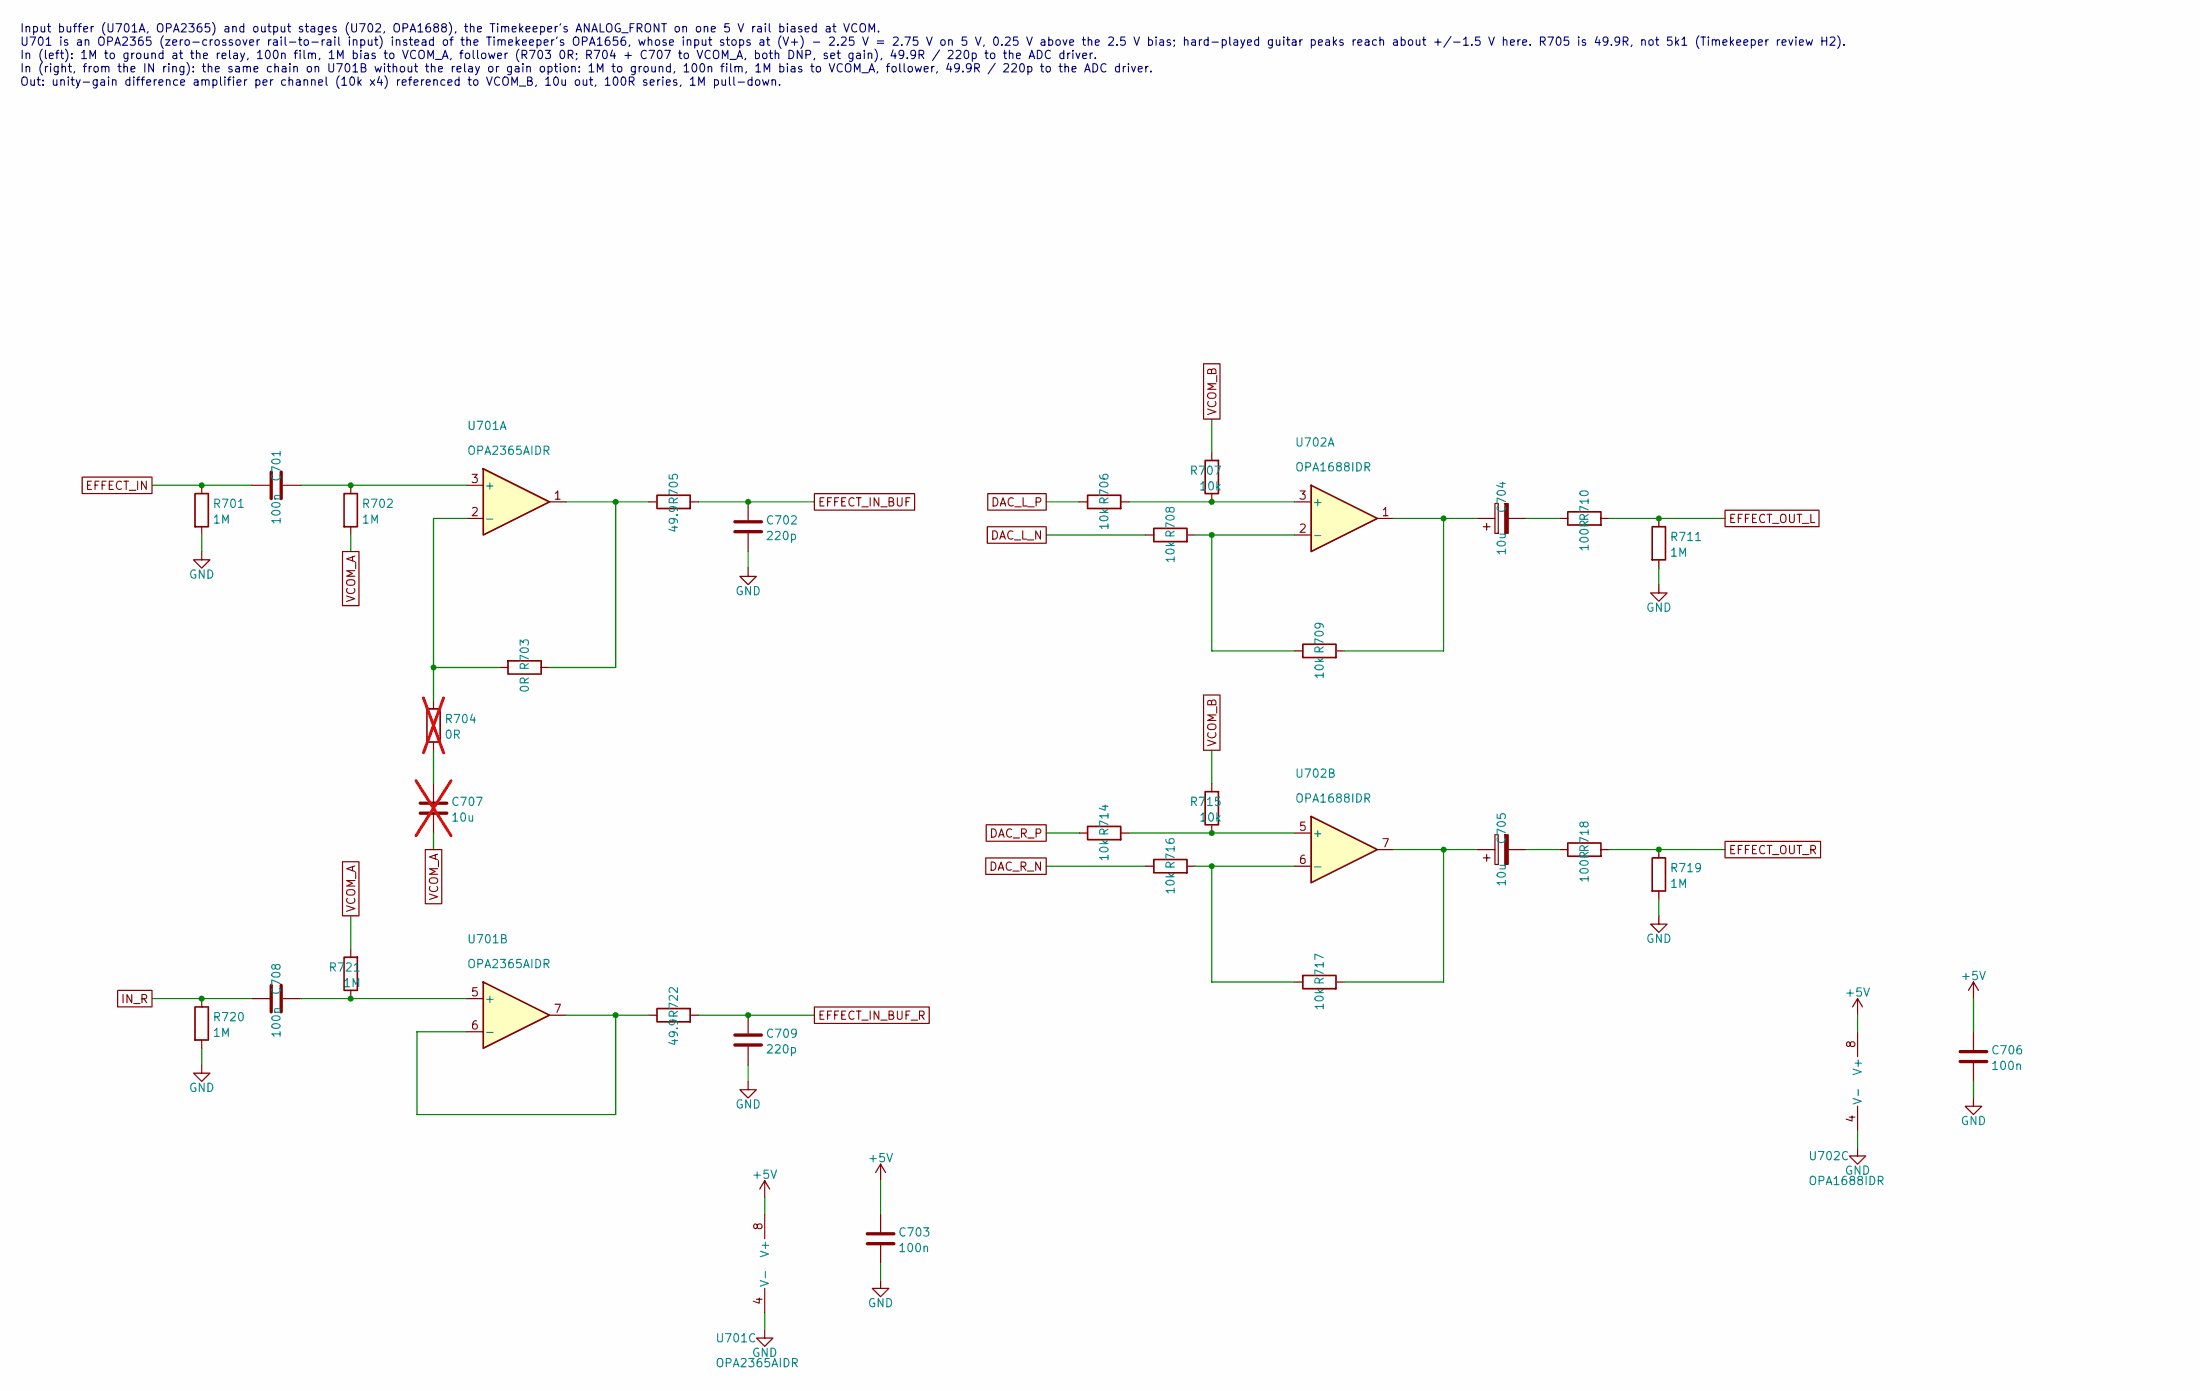
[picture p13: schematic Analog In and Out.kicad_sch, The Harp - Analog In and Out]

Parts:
C701, C708: 100n; C_1206_3216Metric
C702, C709: 220p; C_0603_1608Metric
C703, C706: 100n; C_0603_1608Metric
C704, C705: 10u; CP_EIA-3216-12_Kemet-S
C707: 10u; C_0805_2012Metric; not fitted
R701, R702, R711, R719, R720, R721: 1M; R_0603_1608Metric
R703: 0R; R_0603_1608Metric
R704: 0R; R_0603_1608Metric; not fitted
R705, R722: 49.9; R_0603_1608Metric
R706, R707, R708, R709, R714, R715, R716, R717: 10k; R_0603_1608Metric
R710, R718: 100R; R_0603_1608Metric
U701: OPA2365AIDR; SOIC-8_3.9x4.9mm_P1.27mm; Mfg Part # OPA2365AIDR
U702: OPA1688IDR; SOIC-8_3.9x4.9mm_P1.27mm; Mfg Part # OPA1688IDR

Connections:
+5V: C703.1, C706.1, U701.8 (V+), U702.8 (V+); also elsewhere on the board
DAC_L_N: R708.1; also elsewhere on the board
DAC_L_P: R706.1; also elsewhere on the board
DAC_R_N: R716.1; also elsewhere on the board
DAC_R_P: R714.1; also elsewhere on the board
EFFECT_IN: C701.1, R701.1; also elsewhere on the board
EFFECT_IN_BUF: C702.1, R705.2; also elsewhere on the board
EFFECT_IN_BUF_R: C709.1, R722.2; also elsewhere on the board
EFFECT_OUT_L: R710.2, R711.1; also elsewhere on the board
EFFECT_OUT_R: R718.2, R719.1; also elsewhere on the board
GND: C702.2, C703.2, C706.2, C709.2, R701.2, R711.2, R719.2, R720.2, U701.4 (V-), U702.4 (V-); also elsewhere on the board
IN_R: C708.1, R720.1; also elsewhere on the board
unnamed: C704.1, R709.2, U702.1
unnamed: C704.2, R710.1
unnamed: C705.1, R717.2, U702.7
unnamed: C705.2, R718.1
unnamed: C707.1, R704.2
unnamed: R703.1, R705.1, U701.1
unnamed: C701.2, R702.1, U701.3 (+)
unnamed: R703.2, R704.1, U701.2 (-)
unnamed: C708.2, R721.1, U701.5 (+)
unnamed: R722.1, U701.6 (-), U701.7
unnamed: R706.2, R707.1, U702.3 (+)
unnamed: R708.2, R709.1, U702.2 (-)
unnamed: R714.2, R715.1, U702.5 (+)
unnamed: R716.2, R717.1, U702.6 (-)
VCOM_A: C707.2, R702.2, R721.2; also elsewhere on the board
VCOM_B: R707.2, R715.2; also elsewhere on the board

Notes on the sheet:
Input buffer (U701A, OPA2365) and output stages (U702, OPA1688), the Timekeeper's ANALOG_FRONT on one 5 V rail biased at VCOM. U701 is an OPA2365 (zero-crossover rail-to-rail input) instead of the Timekeeper's OPA1656, whose input stops at (V+) - 2.25 V = 2.75 V on 5 V, 0.25 V above the 2.5 V bias;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

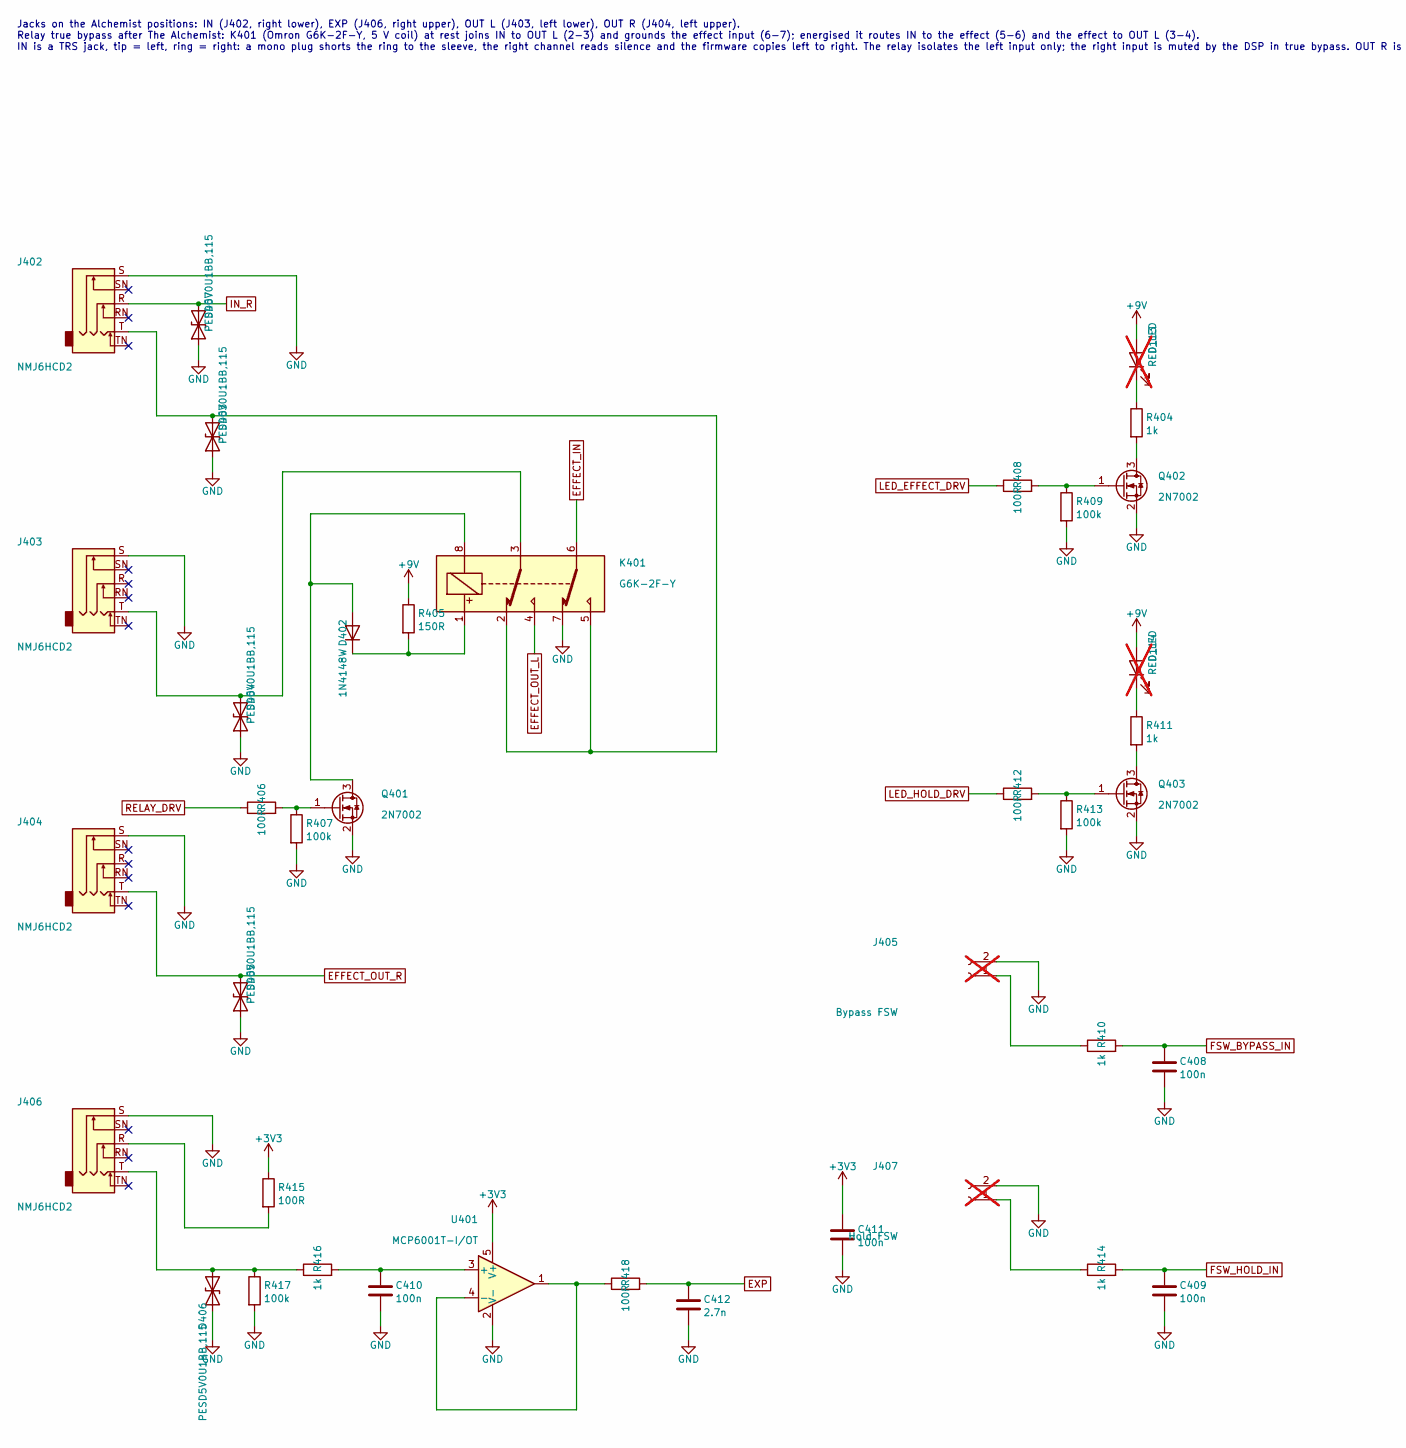
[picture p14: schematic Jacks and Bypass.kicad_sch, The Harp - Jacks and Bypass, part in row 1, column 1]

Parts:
C408, C409: 100n; C_0603_1608Metric; Mfg Part # CC0603KRX7R9BB104; LCSC C14663
C410, C411: 100n; C_0603_1608Metric
C412: 2.7n; C_0603_1608Metric
D113, D114: RED_LED; LED_D3.0mm; Mfg Part # WP710A10ID; not fitted
D402: 1N4148W; D_SOD-123; Mfg Part # 1N4148W-7-F; LCSC C7420318
D403, D404, D405, D406, D407: PESD5V0U1BB,115; D_SOD-523; Mfg Part # PESD5V0U1BB,115
J402, J403, J404, J406: NMJ6HCD2; Jack_6.35mm_Neutrik_NMJ6HCD2_Horizontal; Mfg Part # NMJ6HCD2; LCSC C309277
J405: Bypass FSW; R_2816_7142Metric_Pad3.20x4.45mm_HandSolder; not fitted
J407: Hold FSW; R_2816_7142Metric_Pad3.20x4.45mm_HandSolder; not fitted
K401: G6K-2F-Y; Relay_DPDT_Omron_G6K-2F-Y; Mfg Part # G6K-2F-Y DC5; LCSC C2982926
Q401, Q402, Q403: 2N7002; SOT-23; Mfg Part # 2N7002LT1G; LCSC C7420321
R404, R410, R411, R414: 1k; R_0805_2012Metric; Mfg Part # AC0805FR-071KL; LCSC C17513
R405: 150R; R_1206_3216Metric; Mfg Part # RC1206FR-07150RL; LCSC C17917
R406, R408, R412: 100R; R_0805_2012Metric; Mfg Part # AC0805FR-07100RL; LCSC C7468571
R407, R409, R413: 100k; R_0805_2012Metric; Mfg Part # AC0805FR-07100KL; LCSC C149504
R415, R418: 100R; R_0603_1608Metric
R416: 1k; R_0603_1608Metric
R417: 100k; R_0603_1608Metric
U401: MCP6001T-I/OT; SOT-23-5; Mfg Part # MCP6001T-I/OT

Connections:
+3V3: C411.1, R415.1, U401.5 (V+); also elsewhere on the board
+9V: D113.2 (A), D114.2 (A), R405.1; also elsewhere on the board
EFFECT_IN: K401.6; also elsewhere on the board
EFFECT_OUT_L: K401.4; also elsewhere on the board
EFFECT_OUT_R: D405.2 (A2), J404.T; also elsewhere on the board
EXP: C412.1, R418.2; also elsewhere on the board
FSW_BYPASS_IN: C408.1, R410.2; also elsewhere on the board
FSW_HOLD_IN: C409.1, R414.2; also elsewhere on the board
GND: C408.2, C409.2, C410.2, C411.2, C412.2, D403.1 (A1), D404.1 (A1), D405.1 (A1), D406.1 (A1), D407.1 (A1), J402.S, J403.S, J404.S, J405.2, J406.S, J407.2, K401.7, Q401.2 (S), Q402.2 (S), Q403.2 (S), R407.2, R409.2, R413.2, R417.2, U401.2 (V-); also elsewhere on the board
IN_R: D407.2 (A2), J402.R; also elsewhere on the board
LED_EFFECT_DRV: R408.1; also elsewhere on the board
LED_HOLD_DRV: R412.1; also elsewhere on the board
unnamed: D113.1 (K), R404.1
unnamed: D114.1 (K), R411.1
unnamed: D402.2 (A), K401.8, Q401.3 (D)
unnamed: D402.1 (K), K401.1, R405.2
unnamed: D403.2 (A2), J402.T, K401.2, K401.5
unnamed: D404.2 (A2), J403.T, K401.3
unnamed: D406.2 (A2), J406.T, R416.1, R417.1
unnamed: J405.1, R410.1
unnamed: J406.R, R415.2
unnamed: J407.1, R414.1
unnamed: Q401.1 (G), R406.2, R407.1
unnamed: Q402.3 (D), R404.2
unnamed: Q402.1 (G), R408.2, R409.1
unnamed: Q403.3 (D), R411.2
unnamed: Q403.1 (G), R412.2, R413.1
unnamed: C410.1, R416.2, U401.3 (+)
unnamed: R418.1, U401.1, U401.4 (-)
RELAY_DRV: R406.1; also elsewhere on the board

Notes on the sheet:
Jacks on the Alchemist positions: IN (J402, right lower), EXP (J406, right upper), OUT L (J403, left lower), OUT R (J404, left upper). Relay true bypass after The Alchemist: K401 (Omron G6K-2F-Y, 5 V coil) at rest joins IN to OUT L (2-3) and grounds the effect input (6-7); energised it routes IN to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

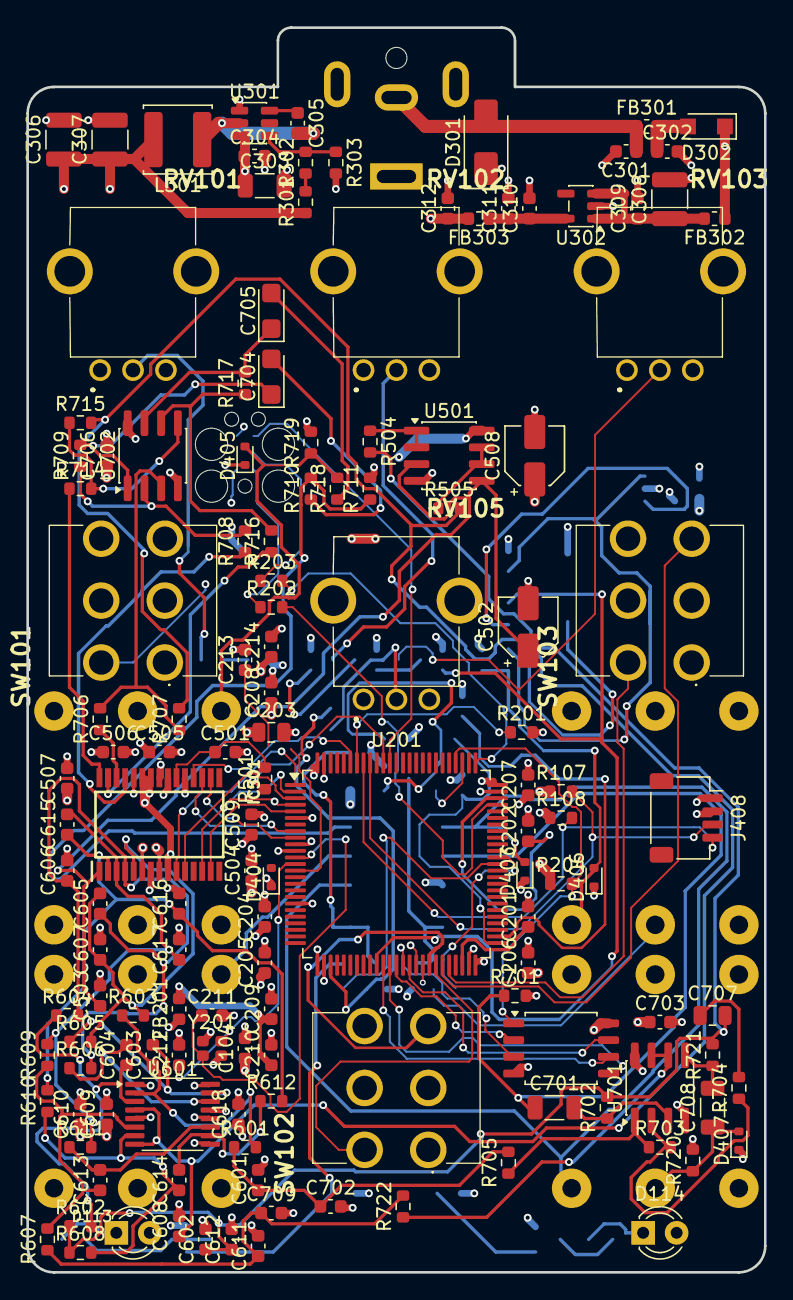
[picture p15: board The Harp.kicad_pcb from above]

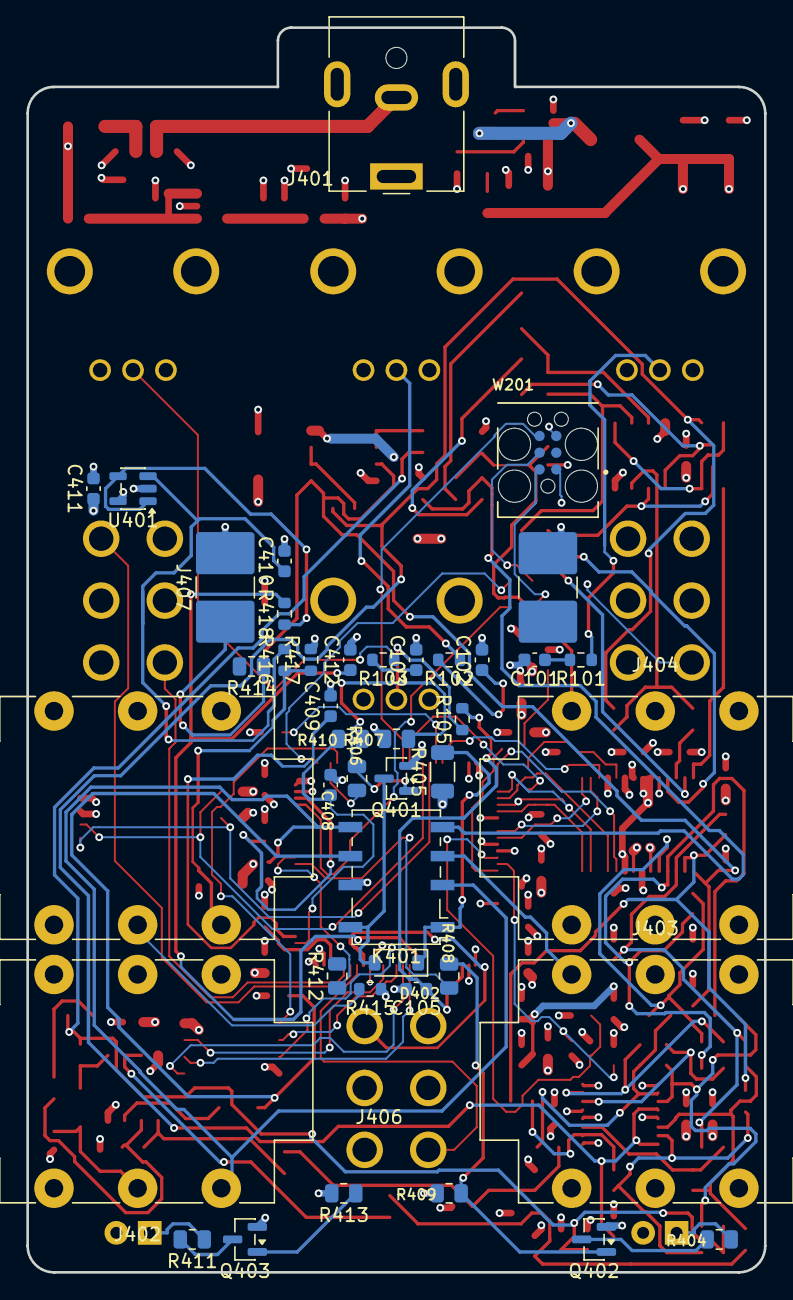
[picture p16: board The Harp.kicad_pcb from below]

Board: 4 copper layers, 56.0 x 94.5 mm, 181 parts (42 on the bottom side), 120 nets.

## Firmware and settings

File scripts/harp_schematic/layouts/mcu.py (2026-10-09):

"""MCU: STM32H750VBT6 with its supplies, HSE crystal, reset and boot, SWD needle pads and the W25Q128 QSPI flash.

Two nets get local labels: QSPI_CLK (PB2, right side) and QSPI_NCS (PC11, right side) go to the flash on the
left; the flash sits on the left so its four IO lines run straight into PE7-PE10."""
from layouts.common import u, U, shunt, series

NOTES = ['C', 'Cs', 'D', 'Ds', 'E', 'F', 'Fs', 'G', 'Gs', 'A', 'As', 'B']
LEFT = {'PE2': 'CODEC_MCLK', 'PE3': 'CODEC_SDTO', 'PE4': 'CODEC_LRCK', 'PE5': 'CODEC_BICK', 'PE6': 'CODEC_SDTI',
        'PE7': None, 'PE8': None, 'PE9': None, 'PE10': None,
        'PE11': 'TOG1_A', 'PE12': 'TOG1_B', 'PE13': 'TOG2_A', 'PE14': 'TOG2_B', 'PE15': 'TOG3_A'}
RIGHT = {'PA0': 'POT1', 'PA1': 'POT2', 'PA2': 'POT3', 'PA4': 'POT5', 'PB1': 'EXP', 'PB4': 'CODEC_PDN', 'PB8': 'CODEC_CSN',
         'PB10': 'TOG3_B', 'PB6': 'OLED_SCL', 'PB7': 'OLED_SDA', 'PB12': 'FSW_BYPASS_IN', 'PB13': 'FSW_HOLD_IN', 'PC6': 'LED_EFFECT_DRV', 'PC7': 'LED_HOLD_DRV',
         'PC10': 'RELAY_DRV', 'PC14': 'CODEC_CCLK', 'PC15': 'CODEC_CDTI'}


def layout(L):
    L.allow_local = {'QSPI_CLK', 'QSPI_NCS'}
    L.text(L.sheet.notes[0], u(8), u(6))
    X, Y = u(70), u(56)
    P = L.at('U201', X, Y, ref_pos=(u(64), u(92), 'left'), val_pos=(u(64), u(93.5), 'left'))
    byname = {}
    from kisch import lib_pins
    for nb, nm, *_ in lib_pins(P.lib, P.part.unit):
        byname.setdefault(nm, []).append(nb)
    pinno = {nm: nbs[0] for nm, nbs in byname.items()}
    # ---- port pins to other sheets
    for nm, net in LEFT.items():
        if net:
            L.gl(net, ('U201', pinno[nm]), 'left', length=4 * U)
    for nm, net in RIGHT.items():
        L.gl(net, ('U201', pinno[nm]), 'right', length=4 * U)
    L.local('QSPI_CLK', ('U201', pinno['PB2']), 'right', length=4 * U)
    L.local('QSPI_NCS', ('U201', pinno['PC11']), 'right', length=4 * U)
    for nm in ['PD%d' % i for i in range(12)] + ['PE0', 'PE1', 'PD12', 'PD13', 'PD14', 'PD15', 'PA3', 'PA5', 'PA6', 'PA7', 'PA8', 'PA9', 'PA10', 'PA11', 'PA12',
               'PA15', 'PB0', 'PB5', 'PB9', 'PB11', 'PB14', 'PB15', 'PC0', 'PC1', 'PC2_C', 'PC3_C', 'PC4', 'PC5',
               'PC8', 'PC9', 'PC12', 'PC13']:
        L.nc('U201', pinno[nm])
    # ---- supplies: VDD x5 + VBAT on a +3V3 rail with six decoupling caps; VDDA through FB201 with 1u + 100n
    top = u(22)
    for nb in byname['VDD'] + byname['VBAT']:
        x, y = L.pin('U201', nb)
        L.w((x, y), (x, top))
    L.w((u(46), top), (u(72), top))
    L.pwr('+3V3', (u(46), top), 'up')
    for i, ref in enumerate(('C203', 'C204', 'C205', 'C206', 'C207', 'C208')):
        shunt(L, ref, u(48 + 3 * i), top)
    xa, ya = L.pin('U201', pinno['VDDA'])
    L.w((xa, ya), (xa, u(25)), (u(75), u(25)), (u(75), u(18)), (u(92), u(18)))          # VDDA
    L.flag((u(78), u(18)))
    L.w((u(81), u(18)), (u(81), u(16)))
    L.pwr('VDDA', (u(81), u(16)), 'up')
    shunt(L, 'C209', u(85), u(18))
    shunt(L, 'C210', u(89), u(18))
    series(L, 'FB201', u(93.5), u(18), flip=True)
    L.w(('FB201', '1'), (u(97), u(18)))
    L.pwr('+3V3', (u(97), u(18)), 'up')
    # VSS x5 (stacked) and VSSA
    xs, ys = L.pin('U201', byname['VSS'][0])
    L.w((xs, ys), (xs, u(88)))
    L.gnd((xs, u(88)))
    xsa, ysa = L.pin('U201', pinno['VSSA'])
    L.w((xsa, ysa), (xsa, u(87)), (xs, u(87)))
    # VCAP
    L.w(('U201', byname['VCAP'][0]), (u(54), u(74)))
    shunt(L, 'C201', u(54), u(74))
    L.w(('U201', byname['VCAP'][1]), (u(58), u(75)), (u(58), u(80)))
    L.at('C202', u(58), u(81.5))
    L.gnd(('C202', '2'), length=U)
    # ---- reset, boot, VREF+
    L.w(('U201', pinno['NRST']), (u(20), u(31)), (u(20), u(10)), (u(110), u(10)), (u(110), u(44)), (u(106), u(44)))
    shunt(L, 'C213', u(30), u(10))
    L.w(('U201', pinno['BOOT0']), (u(11), u(33)))
    shunt(L, 'R201', u(11), u(33))
    L.w(('U201', pinno['VREF+']), (u(52), u(35)))
    L.pwr('VDDA', (u(52), u(35)), 'left')
    # ---- HSE crystal: pin 1 (HSE_IN) below, pin 3 (HSE_OUT) above, GND pins left and right
    L.at('Y201', u(30), u(41), ang=90, ref_pos=(u(40), u(42), 'left'), val_pos=(u(40), u(43.4), 'left'))
    L.w(('U201', pinno['PH1']), (u(30), u(38)), ('Y201', '3'))                                   # HSE_OUT
    L.w(('U201', pinno['PH0']), (u(24), u(37)), (u(24), u(44)), (u(30), u(44)), ('Y201', '1'))   # HSE_IN
    shunt(L, 'C211', u(27), u(37))
    L.w(('Y201', '2'), (u(27), u(41)))
    L.w(('Y201', '4'), (u(33), u(41)))
    L.gnd((u(33), u(41)))
    shunt(L, 'C212', u(36), u(38))
    # ---- QSPI flash on the left: IO0-IO3 straight into PE7-PE10, CS and CLK by local label, 10k pull-up on CS
    L.at('U202', u(14), u(48), mirror='y', ref_pos=(u(18), u(36.8), 'center'), val_pos=(u(18), u(38.2), 'center'))
    for nm, nb in (('PE7', '5'), ('PE8', '2'), ('PE9', '3'), ('PE10', '7')):
        L.w(('U201', pinno[nm]), ('U202', nb))
    L.w(('U202', '1'), (u(22), u(45)))
    L.local('QSPI_NCS', (u(22), u(45)), 'right')
    L.w(('U202', '6'), (u(22), u(46)))
    L.local('QSPI_CLK', (u(22), u(46)), 'right')
    L.w((u(20), u(45)), (u(20), u(44)))
    L.at('R204', u(20), u(42.5), ref_pos=(u(20.8), u(41.8), 'left'), val_pos=(u(20.8), u(43.2), 'left'))
    L.w(('R204', '1'), (u(20), u(40)), (u(6), u(40)))
    L.w(('U202', '8'), (u(14), u(40)))
    L.pwr('+3V3', (u(6), u(40)), 'up')
    shunt(L, 'C214', u(9), u(40))
    L.gnd(('U202', '4'), length=U)
    # ---- SWD needle pads on the right: SWDIO / SWCLK through 22R, SWO, NRST, +3V3, GND
    L.at('W201', u(100), u(46), mirror='y')
    L.w(('U201', pinno['PA13']), (u(82), u(44)))
    series(L, 'R202', u(83.5), u(44), flip=True, ref_pos=(u(83.5), u(42.4), 'center'), val_pos=(u(83.5), u(43.4), 'center'))
    L.w(('R202', '1'), (u(92), u(44)), (u(92), u(45)), ('W201', '2'))
    L.w(('U201', pinno['PA14']), (u(86), u(45)))
    series(L, 'R203', u(87.5), u(45), flip=True, ref_pos=(u(87.5), u(46.6), 'center'), val_pos=(u(87.5), u(47.6), 'center'))
    L.w(('R203', '1'), (u(90), u(45)), (u(90), u(42)), (u(94), u(42)), ('W201', '4'))
    L.w(('U201', pinno['PB3']), (u(91), u(51)), (u(91), u(46)), ('W201', '6'))
    L.w(('W201', '1'), (u(112), u(46)), (u(112), u(42)))
    L.pwr('+3V3', (u(112), u(42)), 'up')
    L.gnd(('W201', '5'), length=U)

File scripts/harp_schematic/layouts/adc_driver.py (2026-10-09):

"""ADC Driver: THS4522 channel A (left) and B (right) as single-ended to differential drivers into the AK4621 inputs."""
from layouts.common import u, U, shunt, series

# ref and pin names per channel (the two units of U601 have identical pin positions)
CH = {
    'A': dict(unit=1, in_net='EFFECT_IN_BUF', out='ADC_L', dy=0, pin={'PD': '1', 'INP': '2', 'INN': '3', 'VOCM': '4', 'VCC': '13', 'OUTP': '14', 'OUTN': '15', 'VSS': '16'},
              ref=dict(C601='C601', C602='C602', R601='R601', R602='R602', R603='R603', R604='R604', R605='R605', R606='R606',
                       C603='C603', C604='C604', C605='C605', C606='C606', C607='C607', C608='C608')),
    'B': dict(unit=2, in_net='EFFECT_IN_BUF_R', out='ADC_R', dy=48, pin={'PD': '5', 'INP': '6', 'INN': '7', 'VOCM': '8', 'VCC': '9', 'OUTP': '10', 'OUTN': '11', 'VSS': '12'},
              ref=dict(C601='C611', C602='C612', R601='R607', R602='R608', R603='R609', R604='R610', R605='R611', R606='R612',
                       C603='C613', C604='C614', C605='C615', C606='C616', C607='C617', C608=None)),
}


def channel(L, ch):
    c = CH[ch]
    un, dy, P, R = c['unit'], c['dy'], c['pin'], c['ref']
    Y = lambda n: u(n + dy)
    pn = lambda k: ('U601', P[k], un)
    X = u(60)
    L.at('U601', X, Y(40), unit=un, ref_pos=(u(50), Y(46.5), 'left'), val_pos=(u(50), Y(48), 'left'))
    # ---- inputs: input buffer (top) and VCOM_A reference (bottom)
    for y, net, cap, res, pin in ((34, c['in_net'], R['C601'], R['R601'], 'INP'), (46, 'VCOM_A', R['C602'], R['R602'], 'INN')):
        L.gl(net, (u(26), Y(y)), 'left')
        L.w((u(26), Y(y)), (u(34), Y(y)))
        shunt(L, cap, u(30), Y(y))
        series(L, res, u(35.5), Y(y))
        L.w((res, '2'), (u(50), Y(y)), 'V', pn(pin))
    # ---- outputs through 40.2R to ADC_x_N (top) / ADC_x_P (bottom)
    L.w(pn('OUTN'), (u(71), Y(38)))
    series(L, R['R605'], u(72.5), Y(38))
    L.w((R['R605'], '2'), (u(90), Y(38)))
    L.w(pn('OUTP'), (u(71), Y(42)))
    series(L, R['R606'], u(72.5), Y(42))
    L.w((R['R606'], '2'), (u(86), Y(42)))
    L.at(R['C605'], u(80), Y(40), ang=180)                          # across ADC_P (pin 1, below) / ADC_N
    L.w((u(80), Y(38)), (R['C605'], '2'))
    L.w((R['C605'], '1'), (u(80), Y(42)))
    shunt(L, R['C606'], u(83), Y(42))
    L.gl(c['out'] + '_P', (u(86), Y(42)), 'right')
    shunt(L, R['C607'], u(92), Y(38))
    L.w((u(90), Y(38)), (u(96), Y(38)))
    L.gl(c['out'] + '_N', (u(96), Y(38)), 'right')
    # ---- feedback: C603 / C604 to the outputs, R603 / R604 to the filtered outputs
    L.w((u(44), Y(34)), (u(44), Y(23)), (u(53), Y(23)))
    series(L, R['C603'], u(54.5), Y(23))
    L.w((R['C603'], '2'), (u(69), Y(23)), (u(69), Y(38)))
    L.w((u(40), Y(34)), (u(40), Y(19)), (u(60), Y(19)))
    series(L, R['R603'], u(61.5), Y(19))
    L.w((R['R603'], '2'), (u(78), Y(19)), (u(78), Y(38)))
    L.w((u(44), Y(46)), (u(44), Y(59)), (u(53), Y(59)))
    series(L, R['C604'], u(54.5), Y(59))
    L.w((R['C604'], '2'), (u(69), Y(59)), (u(69), Y(42)))
    L.w((u(40), Y(46)), (u(40), Y(63)), (u(60), Y(63)))
    series(L, R['R604'], u(61.5), Y(63))
    L.w((R['R604'], '2'), (u(78), Y(63)), (u(78), Y(42)))
    # ---- supply and VOCM
    L.w(pn('VCC'), (u(58.5), Y(29)))
    L.pwr('+5V', (u(58.5), Y(29)), 'up')
    L.w(pn('PD'), (u(60), Y(31)), (u(58.5), Y(31)))
    L.gnd(pn('VSS'), length=U)
    L.w(pn('VOCM'), (u(60), Y(51)), (u(53), Y(51)))
    if R['C608']:
        shunt(L, R['C608'], u(57), Y(51))
    L.gl('VCOM_B', (u(53), Y(51)), 'left')


def layout(L):
    L.text(L.sheet.notes[0], u(8), u(6))
    channel(L, 'A')
    channel(L, 'B')
    # ---- supply decoupling
    L.pwr('+5V', (u(90), u(22)), 'up')
    L.w((u(90), u(22)), (u(90), u(24)), (u(96), u(24)))
    shunt(L, 'C609', u(92), u(24))
    shunt(L, 'C610', u(96), u(24))
    L.pwr('+5V', (u(90), u(70)), 'up')
    L.w((u(90), u(70)), (u(90), u(72)), (u(92), u(72)))
    shunt(L, 'C618', u(92), u(72))

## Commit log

2026-10-04 Seed KiCad project from The Relic
    Board outline, stackup, 125B face guides, Power and IO sheet (relay bypass,
    jacks, DC) and the face parts, renumbered to the Harp plan; adds OUT R and EXP
    jack footprints at the Alchemist's upper positions. PT2399 sheets, tracks and
    vias dropped.
    Claude-Session: https://claude.ai/code/session_01ToUUHuo6mg178NkLtQkDLg
    [Power and IO.kicad_sch, The Harp.kicad_pcb, The Harp.kicad_sch]
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2026-10-04 Draw the first schematic: Timekeeper circuits on the Relic grid
    Seven sheets generated by scripts/harp_schematic from a circuit spec and
    net-traced against it (195 parts, 48 global nets, no shorts or single-pin
    nets): Controls and LEDs, MCU (STM32H750VBT6 LQFP-100, W25Q128 on QUADSPI
    bank 2), Power (TPS54202 + NCP718, as the Timekeeper), Jacks and Bypass
    (four jacks, Relic relay bypass, LED drivers, footswitches, expression
    buffer), Codec (AK4621EF, OPA2348 VCOM buffers), ADC Driver (THS4522) and
    Analog In and Out (OPA1656 buffer, OPA1688 difference amplifiers).
    Replaces the Relic Power and IO sheet; removes its regulator footprints
    from the board and detaches the remaining footprints for r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
    [ADC Driver.kicad_sch, Analog In and Out.kicad_sch, Codec.kicad_sch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]
2026-10-05 Drop the THS4522: drive the ADC from the input OPA1656
    The spare half of the input OPA1656 becomes a unity inverter about VCOM_A,
    so U701A drives AINL+ and U701B drives AINL- through the THS4522 stage's
    own output filter (40.2R per leg, 2.7n across, 100p to GND). Removes the
    ADC Driver sheet (THS4522 and 16 passives) and, with it, the Timekeeper's
    floating IN_N defect. 6 sheets, 183 parts, net check clean.
    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
    [ADC Driver.kicad_sch, Analog In and Out.kicad_sch, Codec.kicad_sch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]
2026-10-05 Restore the THS4522 ADC driver
    Reverts c744d80. The THS4522 is designed for the single 5 V analog rail
    (rail-to-rail output, VOCM sets the output common mode at the codec's VCOM),
    which is why the Timekeeper uses it; the OPA1656 sits at the bottom of its
    supply range there. The reference leg stays tied to VCOM_A, the fix from the
    Timekeeper's input noise review (H1), not left floating.
    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
    [ADC Driver.kicad_sch, Analog In and Out.kicad_sch, Codec.kicad_sch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]
2026-10-05 Input buffer: OPA2365 and the Timekeeper's H2 fix
    The OPA1656's input range ends at (V+) - 2.25 V, 2.75 V on the 5 V rail,
    0.25 V above the 2.5 V bias, while hard-played guitar peaks reach about
    +/-1.5 V at the buffer (from the Timekeeper's measured levels). U701 becomes
    an OPA2365 (zero-crossover rail-to-rail input, 2.2-5.5 V, pin-compatible),
    so the bias, the THS4522 and the 5 V rail stay as they are.
    H2 from the Timekeeper's input noise review: R705 5k1 -> 49.9R and
    R602 1k -> 1.05k, so the THS4522 runs at gain 1 with balanced legs.
    Docs record the decision and the matching Timekeeper rework.
    Claude-Session: https://claude.ai/code/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
    [ADC Driver.kicad_sch, Analog In and Out.kicad_sch]
2026-10-05 ADC driver gain 0.59: R603/R604 620R
    Same choice as the Timekeeper: at 620R a 4.8 Vpp input, the most the
    OPA2365 buffer can swing on 5 V, just reaches ADC full scale, so guitar and
    synth both reach the ADC cleanly. Docs updated; merges main (firmware
    requirements draft) with the README conflict resolved.
    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
    [ADC Driver.kicad_sch]
2026-10-05 Follow The Alchemist's shared parts: NMJ6HCD2 jacks, G6K-2F-Y relay, JLCPCB numbers
    - Jacks: Neutrik NMJ6HCD2 (JLCPCB HOOYA PJ-609BA, C309277); IN jack ring to
    GND as The Alchemist. PCB footprints copied from The Alchemist at its
    positions (origins 0.75/0.885 mm moved, nose axes unchanged).
    - Relay: Omron G6K-2F-Y DC5 (C2982926), Alchemist pinout; PCB footprint at
    its position.
    - Design and JLCPCB part numbers on the pots, relay drivers, LED drivers,
    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
    [ADC Driver.kicad_sch, Analog In and Out.kicad_sch, Codec.kicad_sch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]
2026-10-06 Bring the repository onto the Frogmouth folder standard
    Flatten hardware/ into the standard layout (docs/repo-structure.md in
    26-F01-0001_Frogmouth): hardware/kicad/ -> kicad/, hardware/gerbers/ ->
    Gerbers/. The generator's default output (build.py), its DSP-board
    source path (libcollect.py, which follows the DSP board's own move to
    kicad/), README, CLAUDE.md, bom/README.md and docs/pcb-plan.md follow.
    Add the baseline .gitignore (the repo had none) and stop tracking
    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
    [ADC Driver.kicad_sch, Analog In and Out.kicad_sch, Codec.kicad_sch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]
2026-10-06 Write the Harp design report (Z04-R-0001-A)
    The app's generated draft described a different pedal (a harmonica
    emulator with invented specifications: 1 MOhm input, 50 mA, reverb and
    pitch-modulation 'core effects') and carried Markdown inside LaTeX.
    Replace its chapters with a report written from this repo's working
    record -- docs/design-brief.md, docs/pcb-plan.md,
    docs/firmware-requirements.md and the generated schematic:
    1 Executive summary and status (schematic generated, not ERC'd;
    board seeded; no firmware; nothing measured)
    2 Concept and requirements: signal path, engine, controls, bypass,
    firmware requirement groups
    3 Hardware architecture and the twelve recorded decisi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
2026-10-06 Face as The Alchemist's: four knobs, three ON-ON-ON toggles
    The Relic's six knobs and three toggles did not fit the four jacks: the
    outer lower-row pots' pins sat on the upper jacks' rear pads and the outer
    toggles over the jack bodies.
    - Knobs: Mix, Sustain, Strings (row +38), Jawari (0, +13); RV104/RV106
    removed. Pots on PA0, PA1, PA2, PA4.
    - Toggles: Taiway 100-DP6-T200B1M2QE ON-ON-ON (The Alchemist's part),
    Tuning Follow/Key/Drone and Brightness Dark/Warm/Glassy at (+-20, +13),
    Retune Snap/Glide/Lock at (0, -5); two MCU inputs each (PE11-PE15, PB10).
    - PCB: toggles on the Alchemist footprint, RV104/RV106 deleted, bypass
    footswitch on R2816 pads, R405/D402 moved off J403's rear p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
    [ADC Driver.kicad_sch, Analog In and Out.kicad_sch, Codec.kicad_sch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]
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2026-10-07 Wire the Power sheet directly
    Hand layout in scripts/harp_schematic/layouts/power.py; every in-sheet
    connection is a wire, global labels only for nets that leave the sheet,
    Oswald on every font, power references hidden and numbered. Netlist checked
    pin by pin against harp_spec.py.
    Claude-Session: https://claude.ai/code/session_01TSLeRh1r4phcduukMUZ1ao
    [Power.kicad_sch]
2026-10-07 Wire the ADC Driver sheet directly
    Hand layout in scripts/harp_schematic/layouts/adc_driver.py; every in-sheet
    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
    [ADC Driver.kicad_sch]
2026-10-07 Wire the Analog In and Out sheet directly
    Hand layout in scripts/harp_schematic/layouts/analog_in_and_out.py; every in-sheet
    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
    [Analog In and Out.kicad_sch]
2026-10-07 Wire the Codec sheet directly
    Hand layout in scripts/harp_schematic/layouts/codec.py; every in-sheet
    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
    [Codec.kicad_sch]
2026-10-07 Wire the Controls and LEDs sheet directly
    Hand layout in scripts/harp_schematic/layouts/controls_and_leds.py; every in-sheet
    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
    [Controls and LEDs.kicad_sch]
2026-10-07 Wire the Jacks and Bypass sheet directly
    Hand layout in scripts/harp_schematic/layouts/jacks_and_bypass.py; every in-sheet
    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
    [Jacks and Bypass.kicad_sch]
2026-10-07 Wire the MCU sheet directly
    Hand layout in scripts/harp_schematic/layouts/mcu.py; every in-sheet
    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
    [MCU.kicad_sch]
2026-10-07 Top sheet drawn as a coloured block diagram; embed the title block and Oswald
    Sheet blocks coloured by domain inside AUDIO / ANALOG, CONTROL / DIGITAL and
    POWER frames, a parts summary in each block, every inter-sheet net as a
    coloured arrowed line (drawing only; the sheets connect through global
    labels), a legend, and the AW Titleblock 2025 worksheet and Oswald Regular /
    Bold embedded as on The Relic's top sheet.
    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
    [The Harp.kicad_sch]
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2026-10-08 Stereo single-ended input and an OLED display
    IN becomes a TRS jack (tip left, ring right) with a second OPA2365 buffer and
    THS4522 channel B into the AK4621EF's AINR; the codec inputs are no longer
    parked. A mono plug is detected by the right channel reading silence. The
    twelve note LEDs and R107-R118 give way to a 0.91 in I2C OLED connector (J408,
    PB6/PB7) with 4.7k pull-ups. Schematic regenerated (190 parts, netlist OK on
    all sheets); design brief, PCB plan, firmware requirements and the design
    report updated. The PCB still carries the old LED footprints until Update PCB
    from Schematic is run in KiCad.
    Claude-Session: https://clau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
    [ADC Driver.kicad_sch, Analog In and Out.kicad_sch, Codec.kicad_sch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]
2026-10-08 OLED mounting: face cut-out, module-to-PCB drawing, window at Y -20
    Window 24.4 x 7.6 mm (Tayda rectangular cut) centred at face (0, -20): the
    Retune toggle's courtyard reaches Y -12.45, so a 12.5 mm module at -18 would
    sit on it. The module hangs from the face in a 3D-printed carrier bonded with
    VHB and is wired to J408 at about (-24, -20). K401 is flagged to move 2.5 mm
    towards the heel at placement (1.65 mm clearance under the module otherwise).
    Drawings in docs/images, generated by scripts/oled_drawings/oled_drawings.py.
    Also renumbers the 2026-10-08 decisions to 14 and 15: 12 and 13 already
    existed in the design brief.
    Claude-Ses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
    [ADC Driver.kicad_sch, Analog In and Out.kicad_sch, Codec.kicad_sch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]
2026-10-08 Move K401 out from under the OLED module
    K401 from PCB (143.4, 134.85) to (143.9, 137.0), face (-4.6, -32.0): 2.15 mm
    towards the heel and 0.5 mm right. Its courtyard now ends 0.5 mm short of the
    module edge (Y -26.25), 0.12 mm clear of Q402 and 0.75 mm from the board edge;
    a straight 2.5 mm move would have overlapped Q402. No tracks to move (board
    unrouted). Drawing and docs updated.
    Claude-Session: https://claude.ai/code/session_016hDejPHPgG8auBLMyByYZK
    [The Harp.kicad_pcb]
2026-10-08 Place J408 on the PCB for the OLED lead
    JST SH SM04B-SRSS-TB footprint (KiCad library) added to the board at PCB
    (125.0, 122.5), rotation 90, face (-23.5, -17.5): pads in a column at face
    X -25.5, cable entry facing the module's pad end. Linked to the schematic
    symbol (path /Controls and LEDs/J408) with nets GND, +3V3, OLED_SCL,
    OLED_SDA, so Update PCB from Schematic keeps it. Courtyard 1.22 mm from the
    board edge and 0.62 mm clear of J405. Drawing and docs updated.
    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
    [The Harp.kicad_pcb]
2026-10-08 Sync the PCB to the schematic and park the new parts
    Done by script (no KiCad in this session), the equivalent of Update PCB from
    Schematic:
    - removed D101-D112, R109-R118 (note LEDs) and R502/R503 (parked AINR)
    - added 23 footprints: the stereo input parts (R607-R612, C611-C618,
    R720-R722, C708, C709, D407), C104, and IC501 / U202, which were missing
    from the board; library footprints cloned from this board or the
    Timekeeper's, rotation normalised, fresh UUIDs, linked to their symbols
    - updated values and pad nets on 13 footprints (U601 channel B, U701B,
    IC501 inputs, ADC_L nets, J402 ring, U201 PB6/PB7 and freed PD0-PD11,
    R107/R108 now 4.7k pull-ups)
    Checked: all 181 footprints m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
    [The Harp.kicad_pcb]
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2026-10-08 Two-sided placement: fix the three weak spots
    37 parts that gain nothing from the top move to the bottom, where the jack
    bodies leave room (above the upper jacks, the centre strip, the heel
    strip): the relay and its driver under U201, the LED and footswitch
    drivers, the expression buffer, the pot RC filters, and the SWD and
    footswitch pads (bare copper). That frees the middle of the top:
    - codec next to the MCU's SAI pins: SAI 50-55 mm -> 15-17 mm
    - ADC driver next to the input buffers, feedback networks compact
    (worst 39 -> 18 mm), anti-alias caps at the codec's input pins
    - input path: IN 35 -> 28 mm, relay to buffer 22 -> 11 mm
    Remaining long run: the driven ADC pair to the codec (~30 m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
    [The Harp.kicad_pcb]
2026-10-09 Option 1: OLED at (0, -5), Retune toggle at (0, -24), re-placed board
    Face: the OLED window moves up into the middle of the face under the
    Jawari knob, the Retune toggle moves down to (0, -24) (design brief,
    decision 16). The module is mounted turned round, pads at its right end;
    the firmware flips the image.
    Board: with the toggle out of the middle the H750 moves up to (0, -7),
    under the screen. Codec beside it next to the SAI pins (11-16 mm), ADC
    driver below the codec (left ADC pair 17-19 mm), input buffers and flash
    on the right next to IN, output stages and VCOM buffers between the pot
    rows, J408 at the module's right end (22, -3.5). Bottom side as before,
    relay now under U201 at (0, -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
    [ADC Driver.kicad_sch, Analog In and Out.kicad_sch, Codec.kicad_sch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]
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2026-10-09 Fix PCB load error: D114's fab point had an angle and was left off the board
    (point (at x y)) takes no angle; the placement script gave it one and, since
    KiCad keeps points in board coordinates, left it at x=271 when D114 moved.
    Put it back at D114 + (1.27, 0). write_pos.py now moves points with their
    footprint and leaves them out of the angle rewrite.
    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
    [The Harp.kicad_pcb]
2026-10-10 Routing tools: grid maze router with rip-up and history cost, track straightening
    fill.py finishes open connections on a 0.05 mm grid (F/B, In2 for rails),
    with rip-up of signal tracks and vias and PathFinder history cost; --fresh
    reroutes every signal from scratch, shortest nets first. smooth.py
    straightens its staircase tracks with exact clearance checks. NRST routed at
    0.1016 mm to escape the SWD needle pads. Board unchanged: neither pass
    completes the board yet (24-33 connections open round the MCU).
    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
2026-10-10 In2: the rails as pours instead of tracks
    The +3V3, +5V and +9V tracks on In2.Cu are removed; each rail is now a zone
    (4 zones, solid connection, 0.2 mm clearance, smaller zone on top). The old
    tracks served as the backbone: the rest of In2 goes to the nearest rail, with
    a 0.24 mm gap between rails. The buck's +3V3 output is joined to the rest by a
    5 mm jumper on F.Cu beside the codec. check.py counts pours as copper of
    their net; render.py draws them. 29 connections left (signals and VDDA).
    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
    [The Harp.kicad_pcb]
2026-10-10 In2 pours drawn as blocks with 45 degree corners
    pour_plan.py replaces the organic pours: +9V a band and blocks with 0.6 mm
    bars, +5V and +3V3 from a smoothed nearest-pin map rounded with a 1.2 mm
    bevel, bus bars along the old tracks where a rail's blocks are not joined,
    and a 1 mm +5V trunk along the right edge from the LDO to U701. Five zones
    instead of 19; no jumper needed. Every rail pin joined and inside its own
    winning zone in the imitated fill.
    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
    [The Harp.kicad_pcb]
2026-10-10 Revert In2 pours: the rails go back to tracks
    Reverts PR #15. The block-style pours were not manufacturable. The board is
    as before it: +3V3 / +5V / +9V as 0.5 / 0.6 mm tracks on In2.Cu, 1546 tracks,
    302 vias, 32 connections open. The pour scripts and the docs on them are
    removed with it.
    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
    [The Harp.kicad_pcb]
2026-10-10 Fix schematic load error and restore the board
    KiCad 10 rejects (justify center): centre is the default and is not a
    valid justify token. The generator (schgen._eff) now drops it, and the
    266 occurrences are removed from the seven sub-sheets.
    The pushed board (90ddafa) came from an Update PCB from Schematic run
    while only part of the schematic loaded: it removed 164 footprints and
    moved the tracks and vias onto unconnected or empty nets. The board is
    restored from 53d04bc. The net class reordering in the project file is kept.
    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
    [ADC Driver.kicad_sch, Analog In and Out.kicad_sch, Codec.kicad_sch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]
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2026-10-10 Power section re-placed and re-routed, Alchemist widths, 0/45/90 everywhere
    The buck placement from 6a5f05a stays. power.py re-places and routes the
    rest of the power section: the DC input on one bus at y = 56 (TVS hanging
    off it, FB301 with its two caps under its pads, D302, +9V straight down to
    the LDO and onto In2) and the LDO in a second row at y = 63 flowing back
    towards the +5V via, input parts at the input, output caps together at the
    output. The buck's feedback divider moves to a column beside the FB pin;
    the SW node to the BOOT cap crosses on a short B.Cu link instead of In2.
    rail.py joins the one open +5V connection on In2, hopping the +3V3 and
    +9V rails with two via pairs. widths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
    [The Harp.kicad_pcb]
2026-10-10 Digital tracks 0.2 mm
    No logic line on the board needs 0.254, and 0.2 passes between the MCU's
    0.5 mm pads, which is where the digital escapes are tight. Every digital
    segment at 0.254 is narrowed to 0.2 (227); nothing moves. The Digital net
    class in the project follows, 0.2 and 0.1524 join the width list, and
    W201's SWD nets are classed digital (KiCad mangled their "{slash}" names
    in the pattern list; they are wildcarded now).
    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
    [The Harp.kicad_pcb]
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
